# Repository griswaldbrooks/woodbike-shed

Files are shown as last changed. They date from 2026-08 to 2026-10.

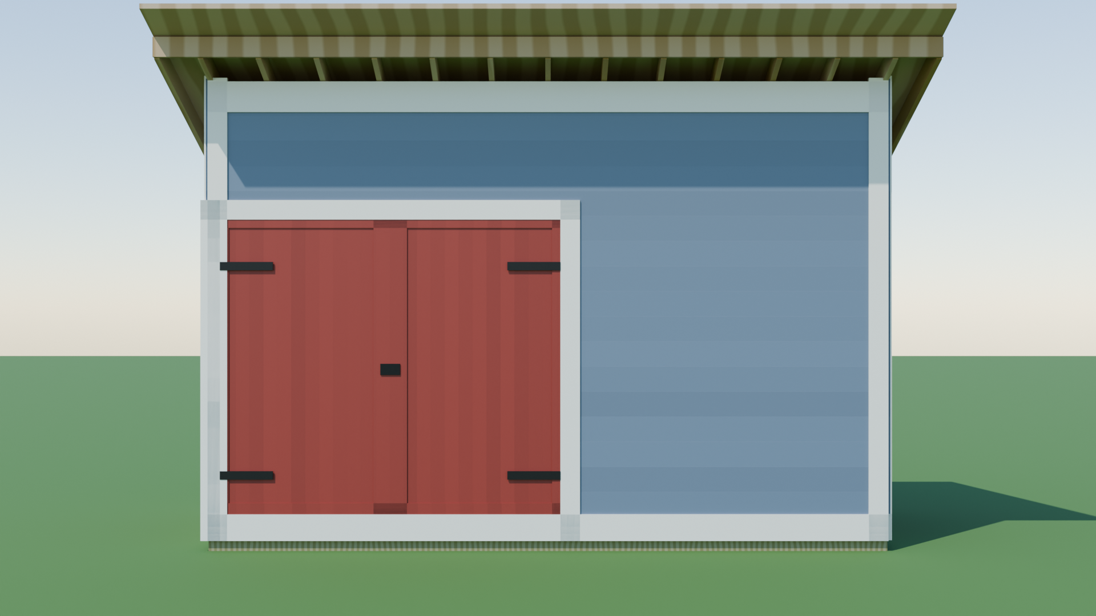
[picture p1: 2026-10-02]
blender/renders/skin/skin_front.png

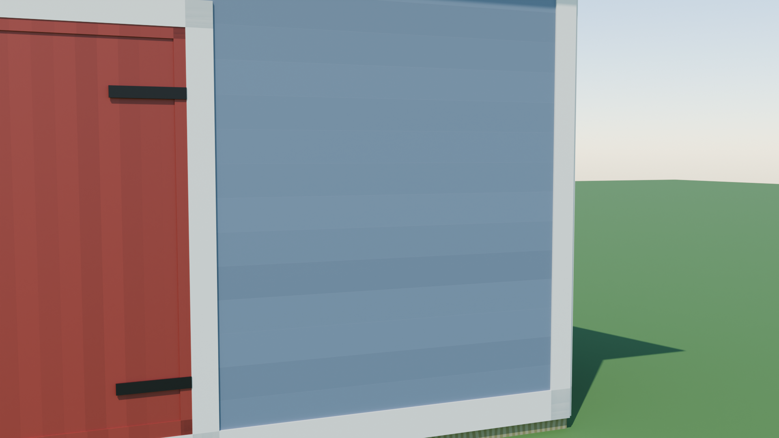
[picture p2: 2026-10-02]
blender/renders/skin/skin_door.png

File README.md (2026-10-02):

# woodbike-shed

Tooling to pull a BOM / cut list from the Onshape model of the bike shed and
prep lumber-yard RFQs.

## Build guide

The current build guide is the multi-page guide in
[`docs/guide/`](docs/guide/index.md) (PDF via `docs/guide/build-pdf.sh`).
[`docs/build-guide.html`](docs/build-guide.html) is the archived v1 single
page (6 ft shell, old door plan, old roof overhang) — kept as a record, not
build reading.

## Model as code

[`cad/`](cad/README.md) re-derives the whole shed model as build123d code
from this repo's audit data (no Onshape API calls) and exports per-part STEP
plus one named `blender/scene.glb` for renders. Build: `.venv/bin/python -m
cad.build` — verify (run after every change): `.venv/bin/python -m cad.verify`.

## Viewing (OCP CAD Viewer)

`view.py` sends the assembled model to the OCP CAD Viewer with a part tree
that mirrors `CUT_LIST.md` (one group per section, real cut-list labels):

    ~/.venvs/woodbike-shed/bin/python view.py   # from the repo root

Run it inside VS Code with the *OCP CAD Viewer* extension. `ocp_vscode` is a
viewer-side extra, deliberately not in `requirements.txt` — it lives in the
captain's `~/.venvs/woodbike-shed` venv (any venv with `ocp_vscode` works).

## Onshape document

- Name: *wood bike shed*
- URL: <https://cad.onshape.com/documents/24d3743de768051f7ae10bb3/w/4c0f1b0cf9df2e322f841b94/e/5730975eb353b57bac8d52c4>

## Credentials

API keys are stored in `~/.config/onshape/credentials` (mode `0600`, outside
this repo) as:

```
ONSHAPE_ACCESS_KEY=...
ONSHAPE_SECRET_KEY=...
```

Never commit these. The `.gitignore` blocks common credential filenames anyway.

## Key files

- [`CUT_LIST.md`](CUT_LIST.md) — full cut list grouped by section (skids,
  floor, walls, roof), with stock-length optimization.
- [`order_list.csv`](order_list.csv) — quote-ready CSV: lumber, treatment,
  stock length, qty.
- [`OUTSTANDING_ISSUES.md`](OUTSTANDING_ISSUES.md) — open items before
  sending quotes (stock availability, species, pre-cuts, waste factor, etc.).
- [`cad/`](cad/README.md) — model-as-code rebuild (build123d), per-part STEP
  exports in `step/`, Blender scene in `blender/scene.glb`.

## Scripts

- `scripts/onshape.py` — signed-request helper against `cad.onshape.com/api/v6`.
  Usage: `python3 scripts/onshape.py GET /api/v6/documents/{did}`.
- `scripts/fetch_bboxes.py` — pulls world-axis-aligned bounding boxes for every
  part in the Part Studio. Writes `scripts/bboxes.json`.
- `scripts/fetch_oriented_dims.py` — uses FeatureScript eval to get true
  oriented bounding boxes (correct for tilted parts like rafters). Writes
  `scripts/oriented_dims.json`.
- `scripts/build_cut_list.py` — builds `CUT_LIST.md` and `order_list.csv`
  from oriented dims. Classifies lumber, groups by section, assigns treatment
  (PT/KD), runs stock-length optimization with FFD bin packing.
- `scripts/verify_groups.py` — groups parts by name and flags any
  within-group dimension variance. Useful for sanity-checking the
  model after bulk-renaming.
- `scripts/fs_probe.py` — lightweight FeatureScript REPL for debugging.

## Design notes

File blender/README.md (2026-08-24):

# blender/ — headless render pipeline for the shed

`scene.glb` (273 named parts — 118 framing + 155 finish — from `cad/build.py`,
names = CUT_LIST.md labels with an `NNN ` instance prefix) +
`build_scene.py`, which turns it into a lit, materialled scene and renders
it. Nothing hand-placed: cameras, ground and sun derive from the imported
bounding box, so re-running survives model changes. `build_scene.py` drops
the `finish ` parts after import (both modes): the Blender scenes stay
framing-only presentations; the modeled finish lumber is viewed via
`view.py` (siding/trim/doors tints below).

## Regenerate (headless)

Blender is not part of the repo. Any Blender 4.x works; on this box it lives
in the task worktree scratch:

```
./.scratch/blender-4.5.12-linux-x64/blender --background --python blender/build_scene.py            # -> shed_scene.blend
./.scratch/blender-4.5.12-linux-x64/blender --background --python blender/build_scene.py -- --render  # + renders/ (Cycles 1920x1080)
./.scratch/blender-4.5.12-linux-x64/blender --background --python blender/build_scene.py -- --skin --render  # dressed variant -> shed_skin.blend + renders/skin/
```

`--render` renders all four saved cameras into `blender/renders/`.
GPU (OptiX/CUDA) is used when present, CPU otherwise.

## Skin mode (`--skin`) — render dressing, NOT modeled lumber

`--skin` layers a "finished shed" look over the framing for presentation
renders, matching the captain's reference photo: blue-gray horizontal lap
siding, white corner boards / door casings / frieze / skirt, barn-red plank
doors with black strap hinges and latches, and a natural-wood roof deck with
exposed rafter tails. Doors follow the model's actual framed openings (front
single + front double + right single), not the photo's door count.

Everything is procedural boxes/prisms aligned to wall planes and openings
read off the imported parts' world bboxes (`skin_layout()`), so like the
cameras it re-derives from `scene.glb`. `scene.glb` and the framing-only /
colorized modes are untouched; the framing model stays the source of truth.
Saves `shed_skin.blend` and renders four views (front-left 3/4 at the
reference angle, back-right, straight-on front, double-door close-up) into
`blender/renders/skin/`.

## Material-by-name-group

`group_for()` maps the cut-list label (after stripping the `NNN ` prefix) to
one material, checked in order: `sub floor osb` → deck; `skid` (incl. skid
sister); `joist` (rim/floor) → floor_frame; `rafter`; `fascia`;
`rake board` → rake; `plate`/`header` (incl. rake wall top plates) → plates;
anything else (studs, king/jack/cripple) → studs. Each group gets a distinct
wood-tinted hue (annotated-product-shot style, legend under Scene).

Each material is a Principled BSDF with a per-group base color/roughness, a
subtle Wave-texture grain in object space, and per-object brightness jitter
(Object Info → Random) so boards read individually. Tones are in the
`MATERIALS` dict at the top of `build_scene.py`.

## Scene

- Ground plane at the lowest board; Nishita sky (sun disc off) as ambient.
- One SUN lamp from front-left (~53° elevation); the sky's sun azimuth is
  matched to it.
- Cameras: `cam_front_left` / `cam_back_right` (3/4 product shots),
  `cam_interior` (axial view down the bay from the right-end door opening),
  `cam_elevation` (straight-on front, orthographic).
- Cycles 256 samples + denoise, AgX (medium-high contrast look).

### Group color legend

Approximate on-screen tints (base colors from `MATERIALS` in
`group_colors.py`, shared with `view.py` so the OCP CAD Viewer shows the
same hues; renders here are the ground truth):

| Group | Tint | Parts |
|---|---|---|
| skid | dark olive `#8E8B69` | skid (two continuous 16' 4x4) |
| floor_frame | dark amber `#A28159` | rim joist, floor joist |
| deck | golden `#CBBC81` | sub floor osb |
| studs | pale blond `#D4BCAD` | studs, king/jack/cripple studs |
| plates | honey orange `#CBA261` | plates, headers |
| rafter | cedar red `#C29079` | rafter |
| fascia | driftwood gray `#A2A4AA` | back/front fascia |
| rake | rosewood plum `#AA8195` | rake boards |
| siding | blue-gray `#6C7C90` | finish siding (view.py only) |
| trim | white `#E7E6E0` | finish corner/frieze/skirt/casings |
| doors | barn red `#906054` | finish door planks/rails |

## Known limits

- The Blender scenes render the framing only: `scene.glb` carries the modeled
  finish parts (siding/trim/doors, see `cad/README.md`) but `build_scene.py`
  drops them; `--skin` layers its own procedural dressing for the finished
  look. No roof sheathing beyond the OSB floor deck (matches CUT_LIST.md
  framing scope).

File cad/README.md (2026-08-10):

# cad/ — bike shed model-as-code

The Onshape model re-derived as code (build123d), per the scout report
`data/woodbike-shed-cadlib-scout/report.md`. Geometry flows one way out:
per-part STEP (exact record, occasional manual Onshape import) and one named
GLB for Blender renders. **No Onshape API calls anywhere in this package** —
the repo's audit files are the only model source.

## Stack (pinned in ../requirements.txt)

- Python 3.12, `build123d==0.11.1` (OCCT via cadquery-ocp-novtk 7.9.3), `trimesh`
- Setup: `uv venv --python 3.12 .venv && uv pip install -r requirements.txt`

## Commands (from repo root)

| Command | Effect |
|---|---|
| `.venv/bin/python -m cad.build` | Rebuild all parts, write `step/*.step` + `blender/scene.glb` |
| `.venv/bin/python -m cad.verify` | Assertion harness — **run after every change** |

## Sources of truth

- `scripts/oriented_dims.json` — part names (== CUT_LIST.md labels) + edge dims
- `scripts/bboxes.json` — world bounding boxes (placement)
- `CUT_LIST.md` / `OUTSTANDING_ISSUES.md` — cross-checks and open items
- Roof pitch is *derived from the plate solids* (`cad.common.roof_ref`:
  front double top plate bottom at the front wall inner face -> back double
  top plate top at the back wall inner face), sanity-checked against the
  documented 24.375/65 slope (~20.56°). The audit data reflects the
  2026-08-10 restud to 92-5/8" pre-cut studs (`scripts/restud_92_5_8.py` —
  full derivation record); the pre-restud slope was 24/65 (~20.26°, see
  MANUAL_COMPLETION.md). Wall-height edits propagate: seats, kicks, mitres
  and the pitch all re-derive from the plates.

## Layout

One module per shed section; `cad/common.py` loads the audit data and places
parts. Axis-aligned parts are AABB boxes (`place_box`); the roof/rake
members (rafters, rake boards, rake plates, rake studs) are exact YZ-profile
prisms (`prism_yz`, `roof_ref`) carrying the audited birdsmouth/seat/kick/
mitre/end cuts, anchored on their own world coordinates (never re-centered
on an AABB):

`skids.py` `floor.py` `walls_front.py` `walls_back.py` `walls_side.py`
`walls_rake.py` `roof.py` → orchestrated by `build.py`, checked by `verify.py`.

Finish lumber (captain 2026-08-10: modeled for real, SEPARATE order list) is
`siding.py` (1x8 lap courses, rabbet-nested, rake-cut tops), `trim.py`
(skirt/corners/frieze/casings), `doors.py` (board-and-batten leaves over the
framed openings) → `build.py build_finish()`, checked by the same
`verify.py` run (volumes, layer planes, envelope, zero interference against
the framing too). Their heights derive from `common.finish_layout` (audit
bboxes + roof_ref); only product dims are constants. Labels use a `finish `
prefix so `scripts/build_cut_list.section_for` files them under the Finish
sections and `scripts/build_finish_cut_list.py` orders them separately.

Naming scheme: every part's `.label` matches CUT_LIST.md exactly. STEP
filenames and glTF node names are `NNN <label>` (instance number prefix for
uniqueness — group names repeat, e.g. 14 × "back wall studs").

## build123d trap rules (learned empirically — do not break)

1. **Location tuple form only**: `Location((x,y,z), (rx,ry,rz))`.
   `Location(Pos(...), Rot(...))` constructs without error but **silently
   drops the rotation** — parts build in the wrong pose. All placement in
   `common.py` uses the tuple form; keep it that way.
2. **`export_step` takes ONE shape** — pass parts one at a time, never a
   list (`'list' object has no attribute 'wrapped'`). Also: build123d
   `Compound` drops child labels, so a single-file named STEP assembly is
   not available; per-part files are the workable path.
3. build123d `export_gltf` writes JSON glTF even for `.glb` unless
   `binary=True` — this repo exports meshes via trimesh instead (always
   binary GLB, names verified in Blender 4.5 LTS: one selectable object per
   part).
4. **build123d builds in mm**: `prism_yz` takes inch profiles and scales
   them at the boundary. Feeding raw inch points to `Polygon` builds a part
   25.4x too small without any error.

## Pending captain decisions (TODO seams, do not decide unilaterally)

(none open)

Resolved seams (kept for the record):
- **Doors/siding/trim** — implemented 2026-08-10 as real parts
  (`siding.py`/`trim.py`/`doors.py`) on a separate order list
  (`order_list_finish.csv`), per the captain's decision; hardware stays line
  items only.
- **Birdsmouth/trim cuts in code** — implemented 2026-08-10
  (`roof.py`/`walls_rake.py` prisms, `verify.py` seating gate). The old
  rectangular-stock approximation silently interpenetrated both double top
  plates by up to 1.5"; diagnosis record: firstmate report
  `woodbike-shed-birdsmouth-scout/report.md`.
- **Rake-plate end/nose cuts** — implemented with the plate prisms.
- **Skid composites** — superseded by the captain's 2026-08-10 skid
  redesign (two continuous 16' 4x4 lines; OUTSTANDING_ISSUES.md "Skid
  redesign").

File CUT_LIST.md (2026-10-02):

# Bike shed cut list

Source: Onshape "wood bike shed" Part Studio 1 audit data, as re-derived
locally 2026-08-10 for the 92-5/8" pre-cut stud decision
(scripts/restud_92_5_8.py) and the captain's skid redesign (two
continuous 16' 4x4 lines, sisters dropped), then 2026-08-23/24 for the
7 ft depth + adopted door plan (scripts/depth7ft_2door.py + scripts/
left_main_door.py: barn 8 ft front, LEFT rake-wall 64 in MAIN entry,
RIGHT rake-wall 64 in brewery; skids bear direct on the gravel pad).
The Onshape model still carries the pre-decision geometry. Actual dimensions.

- **Yard: Hingham Lumber** — KD framing species **SPF #2**; stocks 16' 2x4,
  16' 4x4 and true 20' 2x6. Quantities are EXACT (0% overage) per the
  captain — plan a follow-up run for shortages.
- **PT** = pressure-treated, ground-contact rated (skids + floor system)
- **KD** = kiln-dried dimensional lumber, framing grade, SPF #2
- Back/left/right wall studs: **88-1/8" pre-cut** studs (7 ft depth:
  plate tops 92-5/8" above the deck; roof re-derived about the
  unchanged front wall). Front wall studs stay 118-1/2" (tall wall).
- Saw kerf allowance: 1/8" per cut (used in stock-length optimization)

## Skids

| Qty | Lumber | Treatment | Length | Name |
|---:|:---|:---:|---:|:---|
| 2 | 4x4 | PT | 16′ 0″ (192″) | skid |

## Floor

| Qty | Lumber | Treatment | Length | Name |
|---:|:---|:---:|---:|:---|
| 2 | 2x6 | PT | 16′ 0″ (192″) | rim joist |
| 14 | 2x6 | PT | 6′ 9″ (81″) | floor joist |
| 4 | OSB 3/4" 4x8 (half sheets used) | — | 84″ × 48″ | sub floor osb |

## Back wall

| Qty | Lumber | Treatment | Length | Name |
|---:|:---|:---:|---:|:---|
| 1 | 2x4 | KD | 16′ 0″ (192″) | back wall bottom plate |
| 1 | 2x4 | KD | 16′ 0″ (192″) | back wall top plate |
| 1 | 2x4 | KD | 15′ 5″ (185″) | back wall double top plate short |
| 13 | 2x4 | KD | 7′ 4.125″ (88.125″) | back wall studs |

## Front wall

| Qty | Lumber | Treatment | Length | Name |
|---:|:---|:---:|---:|:---|
| 1 | 2x4 | KD | 16′ 0″ (192″) | front wall bottom plate |
| 1 | 2x4 | KD | 16′ 0″ (192″) | front wall double top plate |
| 1 | 2x4 | KD | 16′ 0″ (192″) | front wall top plate |
| 8 | 2x4 | KD | 9′ 10.5″ (118.5″) | front wall king studs |
| 3 | 2x4 | KD | 8′ 3″ (99″) | front wall headers |
| 2 | 2x4 | KD | 6′ 10.5″ (82.5″) | front wall jack studs |
| 5 | 2x4 | KD | 2′ 7″ (31″) | front wall cripple studs |

## Left wall

| Qty | Lumber | Treatment | Length | Name |
|---:|:---|:---:|---:|:---|
| 1 | 2x4 | KD | 7′ 8.625″ (92.625″) | left side wall studs |
| 1 | 2x4 | KD | 7′ 4.125″ (88.125″) | left side wall studs |
| 2 | 2x4 | KD | 6′ 10.5″ (82.5″) | left wall jack studs |
| 3 | 2x4 | KD | 5′ 7″ (67″) | left wall headers |
| 1 | 2x4 | KD | 5′ 4.728″ (64.728″) | left wall top plate |
| 1 | 2x4 | KD | 5′ 0.728″ (60.728″) | left wall double top plate |
| 1 | 2x4 | KD | 0′ 6.5″ (6.5″) | left wall bottom plate long |
| 1 | 2x4 | KD | 0′ 6.5″ (6.5″) | left wall bottom plate short |
| 3 | 2x4 | KD | 0′ 5.125″ (5.125″) | left wall cripple studs |
| 1 | 2x4 | KD | 0′ 3.5″ (3.5″) | left wall double top plate |

## Right wall

| Qty | Lumber | Treatment | Length | Name |
|---:|:---|:---:|---:|:---|
| 1 | 2x4 | KD | 7′ 8.625″ (92.625″) | right wall studs |
| 1 | 2x4 | KD | 7′ 4.125″ (88.125″) | right wall studs |
| 2 | 2x4 | KD | 6′ 10.5″ (82.5″) | right wall jack studs |
| 3 | 2x4 | KD | 5′ 7″ (67″) | right wall headers |
| 1 | 2x4 | KD | 5′ 4.728″ (64.728″) | right wall top plate |
| 1 | 2x4 | KD | 5′ 0.728″ (60.728″) | right wall double top plate |
| 1 | 2x4 | KD | 0′ 6.5″ (6.5″) | right wall bottom plate long |
| 1 | 2x4 | KD | 0′ 6.5″ (6.5″) | right wall bottom plate short |
| 3 | 2x4 | KD | 0′ 5.125″ (5.125″) | right wall cripple studs |
| 1 | 2x4 | KD | 0′ 3.5″ (3.5″) | right wall double top plate |

## Left rake wall

| Qty | Lumber | Treatment | Length | Name |
|---:|:---|:---:|---:|:---|
| 2 | 2x4 | KD | 7′ 7.125″ (91.125″) | left rake wall studs |
| 1 | 2x4 | KD | 6′ 10.236″ (82.236″) | left rake wall top plate |
| 1 | 2x4 | KD | 1′ 10.773″ (22.773″) | left rake wall studs |
| 1 | 2x4 | KD | 1′ 4.96″ (16.96″) | left rake wall studs |
| 1 | 2x4 | KD | 0′ 10.96″ (10.96″) | left rake wall studs |
| 1 | 2x4 | KD | 0′ 6.335″ (6.335″) | left rake wall studs |
| 1 | 2x4 | KD | 0′ 5.21″ (5.21″) | left rake wall studs |
| 1 | 2x4 | KD | 0′ 4.96″ (4.96″) | left rake wall studs |

## Right rake wall

| Qty | Lumber | Treatment | Length | Name |
|---:|:---|:---:|---:|:---|
| 2 | 2x4 | KD | 7′ 7.125″ (91.125″) | right rake wall studs |
| 1 | 2x4 | KD | 6′ 10.236″ (82.236″) | right rake wall top plate |
| 1 | 2x4 | KD | 1′ 10.773″ (22.773″) | right rake wall studs |
| 1 | 2x4 | KD | 1′ 4.96″ (16.96″) | right rake wall studs |
| 1 | 2x4 | KD | 0′ 10.96″ (10.96″) | right rake wall studs |
| 1 | 2x4 | KD | 0′ 6.335″ (6.335″) | right rake wall studs |
| 1 | 2x4 | KD | 0′ 5.21″ (5.21″) | right rake wall studs |
| 1 | 2x4 | KD | 0′ 4.96″ (4.96″) | right rake wall studs |

## Roof

| Qty | Lumber | Treatment | Length | Name |
|---:|:---|:---:|---:|:---|
| 1 | 2x6 | KD | 18′ 0″ (216″) | back fascia |
| 1 | 2x6 | KD | 18′ 0″ (216″) | front fascia |
| 1 | 2x6 | KD | 9′ 7.344″ (115.344″) | left rake board |
| 13 | 2x6 | KD | 9′ 7.344″ (115.344″) | rafter |
| 1 | 2x6 | KD | 9′ 7.344″ (115.344″) | right rake board |

## Stock-length order list

First-fit-decreasing bin packing, one pass per (lumber, treatment). For each group, the stock length shown minimizes total linear feet purchased. Kerf: 1/8" per cut.

### 2x4 KD — order **1 × 8′, 31 × 16′** (504.0 LF purchased, 493.9 LF cuts, 2.0% waste)

- Board 1 (16′): 192″ front wall top plate (Front wall)  — waste: 0.00″
- Board 2 (16′): 192″ front wall bottom plate (Front wall)  — waste: 0.00″
- Board 3 (16′): 192″ front wall double top plate (Front wall)  — waste: 0.00″
- Board 4 (16′): 192″ back wall bottom plate (Back wall)  — waste: 0.00″
- Board 5 (16′): 192″ back wall top plate (Back wall)  — waste: 0.00″
- Board 6 (16′): 185″ back wall double top plate short (Back wall); 6.5″ right wall bottom plate short (Right wall)  — waste: 0.38″
- Board 7 (16′): 118.5″ front wall king studs (Front wall); 67″ right wall headers (Right wall); 5.21″ right rake wall studs (Right rake wall)  — waste: 1.04″
- Board 8 (16′): 118.5″ front wall king studs (Front wall); 67″ right wall headers (Right wall); 5.21″ left rake wall studs (Left rake wall)  — waste: 1.04″
- Board 9 (16′): 118.5″ front wall king studs (Front wall); 67″ right wall headers (Right wall); 5.125″ right wall cripple studs (Right wall)  — waste: 1.12″
- Board 10 (16′): 118.5″ front wall king studs (Front wall); 67″ left wall headers (Left wall); 5.125″ right wall cripple studs (Right wall)  — waste: 1.12″
- Board 11 (16′): 118.5″ front wall king studs (Front wall); 67″ left wall headers (Left wall); 5.125″ right wall cripple studs (Right wall)  — waste: 1.12″
- Board 12 (16′): 118.5″ front wall king studs (Front wall); 67″ left wall headers (Left wall); 5.125″ left wall cripple studs (Left wall)  — waste: 1.12″
- Board 13 (16′): 118.5″ front wall king studs (Front wall); 64.728″ left wall top plate (Left wall); 6.5″ right wall bottom plate long (Right wall)  — waste: 2.02″
- Board 14 (16′): 118.5″ front wall king studs (Front wall); 64.728″ right wall top plate (Right wall); 6.5″ left wall bottom plate short (Left wall)  — waste: 2.02″
- Board 15 (16′): 99″ front wall headers (Front wall); 92.625″ right wall studs (Right wall)  — waste: 0.25″
- Board 16 (16′): 99″ front wall headers (Front wall); 92.625″ left side wall studs (Left wall)  — waste: 0.25″
- Board 17 (16′): 99″ front wall headers (Front wall); 91.125″ right rake wall studs (Right rake wall)  — waste: 1.75″
- Board 18 (16′): 91.125″ right rake wall studs (Right rake wall); 91.125″ left rake wall studs (Left rake wall); 6.5″ left wall bottom plate long (Left wall)  — waste: 3.00″
- Board 19 (16′): 91.125″ left rake wall studs (Left rake wall); 88.125″ back wall studs (Back wall); 10.96″ right rake wall studs (Right rake wall)  — waste: 1.54″
- Board 20 (16′): 88.125″ back wall studs (Back wall); 88.125″ back wall studs (Back wall); 10.96″ left rake wall studs (Left rake wall); 3.5″ left wall double top plate (Left wall)  — waste: 0.91″
- Board 21 (16′): 88.125″ back wall studs (Back wall); 88.125″ back wall studs (Back wall); 6.335″ right rake wall studs (Right rake wall); 6.335″ left rake wall studs (Left rake wall)  — waste: 2.70″
- Board 22 (16′): 88.125″ back wall studs (Back wall); 88.125″ back wall studs (Back wall); 5.125″ left wall cripple studs (Left wall); 5.125″ left wall cripple studs (Left wall); 4.96″ right rake wall studs (Right rake wall)  — waste: 0.04″
- Board 23 (16′): 88.125″ back wall studs (Back wall); 88.125″ back wall studs (Back wall); 4.96″ left rake wall studs (Left rake wall); 3.5″ right wall double top plate (Right wall)  — waste: 6.91″
- Board 24 (16′): 88.125″ back wall studs (Back wall); 88.125″ back wall studs (Back wall)  — waste: 15.62″
- Board 25 (16′): 88.125″ back wall studs (Back wall); 88.125″ back wall studs (Back wall)  — waste: 15.62″
- Board 26 (16′): 88.125″ right wall studs (Right wall); 88.125″ left side wall studs (Left wall)  — waste: 15.62″
- Board 27 (16′): 82.5″ front wall jack studs (Front wall); 82.5″ front wall jack studs (Front wall); 22.773″ right rake wall studs (Right rake wall)  — waste: 3.98″
- Board 28 (16′): 82.5″ right wall jack studs (Right wall); 82.5″ right wall jack studs (Right wall); 22.773″ left rake wall studs (Left rake wall)  — waste: 3.98″
- Board 29 (16′): 82.5″ left wall jack studs (Left wall); 82.5″ left wall jack studs (Left wall); 16.96″ right rake wall studs (Right rake wall)  — waste: 9.79″
- Board 30 (16′): 82.236″ left rake wall top plate (Left rake wall); 82.236″ right rake wall top plate (Right rake wall); 16.96″ left rake wall studs (Left rake wall)  — waste: 10.32″
- Board 31 (16′): 60.728″ left wall double top plate (Left wall); 60.728″ right wall double top plate (Right wall); 31″ front wall cripple studs (Front wall); 31″ front wall cripple studs (Front wall)  — waste: 8.17″
- Board 32 (8′): 31″ front wall cripple studs (Front wall); 31″ front wall cripple studs (Front wall); 31″ front wall cripple studs (Front wall)  — waste: 2.75″

### 2x6 KD — order **15 × 10′, 2 × 20′** (190.0 LF purchased, 180.2 LF cuts, 5.2% waste)

- Board 1 (20′): 216″ front fascia (Roof) — TOO LONG FOR 96"  — waste: 24.00″
- Board 2 (20′): 216″ back fascia (Roof) — TOO LONG FOR 96"  — waste: 24.00″
- Board 3 (10′): 115.344″ rafter (Roof) — TOO LONG FOR 96"  — waste: 4.66″
- Board 4 (10′): 115.344″ rafter (Roof) — TOO LONG FOR 96"  — waste: 4.66″
- Board 5 (10′): 115.344″ rafter (Roof) — TOO LONG FOR 96"  — waste: 4.66″
- Board 6 (10′): 115.344″ rafter (Roof) — TOO LONG FOR 96"  — waste: 4.66″
- Board 7 (10′): 115.344″ rafter (Roof) — TOO LONG FOR 96"  — waste: 4.66″
- Board 8 (10′): 115.344″ rafter (Roof) — TOO LONG FOR 96"  — waste: 4.66″
- Board 9 (10′): 115.344″ rafter (Roof) — TOO LONG FOR 96"  — waste: 4.66″
- Board 10 (10′): 115.344″ rafter (Roof) — TOO LONG FOR 96"  — waste: 4.66″
- Board 11 (10′): 115.344″ rafter (Roof) — TOO LONG FOR 96"  — waste: 4.66″
- Board 12 (10′): 115.344″ rafter (Roof) — TOO LONG FOR 96"  — waste: 4.66″
- Board 13 (10′): 115.344″ rafter (Roof) — TOO LONG FOR 96"  — waste: 4.66″
- Board 14 (10′): 115.344″ rafter (Roof) — TOO LONG FOR 96"  — waste: 4.66″
- Board 15 (10′): 115.344″ rafter (Roof) — TOO LONG FOR 96"  — waste: 4.66″
- Board 16 (10′): 115.344″ left rake board (Roof) — TOO LONG FOR 96"  — waste: 4.66″
- Board 17 (10′): 115.344″ right rake board (Roof) — TOO LONG FOR 96"  — waste: 4.66″

### 2x6 PT — order **7 × 14′, 2 × 16′** (130.0 LF purchased, 126.5 LF cuts, 2.7% waste)

- Board 1 (16′): 192″ rim joist (Floor) — TOO LONG FOR 168"  — waste: 0.00″
- Board 2 (16′): 192″ rim joist (Floor) — TOO LONG FOR 168"  — waste: 0.00″
- Board 3 (14′): 81″ floor joist (Floor); 81″ floor joist (Floor)  — waste: 5.88″
- Board 4 (14′): 81″ floor joist (Floor); 81″ floor joist (Floor)  — waste: 5.88″
- Board 5 (14′): 81″ floor joist (Floor); 81″ floor joist (Floor)  — waste: 5.88″
- Board 6 (14′): 81″ floor joist (Floor); 81″ floor joist (Floor)  — waste: 5.88″
- Board 7 (14′): 81″ floor joist (Floor); 81″ floor joist (Floor)  — waste: 5.88″
- Board 8 (14′): 81″ floor joist (Floor); 81″ floor joist (Floor)  — waste: 5.88″
- Board 9 (14′): 81″ floor joist (Floor); 81″ floor joist (Floor)  — waste: 5.88″

### 4x4 PT — order **2 × 16′** (32.0 LF purchased, 32.0 LF cuts, 0.0% waste)

- Board 1 (16′): 192″ skid (Skids) — TOO LONG FOR 96"  — waste: 0.00″
- Board 2 (16′): 192″ skid (Skids) — TOO LONG FOR 96"  — waste: 0.00″

### OSB 3/4" 4×8 sheets

4 panels (84"×48") needed → **order 4 full 4×8 sheets**, rip to 84"+12" offcut.

---

**Total dimensional lumber LF purchased: 856.0**
---

# FINISH — SEPARATE ORDER LIST (order_list_finish.csv)

Captain 2026-08-10: doors/siding/trim modeled for real in
`cad/siding.py`, `cad/trim.py`, `cad/doors.py` but ordered on a
completely separate list - never mixed with the framing lumber
above. Rows derive from the built finish parts. Hardware has no
geometry; line items only.

## Finish siding

| Qty | Lumber | Treatment | Length | Name |
|---:|:---|:---:|---:|:---|
| 13 | 1x8 | PRIMED | 16′ 0″ (192″) | finish siding back |
| 6 | 1x8 | PRIMED | 16′ 0″ (192″) | finish siding front |
| 12 | 1x8 | PRIMED | 7′ 8.5″ (92.5″) | finish siding front |
| 2 | 1x8 | PRIMED | 7′ 0″ (84″) | finish siding left |
| 2 | 1x8 | PRIMED | 7′ 0″ (84″) | finish siding right |
| 1 | 1x8 | PRIMED | 5′ 6.167″ (66.167″) | finish siding left |
| 1 | 1x8 | PRIMED | 5′ 6.167″ (66.167″) | finish siding right |
| 1 | 1x8 | PRIMED | 3′ 10.167″ (46.167″) | finish siding left |
| 1 | 1x8 | PRIMED | 3′ 10.167″ (46.167″) | finish siding right |
| 1 | 1x8 | PRIMED | 2′ 2.167″ (26.167″) | finish siding left |
| 1 | 1x8 | PRIMED | 2′ 2.167″ (26.167″) | finish siding right |
| 24 | 1x8 | PRIMED | 0′ 10″ (10″) | finish siding left |
| 24 | 1x8 | PRIMED | 0′ 10″ (10″) | finish siding right |
| 1 | 1x8 | PRIMED | 0′ 6.167″ (6.167″) | finish siding left |
| 1 | 1x8 | PRIMED | 0′ 6.167″ (6.167″) | finish siding right |
| 12 | 1x8 | PRIMED | 0′ 3.5″ (3.5″) | finish siding front |

## Finish trim

| Qty | Lumber | Treatment | Length | Name |
|---:|:---|:---:|---:|:---|
| 2 | 1x10 | PRIMED | 15′ 1″ (181″) | finish frieze |
| 2 | 1x10 | PRIMED | 6′ 1″ (73″) | finish frieze |
| 2 | 1x6 | PRIMED | 10′ 3.313″ (123.313″) | finish corner boards |
| 2 | 1x6 | PRIMED | 10′ 2.5″ (122.5″) | finish corner boards |
| 1 | 1x6 | PRIMED | 8′ 3.5″ (99.5″) | finish door casings |
| 2 | 1x6 | PRIMED | 7′ 7.813″ (91.813″) | finish corner boards |
| 2 | 1x6 | PRIMED | 7′ 6.25″ (90.25″) | finish corner boards |
| 5 | 1x6 | PRIMED | 6′ 11.5″ (83.5″) | finish door casings |
| 2 | 1x6 | PRIMED | 6′ 1″ (73″) | finish door casings |
| 2 | 1x8 | PRIMED | 16′ 0″ (192″) | finish skirt |
| 2 | 1x8 | PRIMED | 7′ 0″ (84″) | finish skirt |

## Finish doors

| Qty | Lumber | Treatment | Length | Name |
|---:|:---|:---:|---:|:---|
| 12 | 1x4 | KD | 6′ 10.75″ (82.75″) | finish door rails |
| 4 | 1x4 | KD | 3′ 6.375″ (42.375″) | finish door rails |
| 8 | 1x4 | KD | 2′ 2.375″ (26.375″) | finish door rails |
| 46 | 1x6 | KD | 6′ 10.75″ (82.75″) | finish door planks |

## Finish hardware (no geometry)

| Qty | Item | Note |
|---:|:---|:---|
| 12 | strap hinge 12" black | 2 per leaf, 6 leaves |
| 3 | gate latch + hasp black | 1 per opening (double: center latch) |

## Finish stock-length order list

Same first-fit-decreasing packing as the framing list (kerf 0.125"): 

### 1x10 PRIMED — order **1 × 14′, 2 × 16′** (46.0 LF purchased, 42.3 LF cuts, 8.0% waste)

- Board 1 (16′): 181″ finish frieze — TOO LONG FOR 168"  — waste: 11.00″
- Board 2 (16′): 181″ finish frieze — TOO LONG FOR 168"  — waste: 11.00″
- Board 3 (14′): 73″ finish frieze; 73″ finish frieze  — waste: 21.88″

### 1x4 KD — order **1 × 8′, 8 × 14′** (120.0 LF purchased, 114.5 LF cuts, 4.6% waste)

- Board 1 (14′): 82.75″ finish door rails; 82.75″ finish door rails  — waste: 2.38″
- Board 2 (14′): 82.75″ finish door rails; 82.75″ finish door rails  — waste: 2.38″
- Board 3 (14′): 82.75″ finish door rails; 82.75″ finish door rails  — waste: 2.38″
- Board 4 (14′): 82.75″ finish door rails; 82.75″ finish door rails  — waste: 2.38″
- Board 5 (14′): 82.75″ finish door rails; 82.75″ finish door rails  — waste: 2.38″
- Board 6 (14′): 82.75″ finish door rails; 82.75″ finish door rails  — waste: 2.38″
- Board 7 (14′): 42.375″ finish door rails; 42.375″ finish door rails; 42.375″ finish door rails; 26.375″ finish door rails  — waste: 14.12″
- Board 8 (14′): 42.375″ finish door rails; 26.375″ finish door rails; 26.375″ finish door rails; 26.375″ finish door rails; 26.375″ finish door rails  — waste: 19.62″
- Board 9 (8′): 26.375″ finish door rails; 26.375″ finish door rails; 26.375″ finish door rails  — waste: 16.62″

### 1x6 KD — order **23 × 14′** (322.0 LF purchased, 317.2 LF cuts, 1.5% waste)

- Board 1 (14′): 82.75″ finish door planks; 82.75″ finish door planks  — waste: 2.38″
- Board 2 (14′): 82.75″ finish door planks; 82.75″ finish door planks  — waste: 2.38″
- Board 3 (14′): 82.75″ finish door planks; 82.75″ finish door planks  — waste: 2.38″
- Board 4 (14′): 82.75″ finish door planks; 82.75″ finish door planks  — waste: 2.38″
- Board 5 (14′): 82.75″ finish door planks; 82.75″ finish door planks  — waste: 2.38″
- Board 6 (14′): 82.75″ finish door planks; 82.75″ finish door planks  — waste: 2.38″
- Board 7 (14′): 82.75″ finish door planks; 82.75″ finish door planks  — waste: 2.38″
- Board 8 (14′): 82.75″ finish door planks; 82.75″ finish door planks  — waste: 2.38″
- Board 9 (14′): 82.75″ finish door planks; 82.75″ finish door planks  — waste: 2.38″
- Board 10 (14′): 82.75″ finish door planks; 82.75″ finish door planks  — waste: 2.38″
- Board 11 (14′): 82.75″ finish door planks; 82.75″ finish door planks  — waste: 2.38″
- Board 12 (14′): 82.75″ finish door planks; 82.75″ finish door planks  — waste: 2.38″
- Board 13 (14′): 82.75″ finish door planks; 82.75″ finish door planks  — waste: 2.38″
- Board 14 (14′): 82.75″ finish door planks; 82.75″ finish door planks  — waste: 2.38″
- Board 15 (14′): 82.75″ finish door planks; 82.75″ finish door planks  — waste: 2.38″
- Board 16 (14′): 82.75″ finish door planks; 82.75″ finish door planks  — waste: 2.38″
- Board 17 (14′): 82.75″ finish door planks; 82.75″ finish door planks  — waste: 2.38″
- Board 18 (14′): 82.75″ finish door planks; 82.75″ finish door planks  — waste: 2.38″
- Board 19 (14′): 82.75″ finish door planks; 82.75″ finish door planks  — waste: 2.38″
- Board 20 (14′): 82.75″ finish door planks; 82.75″ finish door planks  — waste: 2.38″
- Board 21 (14′): 82.75″ finish door planks; 82.75″ finish door planks  — waste: 2.38″
- Board 22 (14′): 82.75″ finish door planks; 82.75″ finish door planks  — waste: 2.38″
- Board 23 (14′): 82.75″ finish door planks; 82.75″ finish door planks  — waste: 2.38″

### 1x6 PRIMED — order **3 × 8′, 1 × 10′, 4 × 12′, 4 × 14′** (138.0 LF purchased, 126.6 LF cuts, 8.3% waste)

- Board 1 (12′): 123.313″ finish corner boards  — waste: 20.69″
- Board 2 (12′): 123.313″ finish corner boards  — waste: 20.69″
- Board 3 (12′): 122.5″ finish corner boards  — waste: 21.50″
- Board 4 (12′): 122.5″ finish corner boards  — waste: 21.50″
- Board 5 (10′): 99.5″ finish door casings  — waste: 20.50″
- Board 6 (14′): 91.813″ finish corner boards; 73″ finish door casings  — waste: 3.06″
- Board 7 (14′): 91.813″ finish corner boards; 73″ finish door casings  — waste: 3.06″
- Board 8 (8′): 90.25″ finish corner boards  — waste: 5.75″
- Board 9 (8′): 90.25″ finish corner boards  — waste: 5.75″
- Board 10 (14′): 83.5″ finish door casings; 83.5″ finish door casings  — waste: 0.88″
- Board 11 (14′): 83.5″ finish door casings; 83.5″ finish door casings  — waste: 0.88″
- Board 12 (8′): 83.5″ finish door casings  — waste: 12.50″

### 1x8 PRIMED — order **1 × 14′, 33 × 16′** (542.0 LF purchased, 538.1 LF cuts, 0.7% waste)

- Board 1 (16′): 192″ finish siding front  — waste: 0.00″
- Board 2 (16′): 192″ finish siding front  — waste: 0.00″
- Board 3 (16′): 192″ finish siding front  — waste: 0.00″
- Board 4 (16′): 192″ finish siding front  — waste: 0.00″
- Board 5 (16′): 192″ finish siding front  — waste: 0.00″
- Board 6 (16′): 192″ finish siding front  — waste: 0.00″
- Board 7 (16′): 192″ finish siding back  — waste: 0.00″
- Board 8 (16′): 192″ finish siding back  — waste: 0.00″
- Board 9 (16′): 192″ finish siding back  — waste: 0.00″
- Board 10 (16′): 192″ finish siding back  — waste: 0.00″
- Board 11 (16′): 192″ finish siding back  — waste: 0.00″
- Board 12 (16′): 192″ finish siding back  — waste: 0.00″
- Board 13 (16′): 192″ finish siding back  — waste: 0.00″
- Board 14 (16′): 192″ finish siding back  — waste: 0.00″
- Board 15 (16′): 192″ finish siding back  — waste: 0.00″
- Board 16 (16′): 192″ finish siding back  — waste: 0.00″
- Board 17 (16′): 192″ finish siding back  — waste: 0.00″
- Board 18 (16′): 192″ finish siding back  — waste: 0.00″
- Board 19 (16′): 192″ finish siding back  — waste: 0.00″
- Board 20 (16′): 192″ finish skirt  — waste: 0.00″
- Board 21 (16′): 192″ finish skirt  — waste: 0.00″
- Board 22 (16′): 92.5″ finish siding front; 92.5″ finish siding front; 6.167″ finish siding left  — waste: 0.58″
- Board 23 (16′): 92.5″ finish siding front; 92.5″ finish siding front; 6.167″ finish siding right  — waste: 0.58″
- Board 24 (16′): 92.5″ finish siding front; 92.5″ finish siding front; 3.5″ finish siding front  — waste: 3.25″
- Board 25 (16′): 92.5″ finish siding front; 92.5″ finish siding front; 3.5″ finish siding front  — waste: 3.25″
- Board 26 (16′): 92.5″ finish siding front; 92.5″ finish siding front; 3.5″ finish siding front  — waste: 3.25″
- Board 27 (16′): 92.5″ finish siding front; 92.5″ finish siding front; 3.5″ finish siding front  — waste: 3.25″
- Board 28 (16′): 84″ finish siding left; 84″ finish siding left; 10″ finish siding left; 10″ finish siding left; 3.5″ finish siding front  — waste: 0.00″
- Board 29 (16′): 84″ finish siding right; 84″ finish siding right; 10″ finish siding left; 10″ finish siding left; 3.5″ finish siding front  — waste: 0.00″
- Board 30 (16′): 84″ finish skirt; 84″ finish skirt; 10″ finish siding left; 10″ finish siding left; 3.5″ finish siding front  — waste: 0.00″
- Board 31 (16′): 66.167″ finish siding left; 66.167″ finish siding right; 46.167″ finish siding left; 10″ finish siding left  — waste: 3.12″
- Board 32 (16′): 46.167″ finish siding right; 26.167″ finish siding left; 26.167″ finish siding right; 10″ finish siding left; 10″ finish siding left; 10″ finish siding left; 10″ finish siding left; 10″ finish siding left; 10″ finish siding left; 10″ finish siding left; 10″ finish siding left; 10″ finish siding left  — waste: 2.12″
- Board 33 (16′): 10″ finish siding left; 10″ finish siding left; 10″ finish siding left; 10″ finish siding left; 10″ finish siding left; 10″ finish siding left; 10″ finish siding left; 10″ finish siding left; 10″ finish siding right; 10″ finish siding right; 10″ finish siding right; 10″ finish siding right; 10″ finish siding right; 10″ finish siding right; 10″ finish siding right; 10″ finish siding right; 10″ finish siding right; 10″ finish siding right; 3.5″ finish siding front; 3.5″ finish siding front  — waste: 2.62″
- Board 34 (14′): 10″ finish siding right; 10″ finish siding right; 10″ finish siding right; 10″ finish siding right; 10″ finish siding right; 10″ finish siding right; 10″ finish siding right; 10″ finish siding right; 10″ finish siding right; 10″ finish siding right; 10″ finish siding right; 10″ finish siding right; 10″ finish siding right; 10″ finish siding right; 3.5″ finish siding front; 3.5″ finish siding front; 3.5″ finish siding front  — waste: 15.50″

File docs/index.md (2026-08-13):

---
layout: landing
title: Start here
---

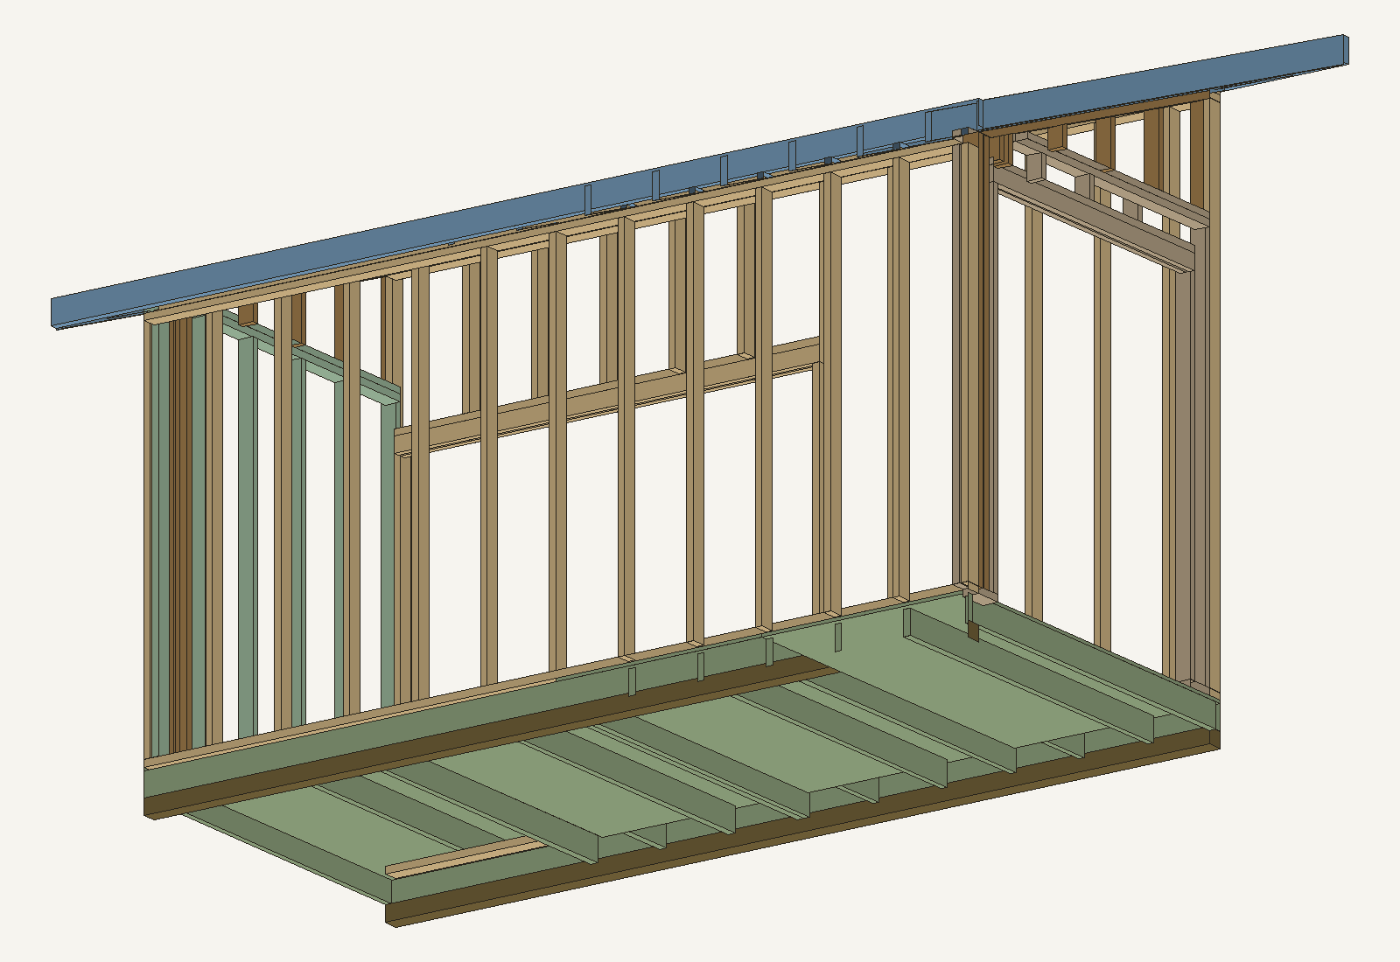
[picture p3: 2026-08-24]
renders/shed-iso-front.png

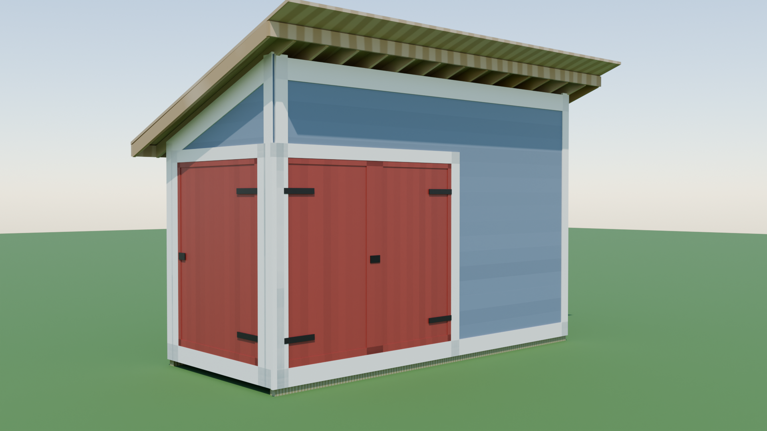
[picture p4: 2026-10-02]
blender/renders/skin/skin_front_left.png

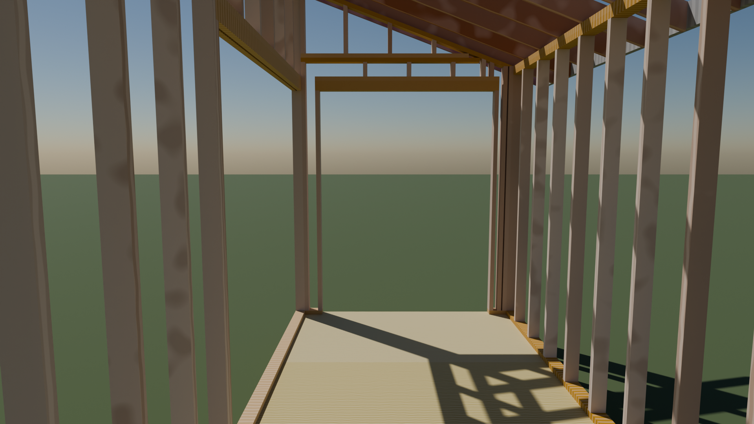
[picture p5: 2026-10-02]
blender/renders/cam_interior.png

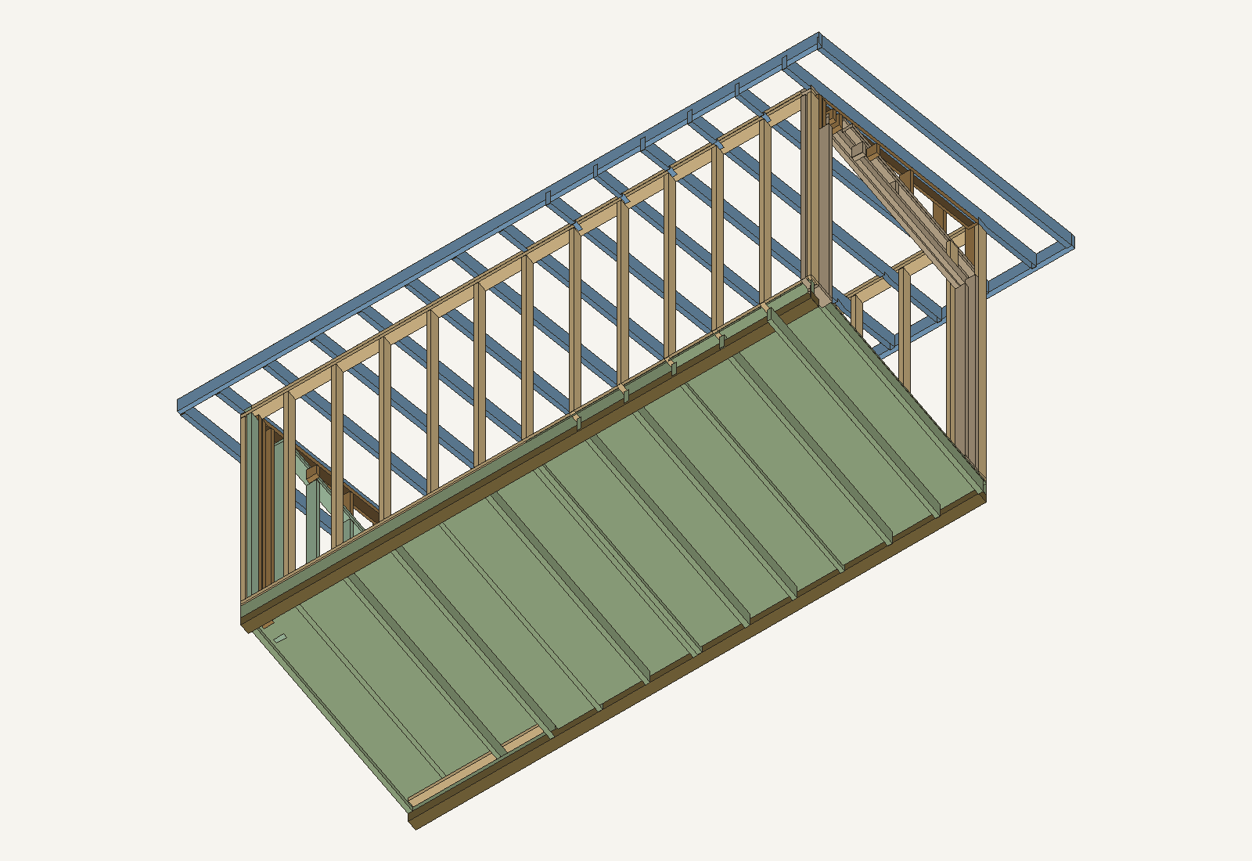
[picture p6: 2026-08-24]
renders/shed-roof-top.png

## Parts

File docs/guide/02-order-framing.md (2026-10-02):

---
page: P02
title: Order — framing lumber + foundation
prev: 01-what-youre-building.md
next: 03-order-finish.md
---

# Order — framing lumber + foundation

> **Goal:** one printed sheet that buys every framing and foundation item the shed needs, in one trip if your cuts go well.

This is the framing order. The finish lumber (siding, trim, doors, hardware) is a **different
order on a different page** — [03-order-finish.md](03-order-finish.md). Never merge the two.

**Yard: Hingham Lumber.** Kiln-dried framing species is SPF #2. The yard stocks 16 ft 2×4,
16 ft 4×4, and true 20 ft 2×6 — the order below assumes those stocks. Pressure-treated
ground-contact species is whatever the yard carries; that choice is not yours.

> ⚠️ **WARNING — exact quantities, zero overage** · a miscut is not covered by the order ·
> plan a follow-up run instead of padding the list. The stock packing below already includes
> a ⅛″ saw kerf per cut; it does not include mistakes.

## Framing lumber (the framing order)

| ☐ | Lumber | Treatment | Stock length | Qty | Notes |
|---|---|---|---|---|---|
| ☐ | 2×4 | KD (SPF #2) | 8′ | 1 | |
| ☐ | 2×4 | KD (SPF #2) | 16′ | 31 | five 16′-long plates force 16′ stock |
| ☐ | 2×6 | KD (SPF #2) | 10′ | 15 | one each for the 13 rafters + 2 rake boards (9′ 7⅜″ apiece) |
| ☐ | 2×6 | KD (SPF #2) | 20′ | 2 | true 20′ for the two 18′ fascia |
| ☐ | 2×6 | PT (ground contact) | 14′ | 7 | floor joists, two 6′ 9″ per board |
| ☐ | 2×6 | PT (ground contact) | 16′ | 2 | rim joists |
| ☐ | 4×4 | PT (ground contact) | 16′ | 2 | the two continuous skids |
| ☐ | OSB ¾″ | — | 4×8 sheet | 4 | subfloor; rip to 7′ + 1′ offcut, one panel per sheet |

What that buys, after packing (first-fit-decreasing, ⅛″ kerf):

| Group | Bought | Cut | Waste |
|---|---|---|---|
| 2×4 KD | 504 LF | 493.9 LF | 2.0% |
| 2×6 KD | 190 LF | 180.2 LF | 5.2% |
| 2×6 PT | 130 LF | 126.5 LF | 2.7% |
| 4×4 PT | 32 LF | 32 LF | 0% |

Total framing dimensional lumber: **856 LF**. The per-board cut assignments (which part comes
off which stick) live in `CUT_LIST.md` § "Stock-length order list" in the repo; the same
tables are summarized in [r01-cut-list.md](r01-cut-list.md).

## Foundation materials (not on either lumber order)

Per the captain's 2026-08-24 decision: the skids bear directly on one compacted gravel pad
across the whole 16′ × 7′ footprint — no pedestals, no paver pads, no fasteners.

| ☐ | Item | Qty | Notes |
|---|---|---|---|
| ☐ | ¾″ angular crushed stone | about 3–4 yd³ | the whole pad, 8–12″ deep as dug, placed in 3″ lifts and tamped |
| ☐ | landscape fabric | one pad's worth | lines the whole excavation, lapped up the sides |

The pad is screeded flat and level to string lines, and the skids bed directly on it — no
shims anywhere. Decision record and source: [r02-sources.md](r02-sources.md).

The foundation is the one part of this build that is drawn, not modeled — see
[r02-sources.md](r02-sources.md) for where the drawings came from.

## Before you move on

- [ ] Every box above is ticked against the loaded truck.
- [ ] The 16′ 2×4s and 4×4s and the true 20′ 2×6 were confirmed in stock before driving.
- [ ] You accept that a miscut means a second trip, not a spare on the pile.
- [ ] Next: the [finish order](03-order-finish.md) — a separate trip, a separate list.

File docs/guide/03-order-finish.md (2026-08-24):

---
page: P03
title: Order — finish lumber + hardware
prev: 02-order-framing.md
next: 04-blocks-and-skids.md
---

# Order — finish lumber + hardware

> **Goal:** one printed sheet that buys every siding, trim, door, and hardware item — without touching the framing order.

> **THIS IS A SEPARATE ORDER.** The finish lumber is modeled for real but ordered on a
> completely separate list from the framing lumber. Never merge the two orders, never buy
> finish stock "while you're there" on the framing run. Two lists, two trips, two invoices.

**Yard: Hingham Lumber.** Same yard as the framing order.

> ⚠️ **WARNING — exact quantities, zero overage** · a miscut is not covered by the order ·
> plan a follow-up run instead of padding the list, same as the framing order.

## Finish lumber and hardware (the finish order)

| ☐ | Lumber / item | Treatment | Stock length | Qty | Notes |
|---|---|---|---|---|---|
| ☐ | 1×10 | PRIMED | 14′ | 1 | frieze, the two 6′ 1″ side pieces |
| ☐ | 1×10 | PRIMED | 16′ | 2 | frieze, front + back, 15′ 1″ each |
| ☐ | 1×4 | KD | 8′ | 1 | door rails (the short 2′ 2⅜″ rails) |
| ☐ | 1×4 | KD | 14′ | 8 | door stiles (12 × 6′ 10¾″) + rails |
| ☐ | 1×6 | KD | 14′ | 23 | door planks (46 × 6′ 10¾″, two per board) |
| ☐ | 1×6 | PRIMED | 8′ | 3 | corner boards / casings |
| ☐ | 1×6 | PRIMED | 10′ | 1 | barn head casing |
| ☐ | 1×6 | PRIMED | 12′ | 4 | corner boards / casings |
| ☐ | 1×6 | PRIMED | 14′ | 4 | corner boards / casings |
| ☐ | 1×8 | PRIMED | 14′ | 1 | siding short courses |
| ☐ | 1×8 | PRIMED | 16′ | 33 | siding + skirt |
| ☐ | strap hinge 12″ black | — | ea | 12 | 2 per leaf, 6 leaves |
| ☐ | gate latch + hasp black | — | ea | 3 | 1 per opening; each double latches at center |

What that buys, after packing: 1×10 46 LF, 1×4 120 LF, 1×6 KD 322 LF, 1×6 PRIMED 138 LF,
1×8 542 LF — **1,168 LF** of finish lumber. Per-board cut assignments live in the FINISH
sections of `CUT_LIST.md` in the repo.

## Primed versus kiln-dried — read before substituting

- **PRIMED** rows (all siding, skirt, corner boards, frieze, door casings) arrive with a
  factory primer coat. They are the weather skin of the shed. They still need a finish coat
  of paint on site — paint and caulk are not on any order.
- **KD** rows (the 1×4 and 1×6 door stock) are bare kiln-dried boards for the
  board-and-batten leaves. They arrive unprimed: prime and paint them yourself before or
  after assembly.
- Do not swap one for the other at the yard. Primed stock is a different product line from
  framing-grade KD; and the door leaves are deliberately bare KD, not primed.

Hardware has no geometry in the model — hinges and latches exist only as the line items
above.

## Before you move on

- [ ] This list was placed as its own order, separate from [the framing order](02-order-framing.md).
- [ ] Primed rows and KD rows were checked as two groups at pickup.
- [ ] You have paint and caulk on your own third list — they are on neither order.
- [ ] Next: [Stage 1 — gravel pad and skids](04-blocks-and-skids.md).

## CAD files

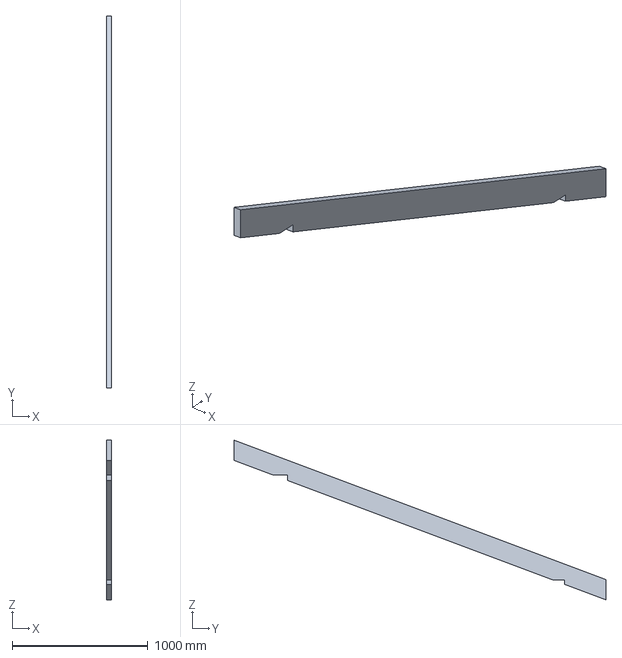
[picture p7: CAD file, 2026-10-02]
step/120 rafter.step
38.1 x 2743.2 x 1177.9 mm

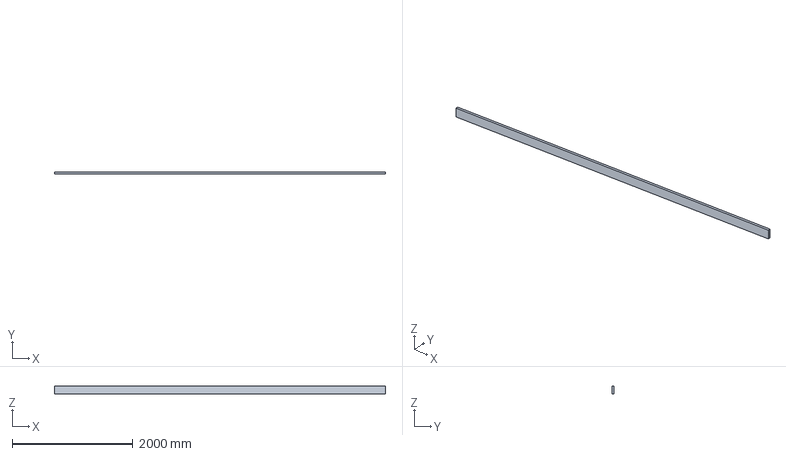
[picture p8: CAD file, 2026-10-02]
step/123 front fascia.step
5486.4 x 38.1 x 139.7 mm

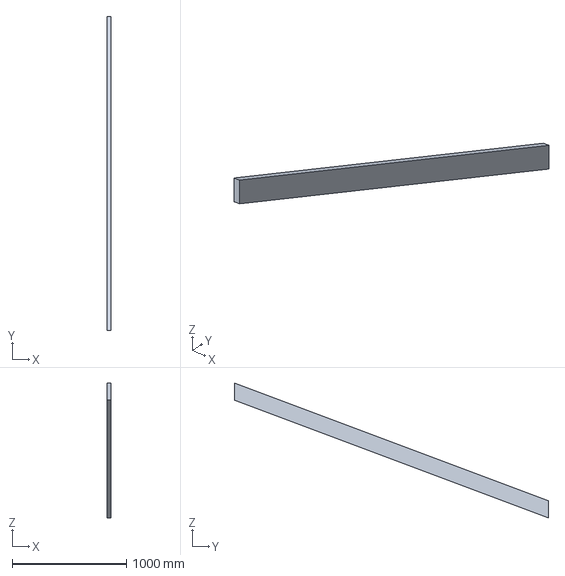
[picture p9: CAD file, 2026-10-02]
step/122 right rake board.step
38.1 x 2743.2 x 1177.9 mm

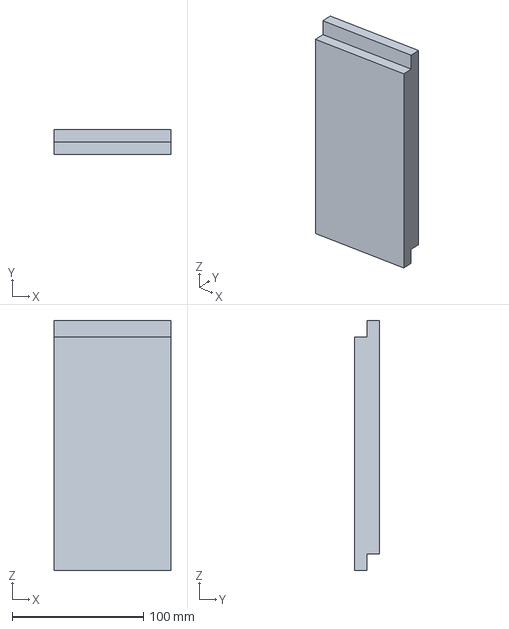
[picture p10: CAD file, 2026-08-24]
step/133 finish siding front.step
88.9 x 19.0 x 190.5 mm

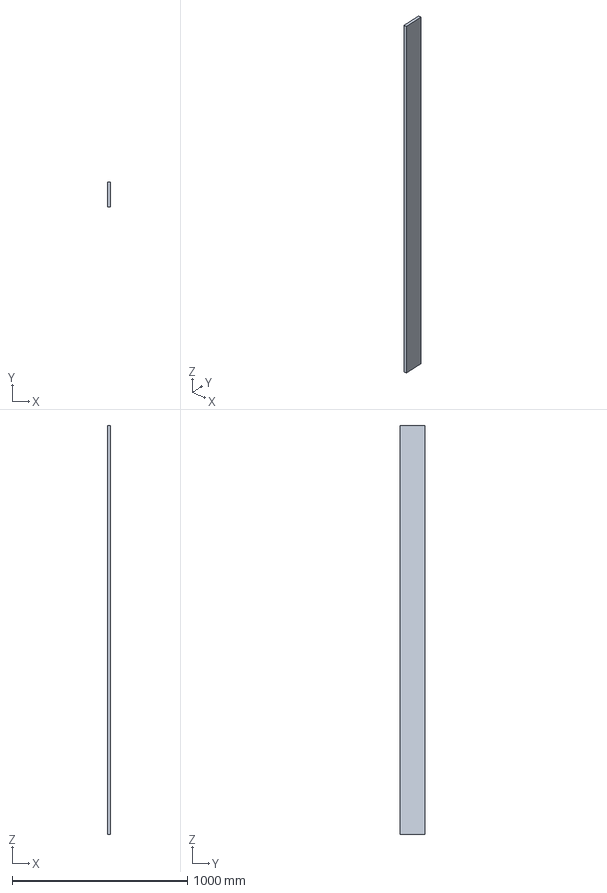
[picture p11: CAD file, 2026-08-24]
step/235 finish corner boards.step
19.1 x 139.7 x 2332.0 mm

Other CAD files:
step/114 rafter.step
step/112 rafter.step
step/117 rafter.step
step/118 rafter.step
step/116 rafter.step
step/113 rafter.step
step/110 rafter.step
step/119 rafter.step
step/108 rafter.step
step/115 rafter.step
step/109 rafter.step
step/121 left rake board.step
step/111 rafter.step
blender/shed_scene.blend
blender/shed_skin.blend
step/001 skid.step
step/002 skid.step
step/003 rim joist.step
step/004 rim joist.step
step/005 floor joist.step
step/006 floor joist.step
step/007 floor joist.step
step/008 floor joist.step
step/009 floor joist.step
step/010 floor joist.step
step/011 floor joist.step
step/012 floor joist.step
step/013 floor joist.step
step/014 floor joist.step
step/015 floor joist.step
step/016 floor joist.step
step/017 floor joist.step
step/018 floor joist.step
step/019 sub floor osb.step
step/020 sub floor osb.step
step/021 sub floor osb.step
step/022 sub floor osb.step
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

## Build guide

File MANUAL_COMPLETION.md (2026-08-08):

# Manual completion guide — the captain's broken tail features

Status as of 2026-08-08 (restore version `aa73830b88f34f965190a7c6`
"pre-fleet-completion 2026-08-05" taken before any change).

**Resolved 2026-08-08**: the captain approved deletion of his 20 broken
tail features (indices 100–119); they were deleted via the API and the tree
is now fully green (119 features, zero errors). Indices 98–99 (`right rake
wall` sketch + Frame 63) were kept — they are live and build the right rake
plate. Post-deletion re-pull verified: 120 parts, names intact, bboxes
identical, overlap audit unchanged. This document is kept as the diagnosis
record. Pre-deletion microversion: `75ed0337831d755732fa8042` (Onshape
retains full history; restore versions `aa73830b` and "V1 4/12/26" still
exist if the captain's original construction is ever wanted back).

The rake-wall and rafter geometry the mid-refactor was building **now exists
in the model**, rebuilt additively from current geometry (features added by
`scripts/build_members.py`, all named, all verified):

| New part group | Qty | Dims (oriented) |
|---|---:|---|
| right rake wall studs | 4 | 2x4, heights 22.40 / 16.68 / 10.77 / 4.86" |
| left rake wall studs | 4 | same heights (mirrored wall) |
| left rake wall top plate | 1 | 2x4 × 69.29", sloped 24/65, mirror of right |
| rafter | 13 | 2x6 × 115.13", 15.875" o.c., x = -2.75…187.75, birdsmouthed front (seat z=123) and back (seat z=97.5) |
| front / back fascia | 2 | 2x6 × 216" (12" past each side wall), tops flush with rafter tails |
| left / right rake board | 2 | 2x6 × 115.13", along the slope at the roof overhang edges (flush with the fascia ends), butting the fascia inner faces |

The captain's own tail features (indices 100–119) were deleted 2026-08-08
with his explicit go-ahead; indices 98–99 were kept (live, build the right
rake plate). The sections below explain why the deleted chains broke —
kept as the diagnosis record.

## Why the tail features fail

Decoded query analysis (`scripts/decode_queries.py`): the chains dangle on
entities that were **deleted in the May 13 rework** and have no equivalent
current entity recoverable via API:

- Deleted sketch/feature `FrZYFpgdFKjya90_36` (a fit-spline sketch, probably
  the pre-rework rafter/rake source sketch) is referenced by Frame 64,
  Split 3, the `Rafter Right` sketch plane, Frame 67, Delete face 1 and
  Linear pattern 12.
- The `left rake wall` sketch (FiKQ888uBey2hqI_78) plane references an
  imprint of the front-wall sketch (`6EjE1s8sV2Tc "bottom"`) through a
  derived-edge chain that died when the front wall was re-framed — the
  sketch cannot regenerate, so Frame 65/66 paths into it dangle.
- The `Rafter Right` sketch plane dangles the same way (back-wall imprint
  chain through Frame 11).
- Transform 5 and Frames 68/69 reference four **deleted mate connectors**
  (`FnIecGR1qx20dBs`, `FRVwmcycLIvehP7`, `FpFOhvn0h3OXIgO`,
  `FG26LejFgzsuatY`) — the fascia/rake-board alignment rig is unrecoverable.
- The right/left chains' Split/Delete features reference imprints on parts
  that were rebuilt with new ids; repointing ~45 compressed derived
  references blind was judged unsafe, so nothing was edited.

## What each broken chain was building (best reconstruction)

**Right rake wall** (sketch OK + Frame 63 OK → the existing 69.29" rake top
plate; Frame 64 + Linear pattern 10 (4 × 16") + Split 3 + Delete part 2 →
the rake studs): superseded by the new `right rake wall studs` (4 parts).

**Left rake wall** (sketch ERROR → whole chain dead): superseded by the new
`left rake wall top plate` + `left rake wall studs`.

**Rafter Right** (sketch plane ERROR → Frame 67 rafter + Linear pattern 12
(12 instances × 16") + Delete face 1 + Transform 5 + Frames 68–71 + Move
face 13): Frame 67 + pattern 12 → the rafters, superseded by the new 13
`rafter` parts. Frames 68–71 (four frames on mate-connector angle
references) + Transform 5 + the 12" Move face 13 were the **roof trim
package** — the April fascia/rake-board construction with the roof extended
12" past each side wall. That intent is now superseded by the new
`front/back fascia` (2x6 × 216" = 192" shed + 2 × 12") and
`left/right rake board` (2x6 × 118.32", running end-to-end flush with the
fascia outer faces) parts.

## Cleanup — done 2026-08-08

1. **Done**: the 20 tail features in ERROR (Frame 64 … Frame 71 and their
   sketches/patterns/splits/deletes/transforms — everything from the
   `right rake wall` sketch's Frame 64 onward, plus the `left rake wall`
   and `Rafter Right` sketches) were deleted via the API
   (`DELETE .../features/featureid/{fid}`, reverse tree order) with the
   captain's go-ahead. Verified after: 119 features all OK, 120 parts with
   names intact, bboxes/oriented dims unchanged, overlap audit unchanged.
2. If the captain's original construction is ever wanted instead of the
   rebuild: restore version `aa73830b88f34f965190a7c6`, then in the UI
   re-point
   - the `left rake wall` sketch plane onto the left wall plane (same plane
     as `left wall sketch`),
   - Frame 64's second selection and Split 3's targets onto current
     front-wall geometry,
   - the `Rafter Right` sketch plane onto a plane normal to X (e.g. the
     shed mid plane), and rebuild the four fascia mate connectors.
3. The fascia and rake boards are modeled now (see table above); nothing
   else is missing from the roof framing.

## Relationship-based rebuild (in progress, started 2026-08-08)

Captain's direction: members should be constraint-driven from existing
geometry (absolutes only at critical anchors) so design changes propagate,
not absolute-coordinate sketches. The API mechanism is proven (a sketch
line constrained COINCIDENT to a solid face solved to the face exactly;
control run confirmed), and the first member group is converted:

- **right rake wall studs** (sketch `FqDfLcBqgGzsYjO_103`, in-place
  update): 4 quads, 44 constraints — bottom edges coincident to the right
  wall double top plate top face, top edges driven 1.5" below the rake
  plate top face (its underside is unprobeable), sides vertical, widths
  1.5", stud 1 anchored to the y=0 plane, spacings 15.5/16/16 in (left
  edges 0/15.5/31.5/47.5 in — first stud hard in the front corner).
  Solved geometry matches the previous absolute build within 4µm
  (uniform +3.96µm: the studs now track the plate's real faces, not the
  build formula). Seeds were perturbed before solving, so the positions
  genuinely came from the constraints.

Still absolute (conversion pending, same recipe): left rake wall studs,
left rake wall top plate, rafters, fascia, rake boards. Recipe, harness
and rollback definition: `scripts/constraint_pilot/`. API mechanics:
AGENTS.md "Relationship (constraint) builds via API".

## Geometry reference used for the rebuild (all in inches, Z up)

- Roof slope: **24/65** (rise 24" over the 65" front-to-back wall bearing
  spacing; matches the right rake plate's top edge exactly).
- Right rake plate top edge: (y=65, z=97.5) → (y=0, z=121.5); underside
  line: z = 97.5 + (24/65)·(60.669 − y).
- Rake stud centers (both walls, on the wall's 16" grid): y = 0.75, 16.25,
  32.25, 48.25; each bears on the double top plate (z=97.5) and is mitered
  to the rake-plate underside.
- Rafter bottom edge (the captain's `Rafter Right` line, decoded): from
  (y=−27.5, z=131.654) to (y=80.5, z=91.777) = 24" front / 12" back overhang
  from the wall outer faces, bearing on the front plate at (y=0, z=121.5)
  and back plate at (y=65, z=97.5); 2x6 (5.5" depth ⊥ slope), plumb end
  cuts, length 115.13". Birdsmouths: front seat flat at z=123 (heel at
  y=−4.0625, plumb kick at the front wall inner face y=0); back seat flat
  at z=97.5 over y=65…68.5 with plumb kick at the back outer face.
- Rafter X positions: 13 uniformly spaced centers −2.75 … 187.75 (the live
  stud-grid endpoints), spacing 15.875".
- Fascia: 2x6, x = −15.5 … 200.5 (216", 12" past each side wall), front at
  y = −29 … −27.5 with top flush at the front rafter-tail top (z = 137.52),
  back at y = 80.5 … 82 flush at z = 97.64. Rake boards: full rafter
  profile (115.13"), 1.5" thick, flush with the fascia ends at the roof
  overhang edges (x = −15.5 … −14 and 199 … 200.5), butting the fascia
  inner faces (y = −27.5 … 80.5) so the fascia stays unbroken.
- Rake-plate noses (0.27" slivers that poked into the front wall plates):
  left plate trimmed in its sketch (front end now a vertical face at y=0);
  right (captain's) plate trimmed by the scoped REMOVE feature
  "right rake plate nose trim" (wedge under the plate-top line, boolean
  scope limited to the plate body).

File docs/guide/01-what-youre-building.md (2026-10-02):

---
page: P01
title: What you're building
prev: index.md
next: 02-order-framing.md
---

# What you're building

> **Goal:** know the shed's shape, its key numbers, and what this guide does and does not cover — before you order a single board.

One combined wood shed and bike shed: a 16 ft × 7 ft rectangular box with a single-slope
(shed) roof, the tall wall at the front (street/door) side, three exterior door openings,
1×8 lap siding, and board-and-batten doors. The whole shed rides on two continuous
pressure-treated 4×4 skids bearing directly on a levelled, compacted gravel pad — no
concrete, no pedestals.

Fig 1.1 — Cross-section through the whole shed, viewed from the right gable end. The tall front wall (plate top 10′ 3″ above the deck) falls at 4.5 : 12 to the back wall (plate top 7′ 8⅝″ above the deck); rafters birdsmouth onto both double top plates; the deck top is the height zero for the whole 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

<!-- model trace: section plane constant X at x 92.5 (through the doubled floor-joist pair);
front wall y -3.5...0, z 0...123; back wall y 77...80.5, z 0...92.625; rafter profile: heel
y -4 seat z 123, back seat z 92.625 y 77...80.5, tails y -15.5 / 92.5; fascia faces y -17 /
94; peak z 133.187; skids z -9.75...-6.25; foundation drawn schematic (not modeled) -->

## The shape in numbers

| What | Value |
|---|---|
| Framed footprint, wall outer faces | 16′ × 7′ |
| Roof plan, fascia face to fascia face | 18′ × 9′ 3″ |
| Roof overhangs | 12″ on all four sides — front, back and past each side wall |
| Wall height above the deck | front 10′ 3″; back and both sides 7′ 8⅝″ at the flat plate, then the gable follows the roof |
| Roof pitch | 4.5 : 12, high side at the front |
| Peak, front fascia top | 11′ 1-3/16″ above the deck |
| Door openings, rough framed | front wall: one 8′ × 7′ barn at the west corner; left wall: one 5′ 4″ × 7′ double (MAIN entry); right wall: one 5′ 4″ × 7′ brewery double |
| Deck height | deck top sits about 9¾″ above the skid bottoms |
| Modeled parts | 321: 124 framing in 40 cut-list groups, 197 finish |

Every height in this guide is measured up from the deck top — the deck is zero. Horizontal
positions are tape readings from a named edge or corner, never coordinates.

## Key design decisions, in plain language

- **Pre-cut studs.** The side walls use standard 92⅝″ pre-cut studs; the back wall's studs
  are cut 88⅛″ so its plates land 7′ 8⅝″ up, on the roof line the 10′ 3″ front wall sets.
  Where the roof drops below the side walls' plate stack, the gable follows it — mitered
  studs under the rake plate, no flat plate to the back corner.
- **Three doors, each earning its place.** An 8 ft barn door at the front wall's west corner
  straight-rolls both bikes and the blower, and carries slabs in on edge. The 5′ 4″ double on
  the LEFT wall is the MAIN entry — the everyday pedestrian door, closest to the
  garage/access. The twin 5′ 4″ double on the right wall is the brewery's service door,
  worked from outside. The barn header's west end bears on the built-up corner post, and each
  rake-wall double keeps 6½″ of end stud at both ends of its 7 ft wall (all flagged, not
  engineered).
- **Two continuous skids.** One full-length 16 ft PT 4×4 per skid line, under the front and
  back wall bearing lines. No splices, no sistering.
- **Birdmouthed rafters.** All 13 rafters carry a flat seat on the front double top plate
  and a second seat on the back double top plate, so each rafter bears flush on both plates
  instead of digging into them.
- **KD SPF #2 framing.** All wall and roof lumber is kiln-dried spruce-pine-fir #2. The
  pressure-treated lumber (ground-contact rated: skids plus the whole floor system) is
  whatever the yard stocks — the species is not yours to choose.
- **Board-and-batten doors.** Six leaves in three centre doubles (front barn, left MAIN,
  right brewery): vertical 1×6 planks with a 1×4 perimeter frame, hung on the casing face
  with 12″ strap hinges.
- **The siding is the wall surface.** 1×8 lap (drop) siding at 7″ exposure, rabbet-nested so
  the wall stays in one plane. No separate structural sheathing is modeled.
- **Two separate orders, exact quantities.** Framing lumber and finish lumber are ordered
  as completely separate orders, and neither carries any overage.

## What is NOT covered

These are not modeled and are on neither lumber order. If you want them, they are a third,
separate shopping list of your own:

- wall sheathing or weather-resistive barrier
- roof sheathing, underlayment, and roofing material
- fasteners (nails, screws, hinges are the only hardware on any list)
- paint and caulk for the primed finish stock
- door stops and weatherstrip

Do not invent quantities for these from this guide; the orders here contain exactly what
the model builds.

## Before you move on

- [ ] You can say the wall heights, the pitch, and the three door openings without looking.
- [ ] You know which items are NOT on either order (sheathing, roofing, fasteners, paint).
- [ ] You have read both order pages: [framing + foundation](02-order-framing.md) and [finish + hardware](03-order-finish.md).

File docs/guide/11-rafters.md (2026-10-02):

---
page: P11
title: Rafters
stage: Stage 8 of 12
prev: 10-rake-plates.md
next: 12-fascia-and-roof.md
---

# Stage 8 — Rafters

<!-- model trace: 13 rafters 2x6, lowX -3.5 .. 187 at 15.875 spacing (centers -2.75 .. 187.75);
     length 115.344; pitch 0.375 (4.5:12, 20.556 deg); front seat z 123 over y -4..0 (heel -4,
     kick 1.5 at front wall inner face y 0); back seat z 92.625 over y 77..80.5 (kick 1.3125 at
     back wall outer face y 80.5); tails y -15.5 / 92.5 (12"/12" past the wall faces); tail tops
     z 133.1865 / 92.6865. Pattern marks along the top edge, front end back: front seat/kick
     corner 16.554 (heel 12.282), back seat start +82.236, back tail +16.554 (sums 115.344). End
     rafters' back seats land on the side-wall DTP corner blocks (they run over the back wall
     to y 80.5). -->

> **Goal:** thirteen 2×6 rafters seated in their birdsmouths on both double top plates,
> defining the roof plane.
> **Crew:** 2 people for the raising (1 alone can cut) · **Time:** a full day ·
> **Weather:** dry and calm — the 9' 7⅜" boards catch the wind

This is the page where expensive stock gets ruined or saved. Every rafter is identical, so
you cut **one pattern rafter first, prove it fits both plates, and only then mark the other
twelve from it.** Nothing gets cut in anger until the pattern sits right.

The roof is a single slope — there is no ridge board. Every rafter runs downhill from the
front (high) wall to the back (low) wall, at **4½ in 12** (it falls 4½" per foot of run).

## Before you start

Parts for this page:

| Qty | Part | Lumber | Cut length |
|---|---|---|---|
| 13 | rafter | 2×6 KD | 9' 7⅜" |

Buy or cut your stock with a little to spare: fourteen blanks is not greed if the lumber
yard lets you pick through the pile. Choose the straightest board for the pattern.

Tools: tape, pencil, speed square, circular saw, handsaw, sawhorses, clamps, 4' level,
two ladders, a helper. Print the birdsmouth template (Fig 11.3 below) at full size before
you start cutting.

Already built: walls standing and braced; rake plates and stepped studs in
([Stage 7](10-rake-plates.md)).

## Steps

### 1. Mark the rafter layout on both double top plates

Thirteen rafters at **15⅞" on centre**. Hook your tape on the left end of the front double
top plate and mark the rafter centres: the first at **¾"**, then every 15⅞" — 16⅝", 32½",
48⅜", 64¼", 80⅛", 96", 111⅞", 127¾", 143⅝", 159½", 175⅜", out to **191¼"** at the right
end. The first rafter sits over the left rake wall, the last over the right.

Mark the same centres on the back double top plate. The back plate starts 3½" inboard of
the front plate's left end, so each tape reading drops by 3½" — and the first rafter's back
seat lands on the left side wall's double-top-plate corner block, which runs over the back
wall just to catch it. The right end works the same way.

Fig 11.1 — Rafter layout plan at wall-plate level, looking down, Stage 8. Thirteen rafter centres at 15⅞" on centre across both double top plates, first over the left rake wall, last over the right. Layout marks are made on the plates before any rafter is cut.

### 2. Cut the pattern rafter's ends and birdsmouths

Take the straightest 2×6 and mark its top edge — the edge that will face the sky. Crown the
board the same way as the wall studs if it has one. Cut one end square; that plumb end is
the **front tail**. Working along the top edge from that end, make three marks:

1. **16-9/16"** — the front wall's inner face: the inboard end of the front seat, where its
   plumb kick begins. The seat itself runs 4" back toward the board end from this mark — the
   heel, the seat's outboard end, lands at **12-5/16"**.
2. another **82¼"** (98-13/16" from the end) — the back wall's inner face, where the back
   birdsmouth's seat starts.
3. another **16-9/16"** — that is the back end. The three segments add up to exactly 9' 7⅜",
   so the last one should land on the board's end; if it does not, find the mistake before
   cutting anything.

At the front heel, use the template (Fig 11.3): its underside line rides the rafter's bottom
edge, heel to heel. Trace the **level seat, 4" long**, and the **plumb kick, 1½" deep**, at
the seat's inboard end. At the back seat start, trace the back birdsmouth the same way:
**level seat, 3½" long** (the full plate width), **plumb kick, 1-5/16" deep**, at the seat's
downhill end. Both notches read the same way on the board: seat level, kick plumb, kick to
the right of the seat.

> ⚠️ **WARNING** — Birdsmouth cuts are short crosscuts near your holding hand · blade
> contact and kickback · saw the seat cut first, then the kick cut, keep the kerf on the
> waste side of the line, and let the offcut fall free — never hold it underneath the blade.

Saw each seat cut level, then each kick cut plumb. Stop the seat cut exactly at the kick
line — if you overcut past the corner, the rafter rocks on its seat and that board becomes
a cripple for the shed wall, not a rafter. The finished notch is a clean two-sided corner;
check it against the template.

Fig 11.2 — Section through one birdsmouthed rafter, viewed from the left gable end, Stage 8. The level front seat lands on the front plate top and the level back seat on the back plate top; plumb kicks stand at the wall faces and plumb tails give the 12" front and 12" back overhangs.

### 3. Test the pattern on the wall — both plates

Carry the pattern rafter up and set it on the layout marks at the left end: seat in front,
seat in back. Check every one of these before cutting another board:

- Both seats bear flat, no rocking, no daylight under either seat.
- The front kick stands tight against the front wall's inner face; the heel stands ½" proud
  of the plate's outer face — that is as designed, do not trim it off.
- The back kick stands tight against the back wall's outer face, seat covering the full
  plate width.
- The top edge touches the rake plate's bearing line at the gable end.
- The plumb tails hang 12" past the front wall face and 12" past the back wall face.

Fig 11.3 — Birdsmouth template at full size, printed at 100%. The front notch (4" seat, 1½" kick) and the back notch (3½" seat, 1-5/16" kick), both at the roof pitch of 4½ in 12 — the same angle as the rake plate's top edge. Measure the 4" check line before trusting any mark it made.

> ⚠️ **WARNING** — A rafter seated on one plate only will tip under the first load ·
> collapsed rafter, bent stock, fall hazard · before letting go of any rafter, look at BOTH
> seats. If one seat is proud, the notch is wrong — recut from your spare, do not shim a
> structural bearing. See [troubleshooting](16-troubleshooting.md) if a seat gaps.

### 4. Cut the remaining twelve rafters from the pattern

Clamp the pattern to each new board, top edges together, and trace around the tails and both
notches. Cut to the lines, kerf on the waste side. As you go, stack the finished rafters and
sight down their top edges — a twisted blank shows up now, while it is still cheap.

Check each rafter's overall length against the pattern (9' 7⅜") and keep any board that
misses by more than an eighth for a different job.

### 5. Stand the rafters

Two people, one at each end. Stand the first rafter on its marks over the left rake wall
and the last one over the right rake wall, each seated in both birdsmouths, and toe-nail or
screw through each plate into the rafter. Sight along the top edges of those two — they
should read as one straight, even slope. Stand the remaining rafters on their marks in any
order, seating each one in both plates and fastening each one the same way.

> ⚠️ **WARNING** — Working from ladders with 9' 7″ boards overhead · falls and dropped
> lumber · keep both ladders solid and level, lift the boards up between two people, and
> never work a rafter into place while standing under it.

Until the fascia and roof bracing go on ([Stage 9](12-fascia-and-roof.md)), the rafters can
still tip sideways. Keep them plumb-faced; a brace board nailed diagonally across a few of
them holds the row in line.

## Before you move on

- [ ] Every rafter bears flat on **both** plates — no daylight at either seat, checked by
      sighting from each end.
- [ ] Spacing holds at 15⅞" on centre along both plates — checked with a tape.
- [ ] All thirteen top edges read as one plane — checked by sighting down them and with a
      straight board laid across.
- [ ] Front tails stand 12" past the front wall face, back tails 12" past the back wall
      face — checked with a tape.
- [ ] Rafter faces stand plumb — checked with a 4' level.

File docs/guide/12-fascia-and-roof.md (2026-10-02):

---
page: P12
title: Fascia, rake boards and the roofing note
stage: Stage 9 of 12
prev: 11-rafters.md
next: 13-skirt-and-siding.md
---

# Stage 9 — Fascia, rake boards and the roofing note

<!-- model trace: fascia 2x6 x 216 (x -15.5..200.5, 12" past each side wall); front fascia
     y -17..-15.5, z 127.6865..133.1865; back fascia y 92.5..94, z 87.1865..92.6865; tops
     flush with rafter tail tops (z 133.1865 / 92.6865). Rake boards x -15.5..-14 /
     199..200.5, y -15.5..92.5, same parallelogram as a rafter minus the seats, ends butt
     the fascia inner faces. Roofing/sheathing/fasteners: not modeled, on neither order. -->

> **Goal:** every rafter tail is capped: fascia across the front and back, rake boards down
> the two gable edges — and you know exactly what the roofing shopping list is.
> **Crew:** 2 people · **Time:** about half a day · **Weather:** dry and calm

## Before you start

Parts for this page:

| Qty | Part | Lumber | Cut length |
|---|---|---|---|
| 1 | front fascia | 2×6 KD | 18' 0" |
| 1 | back fascia | 2×6 KD | 18' 0" |
| 1 | left rake board | 2×6 KD | 9' 7⅜" |
| 1 | right rake board | 2×6 KD | 9' 7⅜" |

The fascia come off true 20' 2×6 stock — order true 20-footers and cut each to 18', not
two shorter boards scarfed together. The rake boards are the same parallelogram as a rafter
with **no birdsmouths**: if you cut one early and kept it as a spare, it already has the
right end angles.

Tools: tape, pencil, speed square, circular saw, sawhorses, two ladders, a helper, string
line.

Already built: all thirteen rafters seated, plumbed, and fastened ([Stage 8](11-rafters.md)).

## Steps

### 1. Nail up the front fascia

Two people, two ladders. Offer the 18' front fascia up against the front rafter tails,
tight to the plumb end cuts, its top edge flush with the rafter tail tops — 133-3/16"
above the deck. Centre it so it stands **12" past each side wall**, then fasten it to every
rafter tail.

> ⚠️ **WARNING** — An 18-foot board at ladder height, held overhead · drops, splits, and
> falls · lift it up between two people, rest it on the rafter tails before fastening, and
> never hold it clear of the tails with just your arms.

Fig 12.1 — Section through the front eave, viewed from the left gable end, Stage 9. The fascia stands tight against the plumb rafter tails with its top flush with the tail tops; the rafter's front birdsmouth sits on the front plate just inboard.

### 2. Nail up the back fascia

Same board, same rules, low side of the roof: tight against the back rafter tails, top
edges flush with the tail tops — 92-11/16" above the deck — and 12" past each side wall.

### 3. Fit the rake boards

Each rake board runs down a gable edge over the overhang, the same 4½-in-12 slope as the
rafters. Set the left rake board along the left roof edge with its ends butting the inner
faces of the front and back fascia, and fasten it at each end through the fascia. Fit the
right rake board the same way.

The rake boards span the overhang between the fascia with nothing under them in the model;
if a span feels springy, add your own brace blocks underneath — that is site judgement, not
modeled work.

Fig 12.2 — Roof plan, looking down, Stage 9. Front and back fascia cap every rafter tail, 12" past each side wall; the rake boards run down the gable edges between them. The rafters below are already built (grey); the fascia and rake boards are the new work (colour).

### 4. Write the roofing shopping list

> 🛒 **SHOPPING CALLOUT — roofing is on you.** The roof's working layers are **not modeled
> and are not on either lumber order** — deliberately. Nobody has picked your roofing, so
> nobody can pick its quantities. Source, to your own roofing spec:
>
> - roof sheathing (sheet goods) — the roof is one slope about 18' wide and
>   9' 7⅜" up the slope, at 4½ in 12 (the finished roof plan, fascia face to fascia face,
>   is 18' × 9' 3");
> - underlayment and its fasteners;
> - the roofing material itself and its fasteners;
> - drip edge for the eaves and rakes.
>
> Plan the sheet goods and drip edge around those slope dimensions, and add this to a
> separate shopping list before the framing weather-exposure window closes.

## Before you move on

- [ ] Fascia tops flush with the rafter tail tops along the whole run — checked by sighting
      down each fascia and running a hand along the top.
- [ ] Each fascia stands 12" past the side walls at both ends — checked with a tape.
- [ ] Both rake boards butt the fascia inner faces at both ends, on the roof's slope —
      checked by sighting along each gable edge.
- [ ] Roofing shopping list written: sheathing, underlayment, roofing, drip edge,
      fasteners — checked off this page's callout.

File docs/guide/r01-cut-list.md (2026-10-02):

---
page: R01
title: Reference — cut list
prev: 16-troubleshooting.md
next: r02-sources.md
---

# Reference — cut list

> **Goal:** look up any framing part's count, lumber, and cut length while you are at the saw.

Framing only. The finish cuts (siding, trim, doors) and the per-board stock packing that
turns these lengths into the order quantities live in `CUT_LIST.md` at the repo root —
its FINISH sections and its "Stock-length order list" are the authority, and this page
mirrors the framing tables for scanning. Actual dimensions, no kerf; the packing adds
⅛″ per cut.

Lengths below are rounded to the nearest ⅛″. Where a part is not an exact eighth
(the rake studs, rake plates, rafters), the exact value is in `CUT_LIST.md` — mark it
from the exact number, not this table.

## Skids

| Qty | Part | Lumber | Length |
|---:|---|---|---:|
| 2 | skid | 4×4 PT | 16′ |

## Floor

| Qty | Part | Lumber | Length |
|---:|---|---|---:|
| 2 | rim joist | 2×6 PT | 16′ |
| 14 | floor joist | 2×6 PT | 6′ 9″ |
| 4 | sub floor osb | OSB ¾″ panel | 7′ × 4′ |

## Back wall

| Qty | Part | Lumber | Length |
|---:|---|---|---:|
| 1 | back wall bottom plate | 2×4 KD | 16′ |
| 1 | back wall top plate | 2×4 KD | 16′ |
| 1 | back wall double top plate short | 2×4 KD | 15′ 5″ |
| 13 | back wall studs | 2×4 KD | 7′ 4⅛″ |

## Front wall

| Qty | Part | Lumber | Length |
|---:|---|---|---:|
| 1 | front wall bottom plate | 2×4 KD | 16′ |
| 1 | front wall top plate | 2×4 KD | 16′ |
| 1 | front wall double top plate | 2×4 KD | 16′ |
| 8 | front wall king studs | 2×4 KD | 9′ 10½″ |
| 2 | front wall jack studs | 2×4 KD | 6′ 10½″ |
| 3 | front wall headers | 2×4 KD | 8′ 3″ |
| 5 | front wall cripple studs | 2×4 KD | 2′ 7″ |

## Left wall

| Qty | Part | Lumber | Length |
|---:|---|---|---:|
| 1 | left side wall studs (front corner) | 2×4 KD | 7′ 8⅝″ |
| 1 | left side wall studs (corner post) | 2×4 KD | 7′ 4⅛″ |
| 2 | left wall jack studs | 2×4 KD | 6′ 10½″ |
| 3 | left wall headers | 2×4 KD | 5′ 7″ |
| 3 | left wall cripple studs | 2×4 KD | 5⅛″ |
| 1 | left wall top plate | 2×4 KD | 5′ 4¾″ |
| 1 | left wall double top plate | 2×4 KD | 5′ ¾″ |
| 1 | left wall double top plate (corner block) | 2×4 KD | 3½″ |
| 1 | left wall bottom plate short | 2×4 KD | 6½″ |
| 1 | left wall bottom plate long | 2×4 KD | 6½″ |

## Right wall

| Qty | Part | Lumber | Length |
|---:|---|---|---:|
| 1 | right wall studs (front corner) | 2×4 KD | 7′ 8⅝″ |
| 1 | right wall studs (corner post) | 2×4 KD | 7′ 4⅛″ |
| 2 | right wall jack studs | 2×4 KD | 6′ 10½″ |
| 3 | right wall headers | 2×4 KD | 5′ 7″ |
| 3 | right wall cripple studs | 2×4 KD | 5⅛″ |
| 1 | right wall top plate | 2×4 KD | 5′ 4¾″ |
| 1 | right wall double top plate | 2×4 KD | 5′ ¾″ |
| 1 | right wall double top plate (corner block) | 2×4 KD | 3½″ |
| 1 | right wall bottom plate short | 2×4 KD | 6½″ |
| 1 | right wall bottom plate long | 2×4 KD | 6½″ |

## Left rake wall

| Qty | Part | Lumber | Length |
|---:|---|---|---:|
| 1 | left rake wall top plate | 2×4 KD | 6′ 10¼″ |
| 2 | left rake wall studs (mitered, on sill) | 2×4 KD | 7′ 7⅛″ |
| 1 | left rake wall studs (mitered, on header) | 2×4 KD | 6⅜″ |
| 1 | left rake wall studs (mitered, on header) | 2×4 KD | 5¼″ |
| 1 | left rake wall studs | 2×4 KD | 1′ 10¾″ |
| 1 | left rake wall studs | 2×4 KD | 1′ 5″ |
| 1 | left rake wall studs | 2×4 KD | 11″ |
| 1 | left rake wall studs | 2×4 KD | 5″ |

## Right rake wall

| Qty | Part | Lumber | Length |
|---:|---|---|---:|
| 1 | right rake wall top plate | 2×4 KD | 6′ 10¼″ |
| 2 | right rake wall studs (mitered, on sill / header) | 2×4 KD | 7′ 7⅛″ |
| 1 | right rake wall studs (mitered, on header) | 2×4 KD | 6⅜″ |
| 1 | right rake wall studs (mitered, on header) | 2×4 KD | 5¼″ |
| 1 | right rake wall studs | 2×4 KD | 1′ 10¾″ |
| 1 | right rake wall studs | 2×4 KD | 1′ 5″ |
| 1 | right rake wall studs | 2×4 KD | 11″ |
| 1 | right rake wall studs | 2×4 KD | 5″ |

## Roof

| Qty | Part | Lumber | Length |
|---:|---|---|---:|
| 1 | back fascia | 2×6 KD | 18′ |
| 1 | front fascia | 2×6 KD | 18′ |
| 1 | left rake board | 2×6 KD | 9′ 7⅜″ |
| 13 | rafter | 2×6 KD | 9′ 7⅜″ |
| 1 | right rake board | 2×6 KD | 9′ 7⅜″ |

## Finish cuts and stock packing

Not repeated here. `CUT_LIST.md` at the repo root carries:

- the FINISH siding, trim, door, and hardware tables (the finish order),
- the framing and finish "Stock-length order list" — which part comes off which bought board, with waste per board,
- the order quantities these tables pack into ([P02](02-order-framing.md) and [P03](03-order-finish.md)).

## Before you move on

- [ ] Any length that is not an exact ⅛″ on this page was marked from `CUT_LIST.md`'s exact value, checked at the saw.
- [ ] The loaded lumber ticks off against `order_list.csv` (framing) — the sheet, not memory.

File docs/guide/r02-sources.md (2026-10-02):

---
page: R02
title: Reference — sources, verification, traceability
prev: r01-cut-list.md
---

# Reference — sources, verification, traceability

> **Goal:** where every number in this guide comes from, what the model's own checks report, and the figure-to-model-coordinate map the build pages deliberately leave out.

This page is traceability, not build reading. The visible pages speak in tape readings and
feet-inches-eighths; the model coordinates live here and in non-rendering source comments,
kept for `cad.verify` lineage.

## Model authority

- Geometry and quantities come from the repo `woodbike-shed`: `cad/*.py` (build123d model —
  framing, siding, trim, doors; shared layout math in `cad/common.py`) plus the generated
  `CUT_LIST.md`, `order_list.csv`, `order_list_finish.csv`.
- The model and lists were last changed at commit
  `c86e75d991126c33e2daa4d0589183db155378b2` ("Finish lumber as real parts: siding/trim/doors
  + separate order list", 2026-08-10). These pages were written 2026-08-13 from a worktree at
  `c961c86` and every overview/order number was re-checked against the model before writing.
- Verification run, 2026-08-23, after the 7 ft depth + 2-door plan rework
  (`~/.venvs/woodbike-shed/bin/python -m cad.verify`):
  `OK: 278 parts (118 framing, 160 finish), 36 framing cut-list names; dims/volumes/placements
  match audit data; seats/kicks/ends flush; finish layers seated; 0 unallowed interference
  (342 pairs swept).` The harness checks every part's dims, volume and placement against the
  audit data, gates the rafter birdsmouth seat/kick faces, the rake-stud mitres, tails flush
  with fascia, and the finish layer planes, and runs the full pairwise interference sweep.
- Viewing the model: `view.py` (OCP CAD Viewer, part tree mirrors the cut list);
  `blender/build_scene.py` renders the scene (`--skin` for the dressed variant).

## Deliberate divergence from the Onshape model

The Onshape document is a retired record copy. It still carries the pre-decision geometry —
93″ studs, sistered skids, no birdsmouths, no finish — and must not be synced from. Since
2026-08-10 the local audit JSON and `cad/` run ahead of it: the 92-5/8″ pre-cut restud and
the two continuous 16′ 4×4 skids were applied locally only, and the roof was re-derived
about the unchanged front wall (pitch 24/65 → 24.375/65). Every number in this guide follows
the local model, not Onshape.

## Foundation — the pier-less gravel pad (captain's decision, 2026-08-24)

The foundation is drawn, not modeled. On 2026-08-24 the captain dropped the piers and
pedestals entirely, superseding the StrataRise adjustable-pedestal design (which itself
superseded the eight-Tuff-Block design retired 2026-08-14): the two continuous 16′ PT 4×4
skids now bear DIRECTLY on a compacted gravel pad — no concrete, no pedestals, no paver
pads, no fasteners. The building above holds the skids; there is no hardware in this
foundation, and no shims — the screeded gravel is the shim.

Pad spec, as built into [P04](04-blocks-and-skids.md): excavate the full 16′ × 7′ footprint
to firm subsoil (probe first; depth varies, typically 8–12″ — dig to firm soil, never a
fixed depth), line with landscape fabric lapped up the sides, fill with ¾″ angular crushed
stone in 3″ tamped lifts (about 3–4 yd³), screed the top flat and level at or slightly
above finished grade, and crown the surrounding grade away from the shed. The practice
derives from the captain's original gravel-pocket drawings (read-only), applied to the
whole footprint instead of eight pockets. Deck top lands 9¾″ above the pad top (skid 3½″ +
2×6 joist 5½″ + ¾″ OSB). Durable decision copy:
`/media/griswald/wd-black-2tb/personal/firstmate/data/shed-guide-depth-pass/captain-decision-2026-08-24.md`.

## Known intentional quirks

- The two 84″ opening-A jack studs and the one 120″ front king stud run from the deck
  through the front bottom plate — a documented modeling quirk, exempt from the
  interference sweep. P01 carries the field handling.
- The inner volume reference envelope pre-dates the roof and is excluded from all lists.
- Not modeled (builder scope): wall sheathing/WRB, roof sheathing/underlayment/roofing,
  fasteners, paint/caulk for the primed finish stock, door stops/weatherstrip.

## Coordinate traceability table

Figure-to-model-coordinate map. The guide's datum: deck top = z 0; front (street) wall at
low Y; X along the 16′ length; Z up. Each figure page also carries its trace as a
non-rendering HTML comment; stage pages owned by other workers carry their own.

| Figure | View | Model anchors |
|---|---|---|
| fig-01-cross-section | SECTION, constant X at 92.5 (through doubled joist pair), viewed from +X | front wall y −3.5…0, z 0…123; back wall y 77…80.5, z 0…92.625; rafter heel y −4 seat z 123, back seat z 92.625 at y 77…80.5, tails y −15.5 / 92.5; fascia faces y −17 / 94; peak z 133.187; skids z −9.75…−6.25; gravel pad schematic (pier-less) |
| fig-16-rafter-seat-gap | SECTION at the back wall seat, viewed from +X | back DTP top z 92.625 at y 77…80.5; plumb kick at y 80.5 to z 91.3125; rafter bottom slope 0.375; error gap 1″ drawn, exaggerated |
| fig-16-floor-diagonals | PLAN, horizontal cut at skid top, looking down | skid lines y −3.5…0 and y 77…80.5, x −3.5…188.5; error: front skid shifted +4″ in X, exaggerated |
| fig-16-rake-courses | ELEVATION, left wall face x −3.5, viewed from −X | siding 7″ exposure from skirt top z 0.5; rake cut line = rafter bottom + 1″ (z 96.8 back → 123.8 front); skirt z −6.75…0.5; error: top course 2″ past rake, exaggerated |

Whole-shed anchors used across pages: footprint x −3.5…188.5 × y −3.5…80.5; front DTP top
z 123; back DTP top z 92.625 (side walls' flat DTP tops z 97.125 run until the roof drops
below them, then the gable follows the roof); roof slope 24.375 rise over 65 run (4.5:12);
rafter layout 15⅞″ o.c. at x −2.75…187.75.

## Before you move on

- [ ] `~/.venvs/woodbike-shed/bin/python -m cad.verify` runs green at the commit this page names, if you are checking numbers against the model.
- [ ] A figure's source comment (`model trace`) agrees with its row in the table above, checked with a grep of the page source.

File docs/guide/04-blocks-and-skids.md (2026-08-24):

---
page: P04
title: Gravel pad and skids
stage: Stage 1 of 12
prev: 03-order-finish.md
next: 05-floor.md
---

# Stage 1 — Gravel pad and skids

> **Goal:** one level, compacted gravel pad across the whole footprint, with both continuous 16-foot skids bearing directly on it — square, aligned, and on one plane.
> **Crew:** 2 people · **Time:** about a day · **Weather:** dry ground

<!-- model trace: footprint x -3.5..188.5 (192"), y -3.5..80.5 (84"); front = street side = low y;
     skids x -3.5..188.5, front skid y -3.5..0, back skid y 77..80.5, z -9.75..-6.25;
     skid centerlines y -1.75 and 78.75 (80.5" = 6' 8½" c/c); skid-rectangle diagonals
     sqrt(192² + 84²) = 209.6" = 17' 5⅝". The foundation stack below the skids (landscape
     fabric + compacted ¾" gravel pad) is drawn, not modeled. Piers/pedestals DROPPED
     2026-08-24 by captain decision — skids bear direct on the screeded gravel pad; durable
     decision copy: firstmate data/shed-guide-depth-pass/captain-decision-2026-08-24.md -->

Left and right in this guide are as you stand in the street facing the shed. FRONT is the street
side — the tall wall with the doors. Your tape zero for this whole stage is the **left-end corner**
of the footprint.

**The foundation is a gravel pad — read this first.** No piers, no pedestals, no concrete, no
hardware: the two skids bear directly on a compacted gravel pad, and the building above holds
them down. The pad IS the foundation, and it is all of the 16 ft × 7 ft footprint:

> **Pad spec** — excavate the full 16′ × 7′ rectangle down to firm subsoil (probe first;
> depth varies, typically 8–12″ — dig to firm soil, never to a fixed depth). Line it with
> landscape fabric lapped up the sides. Fill with ¾″ **angular** crushed stone in 3″ lifts,
> tamping each lift. Screed the top FLAT AND LEVEL. Pad top at or slightly above finished
> grade, surrounding ground crowned so water falls away. About 3–4 yd³ of stone.

## Before you start

Parts tick-off (from the framing order, [P02](02-order-framing.md)):

| Qty | Part (cut-list name) | Lumber | Cut length |
|---|---|---|---|
| 2 | skid | 4×4 PT, ground contact | 16' 0" |

Foundation materials — **not on either lumber order** (see [P02](02-order-framing.md)):

- about 3–4 yd³ of ¾" **angular** crushed stone (112 ft² of footprint, 8–12" deep)
- landscape fabric for the whole pad, lapped up the sides

**No shims anywhere on this foundation — the gravel is the shim.** Wood shims rot in the
ground, and a screeded pad needs none.

Tools: shovel, probing rod (rebar or similar), tape, two string lines + line level (or a
transit), hand tamper, screed rails — straight boards longer than 7 ft (an 8 ft 2×6 works),
a 2' level, marking paint or stakes.

The two skids are single 16-foot 4×4s — no splices, no sistered joints. If your yard delivered
shorter stock, stop and sort the order before digging anything.

**How high the deck will sit.** The deck top lands 9¾" above the skid bottoms (skid 3½" +
2×6 floor joist 5½" + ¾" OSB — the Stage 2 floor stack). With the skids direct on the gravel,
the deck top finishes **9¾" above the pad top** — a little under 10 inches above grade. Plan
steps and door approach for a low deck.

## Steps

### 1. Get buried utilities marked

> ⚠️ **WARNING** — buried utilities · a shovel through a line can electrocute, explode, or cut service · call your utility locator before any digging (in the US: call 811, free), and wait for the marks.

### 2. Mark the footprint and the two skid lines

Mark a 16' × 7' rectangle on the ground with the front edge facing the street, and square the
corners (3‑4‑5 method, then check that both diagonals are equal — about 17' 5⅝"). Inside it,
mark the two skid lines: one under the front wall, one under the back wall. Each skid's
centerline runs 1¾" in from its shed edge, so the skid's outside face lands flush with the
footprint edge. The two centerlines are 6' 8½" apart, measured across the shed.

Fig 4.1 — Foundation layout, plan view looking straight down, FRONT (street side) at top. The whole 16 ft × 7 ft footprint is the gravel pad (hatched), the dashed rectangle is the future wall footprint on top of it, and the two skid lines are dashed where the skids will land. Every position is a ta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

### 3. Excavate the whole pad down to firm soil

Dig out the full 16' × 7' rectangle. Probe first to find how deep firm soil is — depth varies
across the footprint, typically 8–12". Dig to firm soil, not to a fixed depth. Keep the pad
top at or slightly above finished grade, and crown the surrounding grade so water falls away
from the shed.

> ⚠️ **WARNING** — an open excavation · the pad is shallow, but trips and falls are real with string, stakes, and spoil around · keep the spoil pile and walkways clear of the rectangle, and mark the corners where mowing and foot traffic cross.

![Fig 4.2 — The gravel pad in section, cut across the front skid (line B–B in Fig 4.1, viewed toward the right end). Bottom to top: firm soil, landscape fabric, tamped ¾-inch gravel, skid bearing directly on the stone — and above, dashed, the floor framing that lands on it later. Dig to firm soil, never to a fixed depth; the screeded gravel does the leveling — no shims. Depths drawn true, with no vertical exaggeration.](figures/fig-04-b.svg)

### 4. Line the pad with fabric

Line the whole excavation with landscape fabric, lapped up the sides — it stops the stone
migrating into the soil below.

### 5. Fill with stone in tamped lifts

Fill with ¾" angular crushed stone in 3" lifts, tamping each lift before adding the next.
Leave the last lift a little proud — the screed strikes it off at the strings.

### 6. Set the strings and screed the pad level

Run two string lines along the skid rows and level them to each other, so the strings define
one common plane across the whole pad. Strike the gravel off with screed rails riding the
strings (or on screed boards set to them), and check the screeded top with a straightedge and
the 2' level. Flat and level now is flat and level under the skids.

### 7. Set the skids on the screeded pad

Lay the front skid on the front skid line, under the front-wall bearing line, and the back
skid on the back line. Ends flush with the left and right ends of the footprint — the rim
joists will land flush on those same ends next stage. Align each skid's outside face with the
footprint edge. The skids simply bed on the screeded stone; they are not fastened to anything
— the building above holds them.

### 8. Bring both skids to ONE plane

Sight each skid top to its string, and lay a straightedge across from skid to skid. Where a
spot runs low or high, lift the skid, add or remove gravel beneath it, re-tamp, and re-set.
**No shims anywhere — the gravel is the shim.**

### 9. Check the rectangle

Measure diagonally across the four outside corners of the two skids, corner to opposite
corner. The two diagonals must be equal — each runs about 17' 5⅝". If they differ, shift the
skids on the gravel until they match. Nothing downstream can be squared if this rectangle is
not.

## Before you move on

- [ ] Pad top screeded flat and level, at or slightly above grade — checked with the strings, a straightedge, and the 2' level
- [ ] Both skid tops on the one string-line plane, no rocking skid — checked by sighting each string and rocking each skid end by hand; fix by lifting the skid and re-working the gravel
- [ ] Skid centerlines 6' 8½" apart, measured across the shed — checked with a tape
- [ ] Each skid's outside face flush with the footprint edge, ends flush left and right — checked with a tape
- [ ] Diagonals across the skid corners equal within ½", each about 17' 5⅝" — checked with a tape
- [ ] No shims anywhere under the skids — checked by eye
- [ ] Surrounding ground crowned away from the pad — checked by eye after wetting the ground

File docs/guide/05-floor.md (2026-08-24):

---
page: P05
title: Floor framing and deck
stage: Stage 2 of 12
prev: 04-blocks-and-skids.md
next: 06-front-wall.md
---

# Stage 2 — Floor framing and deck

> **Goal:** a stiff, square platform — two rims, 14 joists, and four deck sheets — whose top surface is the height zero for every stage that follows.
> **Crew:** 1 person, 2 helpful for the 16-foot rims · **Time:** about half a day · **Weather:** dry — keep the OSB dry

<!-- model trace: rims x -3.5..188.5, front rim y -3.5..-2, back rim y 79..80.5, z -6.25..-0.75;
     14 floor joists y -2..79 (81"), x edges -3.5, 11, 27, 43, 59, 75, 91, 92.5, 108.5, 124.5, 140.5, 156.5, 172.5, 187;
     doubled pair x 91..94; OSB z -0.75..0, y -3.5..80.5 (84" sheets), sheets x -3.5..44.5 / ..92.5 / ..140.5 / ..188.5
     (seams at 48/96/144" tape); skids y -3.5..0 and 77..80.5; deck top = z 0, 9.75" above the gravel pad top -->

Left and right are as you stand in the street facing the shed; FRONT is the street side. Tape
readings on this page are from the **left-end mark** — the left end of the skids and rims you set
in Stage 1. Fasteners are not modeled and are not on either lumber order: nail sizes and counts
are your call as the builder (typical floor framing practice applies).

## Before you start

Parts tick-off (from the framing order, [P02](02-order-framing.md)):

| Qty | Part (cut-list name) | Lumber | Cut length |
|---|---|---|---|
| 2 | rim joist | 2×6 PT, ground contact | 16' 0" |
| 14 | floor joist | 2×6 PT, ground contact | 6' 9" |
| 4 | sub floor osb | ¾" OSB 4×8 sheet | 84" × 48" |

The four deck sheets come from ripping four full 4×8 sheets to 84" + 12" — the 12" offcuts are
spare. Everything on this page is pressure-treated ground-contact stock; wall and roof lumber
comes later and stays dry.

Tools: tape, speed square, chalk line, circular saw (for the OSB rip), drill/driver or hammer,
a straight 2×4 or level long enough to span several joists.

## Steps

### 1. Nail the two rim joists along the skid outsides

Set each 16' 2×6 rim flat-side out along the outside face of its skid — the front rim along the
front (street) skid, the back rim along the back skid — with the rim's bottom bearing on the skid
top and its ends flush with the skid ends. Nail the rims to the skids. The rims' outside faces
define the front and back edges of the deck.

### 2. Mark the joist layout on both rims

Hook your tape on the left-end mark and mark the **left edge of every joist** on the inside face
of both rims — front and back get identical marks:

| Joist | Tape reading | Note |
|---|---|---|
| 1 | 0" | flush with the left end |
| 2 | 14½" | |
| 3 | 30½" | |
| 4 | 46½" | |
| 5 | 62½" | |
| 6 | 78½" | |
| 7 | 94½" | doubled pair — first |
| 8 | 96" | doubled pair — second |
| 9 | 112" | |
| 10 | 128" | |
| 11 | 144" | |
| 12 | 160" | |
| 13 | 176" | |
| 14 | 190½" | flush with the right end |

The field spacing is 16" on centre, run in from each end; the doubled pair at 94½"/96" closes the
middle.

Fig 5.1 — Floor framing in plan view, looking straight down from above the deck, FRONT (street side) at top. Stage 2: the two rims and 14 joists in full colour, the Stage 1 skids grey beneath them, and the four deck sheets dashed with their seams at 48", 96", and 144" from the left end. The tape re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

### 3. Set the 14 joists between the rims

Stand each 6' 9" joist on its mark between the rims and nail through each rim into the joist
ends. Check the doubled pair: joists 7 and 8 stand side by side at 94½" and 96". That doubled pair
exists for the deck: the middle sheet seam lands on it, so both sheet edges get full bearing, and
it stiffens the floor at mid-span.

### 4. Rip the deck sheets

Rip each of the four full 4×8 sheets to 84" + 12", giving four deck sheets of 84" × 48".

> ⚠️ **WARNING** — circular saw kickback · a sheet that sags into the cut can pinch the blade and kick it back · support both halves of the sheet full-length on sacrificial 2×4s so the cut stays open, and keep the offcut side free to fall.

### 5. Deck the floor

Lay the four sheets across the full 7' depth, end to end from the left end. The three seams
between sheets land at **48", 96", and 144"** from the left-end mark. The middle seam splits over
the doubled pair — one sheet edge bears on each joist of the pair. At the two outer seams one
sheet edge bears on the joist and the meeting sheet edge lands flush with that joist's edge; if
your OSB wants edge support there (blocking or edge clips), add it — that support is not modeled
and not on the order. Nail the sheets off as you go.

### 6. Make the deck top your zero

Stand back: the surface you are standing on is the height datum for the entire rest of this guide.
**Deck top = zero.** Every height on every page that follows is measured up from this surface —
the front wall rises 123" above it, the back and side walls 92⅝". Before the walls go up, pencil
"DECK = 0" on the inside of the front rim, and start your tape on the deck whenever a page gives
you a height.

Fig 5.2 — Section through the finished floor at 128¾" from the left end (line C–C in Fig 5.1, viewed toward the left end, FRONT at left). Stage 2 complete: the screeded gravel pad and the skids carry the rims, the joists, and the deck; the dashed plate shows where the front wall lands next. The dec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

## Before you move on

- [ ] Rim bottoms bearing hard on the skid tops, no gaps — checked by sighting along each rim
- [ ] Field joists at 16" on centre, doubled pair at 94½"/96" — checked with a tape
- [ ] All three deck seams landing on joists, the middle one split over the doubled pair — checked by eye and tap
- [ ] Deck flat across its width — checked with a straightedge or level over several joists
- [ ] Deck top 9¾" above the skid bottoms — checked with a tape at the skid ends
- [ ] "DECK = 0" penciled on the front rim — checked by eye

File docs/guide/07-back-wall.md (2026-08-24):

---
page: P07
title: Back wall
stage: Stage 4 of 12
prev: 06-front-wall.md
next: 08-side-walls.md
---

# Stage 4 — Back wall

> **Goal:** the back wall — 92⅝" from deck to plate top, no openings — lies assembled flat on
> the deck: plates, thirteen identical studs, and the short double top plate that leaves the two
> back corners open for the side walls to lap.
> **Crew:** 1 person · **Time:** about two hours · **Weather:** dry deck

<!-- model trace: back wall runs along x −3.5..188.5 at y 77..80.5; bottom plate z 0..1.5;
top plate z 89.625..91.125; double top plate short x 0..185 z 91.125..92.625 (stops 3.5" short
of each wall end); studs z 1.5..89.625 (88.125 pre-cut) at x −3.5, 11, 27, 43, 59, 75, 91, 107,
123, 139, 155, 171, 187 (16" o.c. centres) -->

## Before you start

**Parts** (framing order, cut-list names):

| Qty | Part | Size | Cut length |
|---:|:---|:---|---:|
| 1 | back wall bottom plate | 2×4 | 16' 0" |
| 1 | back wall top plate | 2×4 | 16' 0" |
| 1 | back wall double top plate short | 2×4 | 15' 5" |
| 13 | back wall studs | 2×4 | 7' 4⅛" (88⅛" pre-cut) |

- Same stock as the front wall: 2×4 KD SPF #2, fasteners your own (not on either order), no
  sheathing.
- This wall is framed flat along the deck's **back edge**, outer face flush with the deck edge;
  it goes up in Stage 6.
- The thirteen studs are all the same 88⅛" (7' 4⅛") pre-cut length — no measuring, one saw
  setting.

## Steps

### 1. Mark both plates

Lay the bottom plate and top plate together on the deck, ends square. Hook the tape on the
**left end — the same end that is at your left facing the shed from the street** (on this wall
you are working from behind the shed, so that end is at your right as you look at the wall).
Mark the left edge of every stud on both plates:

| Tape reading from the left end | Stud |
|---:|:---|
| 0" | left-corner stud, flush with the plate end |
| 14½" | stud |
| 30½" | stud |
| 46½" | stud |
| 62½" | stud |
| 78½" | stud |
| 94½" | stud |
| 110½" | stud |
| 126½" | stud |
| 142½" | stud |
| 158½" | stud |
| 174½" | stud |
| 190½" | right-corner stud, flush with the plate end |

After the first two, the studs land 16" on centre.

### 2. Set the thirteen studs

Set an 88⅛" pre-cut stud on every mark between the two plates, each one on the same face line,
and fasten both ends.

Fig 7.1 — Back wall framing, elevation viewed from behind the shed, assembled flat (Stage 4). Thirteen identical studs; the double top plate stops 3½" short of each end, leaving the corners for the side walls' plates.

### 3. Nail on the gang-marked top plate

Lay the top plate you marked in step 1 on the stud ends, each mark aligned with its stud, and
fasten it through into every stud.

### 4. Add the short double top plate

Lay the 15' 5" double top plate on top, centred so it stops **3½" short of each end** of the
wall. Those 3½" corner blocks are deliberate: the two side walls' double top plates will lap
over this wall's corners and nail the back corners together, so the laps alternate around the
box — the front wall's full-width double plate ties the front corners, the side walls' plates
tie the back ones. If this plate ran the full 16' 0", the laps would stack on top of it instead
of interlocking.

## Before you move on

- [ ] Diagonals of the flat wall equal within ½" — checked with the tape.
- [ ] Thirteen studs, each 88⅛" — checked once with the tape; they are identical pre-cuts.
- [ ] Double top plate is 15' 5" and ends 3½" short of each wall end — checked with the tape.
- [ ] Every stud and both plates fastened; wall flat and square on the deck, ready for Stage 6.

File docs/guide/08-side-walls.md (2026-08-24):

---
page: P08
title: Side (rake) walls
stage: Stage 5 of 12
prev: 07-back-wall.md
next: 09-raise-and-brace.md
---

# Stage 5 — Side (rake) walls

> **Goal:** both side walls — the shed's rake walls, 97⅛" from deck to plate top at their
> front end — lie assembled flat on the deck. Each carries a 5' 4" double: the LEFT one is
> the MAIN entry (closest to the garage/access), the RIGHT one serves the brewery. The two
> openings are framed identically. Above the plate tops the gable follows the roof — that
> sloped build arrives with the rake plates in Stage 7.
> **Crew:** 1 person · **Time:** about half a day for both walls · **Weather:** dry deck

<!-- model trace: side walls run along y 0..77 between front and back walls; left wall x −3.5..0,
right wall x 185..188.5. Bottom plates z 0..1.5: two 6.5" segments per wall (y 0..6.5 and
70.5..77); end/corner stud z 1.5..94.125 at y 0..1.5; jacks z 1.5..84 at y 5..6.5 and 70.5..72;
headers z 84..89 spanning y 5..72 (two plies + flat cap); cripples z 89..94.125 at y
22.5/38.5/54.5; top plate z 94.125..95.625 spans y 0..64.728; double top plate z 95.625..97.125
spans y 0..60.728 plus a 3.5" corner block y 77..80.5 at z 91.125..92.625; corner post
z 1.5..89.625 at the back end -->

## Before you start

**Parts shared by both walls** (framing order, cut-list names):

| Qty | Part | Size | Cut length |
|---:|:---|:---|---:|
| 1 | wall top plate | 2×4 | 5' 4¾" |
| 1 | wall double top plate | 2×4 | 5' ¾" |
| 1 | wall double top plate (corner block) | 2×4 | 3½" |
| 1 | corner post | 2×4 | 7' 4⅛" |

**Each wall also takes** — the two walls are identical, each with its 5' 4" door opening
(counts below are per wall; double them for the pair):

| Qty | Part | Size | Cut length |
|---:|:---|:---|---:|
| 1 | wall bottom plate short | 2×4 | 6½" |
| 1 | wall bottom plate long | 2×4 | 6½" |
| 1 | wall stud (front corner) | 2×4 | 7' 8⅝" (92⅝" pre-cut) |
| 2 | wall jack studs | 2×4 | 6' 10½" |
| 3 | wall headers | 2×4 | 5' 7" |
| 3 | wall cripple studs | 2×4 | 5⅛" |

- Each wall is framed flat along its own deck edge — left wall on the left edge, right wall on
  the right edge, outer face flush with the edge. Both go up in Stage 6. The **front end** of
  each side wall is the street end.
- The double top plate no longer runs to the back corner: the roof drops below the plate stack
  before the back wall, so the flat plate ends mid-wall and the gable (Stage 7) carries on.
  The 3½" **corner block** at the back end of the double-top-plate line and the **corner post**
  under it carry the corner rafter's back seat — frame them as drawn.
- Same rules as before: 2×4 KD SPF #2, fasteners your own, no sheathing.

## Steps — frame both walls, one after the other

The two walls are identical: frame the left (MAIN entry) first on the left deck edge, then
the right (brewery) the same way on the right edge.

### 1. Split the bottom plate

Instead of one long plate, use the two 6½" segments: one at the **front end**, one at the
**back end**. The 5' 4" gap between them is the door opening — no sill; the threshold is open
down to the deck.

### 2. Set the corner stud and the jacks

From the front end: the 92⅝" corner stud at 0", flush with the plate end; jack left edges at
**5"** and **70½"** — both 6' 10½" jacks bear on their plate segment and carry the head. That
leaves a **6½" end stud** between the opening and each corner — the flagged minimum of the
door plan; keep it.

### 3. Set the header and the cripples

Build the header exactly like the front-wall headers — three 5' 7" boards, two on edge at the
faces plus one flat cap — and seat it on the two jacks, bottom edge **84" up from the wall's
bottom edge (a 7' 0" head)**. Mark the three cripples on the top plate at 22½", 38½" and 54½"
from the front end and set the three 5⅛" cripples between the header top and the top plate.
The two mitered studs that close the gap between the header's back end and the gable arrive
with the rake plate in Stage 7.

### 4. Add the top plate, double top plate, and the back corner block

Align the 5' 4¾" top plate with the studs — it runs straight over the opening — and fasten it.
Lay the 5' ¾" double top plate flush with the **front end**; it stops where the roof drops
past it. Nail the 3½" corner block in the double-top-plate line at the **back end**, flush
with the back end of the bottom plate, and set the 7' 4⅛" corner post under it on the bottom
plate. The block and post carry the corner rafter later.

Fig 8.1 — Left side wall framing (the MAIN entry), elevation viewed from inside the shed, assembled flat (Stage 5). The 5' 4" opening framed between the jacks with 6½" end studs, split bottom plate, and the plates ending where the roof drops past them; dashed, the sloped rake plate and mitered stud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

Fig 8.2 — Right side wall framing (the brewery door), elevation viewed from inside the shed (front end at the right), assembled flat (Stage 5). Identical framing to Fig 8.1 — same opening, same jacks, same 6½" end studs, split bottom plate.

## Before you move on

- [ ] Diagonals of each flat wall equal within ½" — checked with the tape.
- [ ] Each wall: opening is 5' 4" wide between jack faces, 6½" of end stud at each end, and
      the header underside is 84" up from the wall's bottom edge — checked with the tape.
- [ ] Each double top plate is flush with the front end and stops short of the back end; the
      3½" corner block sits in its line at the back over the corner post — checked with the tape.
- [ ] All four walls now lie flat on the deck, complete. Next page raises them.

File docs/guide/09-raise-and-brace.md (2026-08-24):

---
page: P09
title: Raise, tie, brace
stage: Stage 6 of 12
prev: 08-side-walls.md
next: 10-rake-plates.md
---

# Stage 6 — Raise, tie, brace

> **Goal:** all four walls stand plumb on the deck edges, lapped together at the double top
> plates, held by diagonal bracing that stays on until the siding goes on.
> **Crew:** 2 people minimum — a third helps on the front wall · **Time:** about half a day ·
> **Weather:** calm and dry. Do not raise walls in wind.

<!-- model trace: wall outer faces at x −3.5 (left), x 188.5 (right), y −3.5 (front/street),
y 80.5 (back). Front double top plate z 121.5..123 runs the full 192"; back double top plate
short x 0..185 z 91.125..92.625; side double top plates: flat part y 0..60.73 z 95.625..97.125
+ corner block y 77..80.5 z 91.125..92.625 lapping over the back-wall corners (between them the
rake plate carries the wall top down, Stage 7); side walls occupy the 77" gap y 0..77 between
front and back walls -->

This is the heaviest and most dangerous part of the build. A raised front wall is 10' 3" tall and
16' 0" long; once it is off the deck it wants to fall, and it falls fast. Read the whole page
before you lift anything. The warnings sit on the steps that carry the hazard.

## Before you start

- All four walls framed flat, checks passed (Stages 3–5).
- Bracing stock: straight 2×4 offcuts long enough to run diagonally from near the top plate down
  to the deck — at least one per wall, two for the front. Braces are temporary and are **not on
  the lumber order**; cut them from scrap.
- Fasteners are your own, as before (not on either order).
- Tools: 4' level, tape, hammer or driver, stepladder, saw for the braces.
- Pick your helpers and agree on commands before lifting — "lift", "walk", "hold", "down".

## Steps

### 1. Plan the sequence

The walls go up in order: **1 front, 2 back, 3 left, 4 right**. The front wall goes first: it is
the tallest and heaviest, and its full-width double top plate sets the street-side face the side
walls butt into. The back wall goes second; each side wall then rises between the two and ties a
front-to-back pair together. Clear the deck of offcuts, stage the braces where each wall will
stand, and put your crew at the ends of the wall being raised.

Fig 9.1 — Raising sequence, whole shed in isometric view from above the street-front corner (Stage 6). Walls rise front, back, left, right; the two-person symbol marks the minimum crew at each wall.

> ⚠️ **WARNING** — The front wall is 10' 3" tall, 16' 0" long, and awkward once it leaves the
> deck. If it comes down it crushes hands and feet and smashes the framing. Two people minimum,
> one at each end; a third in the middle makes the front wall much safer. Do not raise walls in
> more than a light breeze.

### 2. Raise the front wall

One lifter at each end. Crouch, take the top edge, and lift with your legs. As the wall rotates
up, walk toward it hand over hand along the studs, keeping the bottom plate pivoting on the
deck's front edge. Past halfway, keep pushing it up to vertical — **do not let go** — and set it
down with the bottom plate's outer face flush with the deck edge and the wall ends flush with the
deck's side corners.

Fig 9.2 — Raising the front wall, end elevation viewed from the wall's left end (Stage 6). The top edge lifts while the bottom plate pivots on the deck edge; two lifters walk it up hand over hand, and the dashed outline shows where it lands.

> ⚠️ **WARNING** — Never stand under a rising wall, and never hold it overhead with locked arms.
> Keep your back straight and lift with your legs. If the wall starts to go, lower it under
> control — do not fight a falling wall.

### 3. Brace the front wall before anyone lets go

While one person holds the wall plumb — level held on an end stud — the other nails a diagonal
brace on the inside: from a stud near the top plate down to the deck, at about 45°. Nail a second
brace before the helpers step away. A standing wall is not stable until it is braced.

Fig 9.3 — Bracing a raised wall, elevation of the front wall viewed from inside the shed (Stage 6). A scrap 2×4 runs diagonally from a stud near the top plate down to the deck, nailed at both ends, and stays until the siding goes on.

### 4. Raise and brace the back wall

Same lift at the back edge: bottom plate outer face flush with the deck's back edge, ends flush
with the deck's side corners. Its 15' 5" double top plate already lies between the two corner
zones — leave it there; the side walls' plates will lap over the corners. Brace it the same way
before letting go.

### 5. Raise and brace the side walls — left, then right

One wrinkle: with the front and back walls standing, the gap between them is 6' 5", and a side
wall measures 6' 8½" across its back-corner lap — it cannot lie flat end-to-end between two
standing walls. Lay the side wall diagonally across the open deck with its front end at its
corner, raise it to vertical in the open with your helper, then walk it over and set its bottom
plate on the deck's side edge. The 3½" double-plate overhang at the back end lands above the back
wall's corner. Nail the side wall's front-end studs into the front wall's corner framing, plumb
it, and brace it. Repeat for the right wall.

### 6. Tie the corners at the double top plates

This is what turns four walls into one box. At each back corner the side wall's double plate
overlaps the back wall, and the back wall's short double plate butts against it from between; at
each front corner the side wall's double plate end butts into the front wall's corner framing,
under the front wall's full-width double plate. Nail through every lap and every butt.

Fig 9.4 — Corner laps, plan cut at double-top-plate level, looking down (Stage 6). Side-wall corner blocks lap over both back corners; the back wall's short plate fits between them; the front wall's plate runs the full 16' 0".

### 7. Plumb everything and leave the braces

Re-check every wall for plumb and nudge it by shifting the foot of its brace. Check the box at
plate level: 16' 0" long, 7' 0" deep, diagonals equal within ½". The bracing stays on until the
siding goes on in Stage 10 — do not remove it for the roof work.

## Before you move on

- [ ] All four walls plumb — checked with the level on an end stud of each wall.
- [ ] Every wall holds at least one diagonal brace, nailed at top and bottom; the front wall
      holds two.
- [ ] Corner laps nailed: both back corners (side plate over back wall) and both front corners
      (side plate end into the front wall's corner).
- [ ] Box measures 16' 0" × 7' 0" at the plate line with diagonals equal within ½" — checked
      with the tape.
- [ ] Bottom plates flush with the deck edges all the way around — checked by eye and tape.

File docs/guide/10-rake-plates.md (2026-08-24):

---
page: P10
title: Rake plates and stepped studs
stage: Stage 7 of 12
prev: 09-raise-and-brace.md
next: 11-rafters.md
---

# Stage 7 — Rake plates and stepped studs

<!-- model trace: rake plate top edge = bearing line z 121.5 (y 0) .. 92.625 (y 77); plate
     length 82.236 (77 x sec), underside zu = zbot - 1.5*sec, plate bottom = max(zu, 92.625):
     a flat seat over the back bearing from y 72.73; nose plumb at the front wall inner face.
     Flat side DTP top 97.125 runs y 0..60.73; flat top plate top 95.625 runs y 0..64.73.
     Stepped studs y 0/15.5/31.5/47.5, z 97.125 .. zu; exact lengths 22.773 / 16.960 / 10.960 /
     4.960. Mitred studs: y 65.5/68.5 on the 89" header cap (6.335 / 5.21) and y 73.5/75.5 on the
     bottom plate z 1.5..92.625 (91.125). Side DTP corner block y 77..80.5 top 92.625. -->

> **Goal:** each side wall carries a sloped rake plate whose top edge is the roof's bearing
> line, propped on four short stepped studs at the front and on mitred studs behind them, all
> the way to the back corner.
> **Crew:** 1 person · **Time:** about half a day · **Weather:** dry

The roof slopes from the front (high) to the back (low) at **4½ in 12** — it falls 4½" for
every 12" (one foot) of horizontal run. The rake plate's top edge follows that slope: it is
the line the rafters will bear against at the gable ends. Get this line right and the roof
frames itself; get it wrong and every rafter shows it.

Because the roof drops below the side walls' flat plate stack before the back wall, the rake
plate keeps going after the flat plates stop: mitred studs carry it down to the back corner,
where it seats flat on the side wall's double-top-plate corner block.

## Before you start

Parts for this page (cut-list names; exact lengths on the [cut list](r01-cut-list.md)):

| Qty | Part | Lumber | Cut length |
|---|---|---|---|
| 1 | left rake wall top plate | 2×4 KD | 6' 10¼" |
| 1 | right rake wall top plate | 2×4 KD | 6' 10¼" |
| 4 | left rake wall studs — stepped | 2×4 KD | 22¾″ · 16 31/32″ · 10 31/32″ · 4 31/32″ |
| 4 | right rake wall studs — stepped | 2×4 KD | 22¾″ · 16 31/32″ · 10 31/32″ · 4 31/32″ |
| 2 | left rake wall studs — back corner | 2×4 KD | 7' 7⅛" each |
| 2 | right rake wall studs — back corner | 2×4 KD | 7' 7⅛" each |
| 2 | left rake wall studs — header-cap mitres | 2×4 KD | 6⅜″ and 5¼″ |
| 2 | right rake wall studs — header-cap mitres | 2×4 KD | 6⅜″ and 5¼″ |

The stepped studs are short enough that most come out of the offcut pile from wall framing
(see the board packing on the [cut list](r01-cut-list.md)).

Tools: tape, pencil, speed square (or framing square), circular saw and handsaw, 4' level,
ladder or step, string line or straight board long enough to span the wall.

Already built: all four walls standing, plumb, braced, and tied at the plate line
([Stage 6](09-raise-and-brace.md)). On each side wall the flat double top plate (top 97⅛"
above the deck) runs only the front **60¾"** of the wall, and the flat top plate beneath it
runs to **64¾"** — both measured from the front corner. Behind those marks the wall top
follows the roof, and both walls carry their door framing below (left is the MAIN entry,
right the brewery service; the header caps top out 89" above the deck).

## Steps

### 1. Snap the bearing line on each side wall

On the left wall, measure up from the deck at the front end and mark **121½"** on the inside
face of the wall, right where the front wall meets it. At the back corner the line lands
**92⅝"** above the deck, on the side wall's double-top-plate corner block. Snap or
straight-edge a line between the two marks. Mark the right wall the same way.

Check the middle: 32½" in from the front end, the line should sit **109-5/16"** above the
deck. If it does, the slope is right.

Fig 10.1 — Left rake wall, elevation viewed from inside the shed, at the start of Stage 7. The finished wall — door framing included — is grey; the new rake plate, the four stepped studs, and the mitred studs are in colour. The plate's top edge is the bearing line: 121½" above the deck at the front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

### 2. Cut the rake plates

Take one 6' 10¼" rake plate and offer it up on the wall: nose at the front wall's inner face,
back end reaching the back corner. Trim the front nose with a plumb (vertical) cut so the
nose lands flush with the front wall's inner face. Cut the second plate the same way — the
two walls mirror each other.

> ⚠️ **WARNING** — Circular saw cuts at chest height when the plate is held on the wall ·
> kickback and blade contact · support the plate on sawhorses or the deck, never in the air,
> and keep the cut line clear of your free hand.

The plate lies so its wide face follows the roof slope — its top long edge is the roof's edge
line, and the studs will meet its underside. In the front 60¾" it bears on the flat double
top plate; behind that, on the mitred studs you fit below.

### 3. Stand the front stud and set the plate

Stand the longest stepped stud — the 22¾" one — plumb at the front end of the wall, bottom on
the double top plate, against the front wall. Its top lands just under the bearing line. Rest
the rake plate on it: nose at the front wall's inner face, bedded flat on the double top
plate and the top plate beneath it as far as they run. Brace the plate or have it held, then
fasten the plate down through the flat plates and into the stud top.

### 4. Cut the remaining studs

Cut the three shorter stepped studs per side — **16 31/32", 10 31/32", and 4 31/32"** — with
their tops sloped to match the rake plate's underside. That slope is the roof pitch:
**4½ in 12**, the same 20.6° angle you will use for the rafter birdsmouths
([Stage 8](11-rafters.md)) — set your bevel or speed square once and use it for every mitre
on this page.

Then cut the mitred studs that carry the plate behind the flat plate stack:

- two **6⅜"** and two **5¼"** cripples per side — their bottoms stand on the door header's
  cap, 89" above the deck, in the back bay of the opening;
- two **7' 7⅛"** studs per side for the back-corner zone — bottoms on the bottom plate,
  tops square-cut, carrying the plate's flat seat over the back bearing.

Every mitred top meets the plate underside at the roof pitch; only the bottoms differ. The cut-list
lengths are exact for the modeled positions; cuts land within an eighth, so cut each a hair
long and sneak up on the fit.

### 5. Fit the studs under the plate

Working front to back, stand each stud plumb at its tape reading from the front corner,
toe-fasten it at the bottom, and bring its mitred top tight against the plate underside with
no daylight:

| Stud | Tape reading | Bottom bears on |
|:---|:---|:---|
| stepped — 16 31/32″ | 15½″ | double top plate top (97⅛″) |
| stepped — 10 31/32″ | 31½″ | double top plate top (97⅛″) |
| stepped — 4 31/32″ | 47½″ | double top plate top (97⅛″) |
| header-cap mitre — 6⅜″ | 65½″ | header cap (89″) |
| header-cap mitre — 5¼″ | 68½″ | header cap (89″) |
| back-corner mitre — 7' 7⅛″ | 73½″ | bottom plate |
| back-corner mitre — 7' 7⅛″ | 75½″ | bottom plate |

(The first, 22¾" stepped stud already sits tight against the front wall at tape 0.) Fasten
the plate to each stud top as you go. At the back corner the plate's flat seat bears on the
side wall's double-top-plate corner block — nail through it there too.

Repeat steps 1–5 on the right wall. It is identical: same door framing below, same rake zone
above.

## Before you move on

- [ ] Bearing line check: 121½" above the deck at the front end, 92⅝" at the back corner,
      109-5/16" at 32½" in — checked with a tape.
- [ ] Each rake plate nose is plumb and flush with the front wall's inner face — checked with
      a speed square.
- [ ] Each plate's back end seats flat on the corner block with no rock — checked by sighting
      and feel.
- [ ] All eight studs per side stand plumb, tops tight to the plate underside with no
      daylight — checked with a 4' level and by sighting along the underside.

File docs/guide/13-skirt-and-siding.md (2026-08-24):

---
page: P13
title: Skirt and lap siding
stage: Stage 10 of 12
prev: 12-fascia-and-roof.md
next: 14-trim.md
---

# Stage 10 — Skirt and lap siding

> **Goal:** every wall is skirted at the deck and skinned with lap siding, from the skirt up to the rake line.
> **Crew:** 1 person · **Time:** about two days · **Weather:** dry — primed boards and fresh cut ends don't like rain

## Before you start

Framing, rake plates, rafters, fascia and rake boards are all up (Stages 1–9). Everything on this
page comes from the **separate finish order** — 1×8 PRIMED. Wall sheathing, roofing, fasteners and
paint are not modeled and are on neither lumber order: supply your own siding nails and plan the
paint separately.

Tick off the parts before you start (cut-list names, see [R01 cut list](r01-cut-list.md)):

| Qty | Part · stock | Cut length |
|---:|:---|:---|
| 2 | finish skirt · 1×8 PRIMED | 16′ (front and back) |
| 2 | finish skirt · 1×8 PRIMED | 7′ (side walls) |
| 13 | finish siding back · 1×8 PRIMED | 16′ |
| 6 | finish siding front · 1×8 PRIMED | 16′ |
| 12 | finish siding front · 1×8 PRIMED | 7′ 8½″ (solid wall east of the barn door) |
| 12 | finish siding front · 1×8 PRIMED | 3½″ (corner strip west of the barn door) |
| 2 | finish siding left · 1×8 PRIMED | 7′ (full courses above the door head) |
| 24 | finish siding left · 1×8 PRIMED | 10″ (piers around the door) |
| 1 each | finish siding left · 1×8 PRIMED | 5′ 6⅙″, 3′ 10⅙″, 2′ 2⅙″, 6⅙″ (rake boards) |
| 2 | finish siding right · 1×8 PRIMED | 7′ (full courses above the door head) |
| 24 | finish siding right · 1×8 PRIMED | 10″ (piers around the door) |
| 1 each | finish siding right · 1×8 PRIMED | 5′ 6⅙″, 3′ 10⅙″, 2′ 2⅙″, 6⅙″ (rake boards) |

Tools: tape, 4′ level, chalk line, a story pole (a straight 1×2 offcut marked with the course
lines), circular saw or mitre saw, a table saw or ripping guide for the rake cuts and the ripped
top courses, ladder.

## Steps

### 1. Hang the front and back skirt boards

The skirt is the datum for everything you nail after it: all trim starts from its top. Set each
16′ skirt on the rim joist band so its **top edge sits ½″ above the deck top** — that puts its
bottom edge ½″ below the rim joist's own bottom. The skirt sits one layer proud of the wall face:
its face lands where the trim above will land, and the siding comes up behind it. Nail it to the
rim joist band.

<!-- model trace: skirt z -6.75..0.5; rim joist z -6.25..-0.75, face flush with wall face;
skirt layer = trim layer, back on the siding outer face; deck top is the guide's zero -->

Fig 13.1 — Skirt board at the wall base, section through the front wall viewed from the left gable end. Stage 10, first member down. The skirt top, ½″ above the deck, is the line every later board measures from.

### 2. Hang the side skirt boards

Set the two 7′ skirts the same way, one on each end wall, same height as the front and back
skirts: top edge ½″ above the deck, square-cut ends at the corners. Check each against the deck
line with the tape before you nail.

### 3. Mark the course lines on every wall

The siding runs at a **7″ exposure**. From the deck top, mark a line every 7″ up each wall — or
mark a story pole once and carry it wall to wall. These lines are the bottom edge of each course.
The first line lands on the deck itself.

### 4. Start the first course behind the skirt

Set the first course with its bottom edge on the deck top, level, full length of its wall. Its
bottom ½″ tucks in behind the skirt. Nail it into the studs.

<!-- model trace: first course z 0..7.5, siding layer; skirt covers z -6.75..0.5 in the trim
layer outboard of it; exposure 7", board width 7-1/2", courses nest via a 1/2" x 3/8" rabbet/tongue -->

The boards are 1×8 drop siding: ¾″ thick, 7½″ wide. Each course has a tongue along its top edge;
the next course's bottom rabbet drops over it, so the courses nest and the wall stays in one
plane — no bevel drift as you climb.

Fig 13.2 — Two nested siding courses, section on the wall face viewed from the left gable end. Stage 10, course-on-course. The tongue of the lower course fills the rabbet of the one above; bottom edges land 7″ apart.

### 5. Skin the back wall

Run full 16′ courses up the back wall — 13 courses. No openings: every course is one board. The
rafter tails overhang this wall, so the top course is ripped down to tuck under them: its top
edge lands 90¾″ above the deck, behind where the back frieze will sit. Keep each course's bottom
edge on its 7″ line and nail into the studs.

### 6. Skin the front wall

The front wall has one opening: the 8 ft barn door at the west corner — the wheeled roll-out
for the bikes, snow blower and slabs — headed 84″ above the deck; east of it the wall is solid.

Below the head line, 12 courses break into two piers each: the 3½″ corner strip west of the
barn door, and the solid wall east of it — a 7′ 8½″ board per course. Above the head line,
6 full 16′ courses run wall to wall. The last of those is ripped so its top edge lands on the
plate top, 10′ 3″ above the deck, behind where the front frieze will sit.

> ⚠️ **WARNING** — ladder work · the top courses on the 10′ 3″ front wall put you at height ·
> ladder on firm ground, never reach sideways past the rails

### 7. Skin the side walls up to the rake

Both side walls are sided the same way, because both carry the same door: a 64″ double, headed
84″ above the deck, clear from 6½″ to 70½″ measured back from the front corner. The left one is
the MAIN entry; the right one serves the brewery.

Every course below the head breaks into two piers — a 10″ piece in front of the door and a 10″
piece behind it, 12 courses of them (24 pieces per wall). Above the head, one full 7′ course
runs wall to wall, and the course above that meets the rake line at the back end — it runs the
full 7′ but its top back corner is clipped down to the rake.

Stop where the courses start meeting the rake line; the next step finishes the top.

### 8. Fit the rake boards on both side walls

Above the last full course, each side wall takes four rake-cut boards. Their top edges are ripped
at the roof pitch — the same angle as the rake boards from Stage 7, about 20½° off square — and
each one butts the tongue top of the course below. Set your bevel from a rake board, not from a
number, and rip each top edge to the line.

Each rake board comes out 20″ shorter than the one below it, measured along the bottom edge —
that falls out of the roof pitch (28⅞″ of rise over a 77″ run, the same 4½ in 12) and the 7½″
board width. Cut them to these bottom-edge lengths, longest to shortest, starting from the
bottom of the rake run:

| Wall | Bottom-edge length |
|:---|:---|
| left and right | 5′ 6⅙″ |
| left and right | 3′ 10⅙″ |
| left and right | 2′ 2⅙″ |
| left and right | 6⅙″ |

(⅙″ is not on your tape — cut these a hair long and sneak the rake angle; the frieze covers the
top joints.)

<!-- model trace: rake courses z bottoms 99, 106.5, 114, 121.5 (the clipped full course below
them runs z 91.5..99); top of the stack 123.813 at the front end; side-top line = rafter
bottom edge + 1" tuck; lengths are longest (bottom) edges, each 20" shorter than the one below
(77/28.875 x 7.5) -->

> ⚠️ **WARNING** — ripping angled boards · the sloped top cut is a rip, not a crosscut · keep the
> fence on the straight bottom edge, use a push stick, and never freehand the workpiece past the blade

Fig 13.3 — Left wall from outside, elevation. Stage 10, top of the wall. Courses 1–12 split into 10″ piers around the door opening; courses 13–14 run full width, then four rake-cut boards step up the roof line, each 20″ shorter than the one below.

## Before you move on

- [ ] Skirt top is ½″ above the deck all the way around — checked with tape and level
- [ ] First course level with its bottom edge on the deck top — 4′ level
- [ ] Every course bottom lands on its 7″ line — tape against the story pole
- [ ] The top courses on front and back sit tight against their tuck lines, behind the future frieze — sighted from the ground
- [ ] Rake boards tight to the rake line, top edges parallel to it — tape and bevel gauge
- [ ] Every course fastened into the studs along its length — walk each wall and look for misses
- [ ] No splits at the pier ends and rake tips — look, then fix now while the boards are few

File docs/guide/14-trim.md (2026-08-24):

---
page: P14
title: Trim
stage: Stage 11 of 12
prev: 13-skirt-and-siding.md
next: 15-doors.md
---

# Stage 11 — Trim

> **Goal:** every corner, eave line and door opening is trimmed — all siding edges covered and each opening framed for its door.
> **Crew:** 1 person · **Time:** about one day · **Weather:** dry

## Before you start

The skirt and all siding are on (Stage 10). Trim is the next layer out: **all trim backs onto the
siding face** — one proud layer, backs touching, never sinking into the siding plane. Work in one
order: **corner boards → frieze → casings**. Everything here is 1×6 or 1×10 PRIMED from the
separate finish order; fasteners are not on either lumber order, so supply your own nails.

Tick off the parts (cut-list names, see [R01 cut list](r01-cut-list.md)):

| Qty | Part · stock | Cut length | Where |
|---:|:---|:---|:---|
| 2 | finish corner boards · 1×6 PRIMED | 10′ 3 5⁄16″ | front corners, boards on the side faces |
| 2 | finish corner boards · 1×6 PRIMED | 10′ 2½″ | front corners, boards on the front face |
| 2 | finish corner boards · 1×6 PRIMED | 7′ 7 13⁄16″ | back corners, boards on the side faces |
| 2 | finish corner boards · 1×6 PRIMED | 7′ 6¼″ | back corners, boards on the back face |
| 2 | finish frieze · 1×10 PRIMED | 15′ 1″ | front and back eave bands |
| 2 | finish frieze · 1×10 PRIMED | 6′ 1″ | side eave bands, raked |
| 5 | finish door casings · 1×6 PRIMED | 6′ 11½″ | jamb casings — barn east jamb + both jambs of each 64″ side door (the barn's west jamb is the corner board) |
| 1 | finish door casings · 1×6 PRIMED | 8′ 3½″ | head casing over the 96″ barn opening |
| 2 | finish door casings · 1×6 PRIMED | 6′ 1″ | head casings over the two 64″ side doors, each scribed to the rake at its back end |

Tools: tape, 4′ level, mitre saw, ladder, nails.

## Steps

### 1. Hang the corner boards

Two boards per corner — one lying flat on each wall face — with their bottom edges on the skirt
top (½″ above the deck). Each board backs on the siding face of its own wall; together they close
the corner. Nail through into the corner framing.

The pairs are not the same length, because the front wall is tall and the back wall is short:

- **Front corners:** the board on the front face runs to the plate top — 10′ 3″ above the deck.
  The board on the side face runs to the rake line — a 5⁄16″ longer cut, 10′ 3 5⁄16″.
- **Back corners:** the board on the back face runs to the back tuck line under the rafter
  tails — 7′ 6¼″. The board on the side face runs to the rake line — 7′ 7 13⁄16″.

<!-- model trace: corner boards z 0.5 (skirt top) to 123.0 / 123.8125 (front pair), 90.75 /
92.3125 (back pair: back-face board to the back tuck line, side-face board to the rake line);
side frieze runs between the corner boards, raked, 73 long; trim layer = siding outer face +
0.75..1.5 outboard -->

Fig 14.1 — Corner layering, horizontal section at mid-wall height looking down from above. Stage 11, first trim down. One corner board lies flat on each wall face, each one proud layer out from the siding it backs on.

### 2. Hang the front and back frieze

The frieze is the 1×10 band under the eaves, between the corner boards, and it covers the top
edges of the siding. Set the front frieze with its **top edge flush with the plate top** — 10′ 3″
above the deck — and nail it through the siding into the wall framing. Set the back frieze with
its top edge at the back tuck line, 90¾″ above the deck, tucked under the rafter tails.

Both bands are 15′ 1″ long, cut to land exactly between the corner boards.

> ⚠️ **WARNING** — ladder work · the frieze sits about 10 feet up on the front wall · ladder on
> firm ground, move it along rather than reaching

Fig 14.2 — Front wall from the street, elevation. Stage 11, trim order. Corner boards first, frieze second, casings third — each piece one proud layer out from the siding.

### 3. Hang the side frieze

The two side bands are 6′ 1″ long and **raked**: their top edges follow the roof line between the
corner boards. Set each one with its top edge on the rake line (the underside of the rake boards
from Stage 7 is your guide), then nail. Check the rake by eye from a distance before you commit —
a crooked frieze reads crooked from everywhere.

### 4. Hang the jamb casings

Five jamb casings, all cut at 6′ 11½″. Set each one on the skirt top (½″ above the deck) with
its **inner edge exactly on the clear opening edge**, and run it up to the head line, 84″ above
the deck. Plumb it, then nail through the siding into the jack and king studs behind.

The openings are the 96″ barn door at the front wall's west corner (wheeled roll-out) and the
two identical 64″ doubles on the side walls — the MAIN entry on the left, the brewery service
door on the right. Each side door takes two jamb casings. The barn door takes one: it has no
west jamb casing — the corner board is its west casing, and the west leaf laps onto it. After
this step each opening still measures its clear width — the casings frame the opening, they
don't narrow it.

### 5. Hang the head casings

The head casings span over the tops of the jamb casings, seat on them, and cover the siding edge
at the heads. Cut: 8′ 3½″ over the barn opening, 6′ 1″ over each side-door opening. Set each
one level, its bottom edge on the 84″ head line, ends overhanging the jamb casings by the casing
width each side. On both side walls the rake frieze drops below that top line at the back end —
scribe each casing's top edge to the frieze bottom there. The barn head casing butts the corner
board at its west end. Nail.

## Before you move on

- [ ] Corner boards plumb, bottom edges tight on the skirt top — 4′ level and tape
- [ ] Front frieze top edge flush with the plate top; back frieze tight under the rafter tails — sighted along the wall
- [ ] Side frieze top edges straight on the rake line — sighted from a distance
- [ ] Jamb casings plumb, inner edges exactly on the clear opening edges — 4′ level
- [ ] Each opening still measures its clear width: 96″ at the barn, 64″ at both side doors — tape
- [ ] Head casings level and seated tight on the jamb casings — level, then look for daylight
- [ ] All trim backs on the siding face — no trim sunk into the siding plane, no proud gaps — sight across each face

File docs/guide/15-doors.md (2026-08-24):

---
page: P15
title: Doors
stage: Stage 12 of 12
prev: 14-trim.md
next: 16-troubleshooting.md
---

# Stage 12 — Doors

> **Goal:** six board-and-batten leaves built and hung as three centre doubles — the 8 ft barn
> door on the front wall (wheeled roll-out), the 5' 4" MAIN entry double on the left wall, and
> the 5' 4" brewery double on the right wall — closing up the shed.
> **Crew:** 1 person, 2 for hanging · **Time:** about one day · **Weather:** dry

## Before you start

The trim is on and every opening is cased (Stage 11). The doors are the last layer of the
finish: each leaf hangs **on the casing face**, one layer proud of the trim, and its own frame
rides one layer proud again. Door stock is KD 1×6 and 1×4 from the separate finish order;
hinges and latches are line items on the same order — fasteners for everything else are not
modeled and not on either order.

Six leaves over three openings, all centre doubles: the barn pair on the front wall's 96"
opening, and two identical 64" rake-wall pairs — the **left wall pair is the MAIN entry**
(closest to the garage/access), the **right wall pair serves the brewery**. The two rake-wall
doors are exact twins: same 64" span, same head, same leaves, hung the same way. At the barn
door's west jamb there is no casing — the corner board is the casing, and the west leaf laps
onto it.

Tick off the parts (cut-list names, see [R01 cut list](r01-cut-list.md)):

| Qty | Part · stock | Cut length | Use |
|---:|:---|:---|:---|
| 46 | finish door planks · 1×6 KD | 6′ 10¾″ | vertical planks, ripped per leaf below |
| 12 | finish door rails · 1×4 KD | 6′ 10¾″ | the two full-height outside stiles per leaf — the cut list files stiles and rails under the one name |
| 4 | finish door rails · 1×4 KD | 3′ 6⅜″ | top and bottom rails, each barn leaf |
| 8 | finish door rails · 1×4 KD | 2′ 2⅜″ | top and bottom rails, each rake-wall leaf |
| 12 | strap hinge 12″ black | hardware | 2 per leaf |
| 3 | gate latch + hasp black | hardware | 1 per opening, at the centre meeting stiles |

Tools: tape, square, circular saw or mitre saw, table saw or ripping guide for the plank rips,
drill/driver, level, props or a helper.

## Steps

### 1. Rip the planks

Each leaf's planks are ripped from the 1×6s so they fill the leaf width exactly, edge to edge:

- **Barn leaves (2):** 9 planks each, ripped equal — about 5½" apiece — so the nine together
  make the 49⅜" leaf width.
- **Rake-wall leaves (4 — two for the left MAIN door, two for the right brewery door):**
  7 planks each, ripped equal — about 4¾" apiece — so the seven together make the 33⅜" leaf
  width. All four are identical.

All planks stay 6′ 10¾″ long. Keep the ripped edges straight; they are the face of the door.

### 2. Build a barn leaf

Stand the nine planks edge to edge, 49⅜" across — that is the 48" half-opening plus the 1½"
the leaf will lap onto the jamb casing (the corner board at the west jamb). Build the 1×4
perimeter frame on the **outer face** of the planks: the two 6′ 10¾" stiles full height at the
edges, the two 3′ 6⅜" rails across the top and bottom between them. Screw the frame to the
planks. The leaf is 82¾" tall. Build the second barn leaf the same way.

<!-- model trace: barn leaf 49.375 x 82.75, planks layer + frame layer outboard; leaf bottom 1"
above deck top, top 1/4" below the 84" heads; 9 planks x ~5.486 -->

Fig 15.1 — One leaf of a centre double hung on its opening, elevation viewed from outside the shed. Stage 12, first door. Nine planks with the 1×4 frame on the outer face, hinges on the rails into the casing, lapping each jamb casing 1½″.

### 3. Build the four rake-wall leaves

Build all four 64"-door leaves the same way — two for the left MAIN door and two for the
right brewery door; they are identical and interchangeable. Each leaf 33⅜" wide with 7 planks,
the two 2′ 2⅜" rails top and bottom, stiles full height on the outer face.

### 4. Hang the barn pair

Set each leaf on its half of the opening with its **bottom edge 1" above the deck** and its top
edge ¼" below the 84" head line, lapping 1½" onto the jamb casing (the west leaf laps the
corner board). Leave the ¼" meeting gap at the centre. Mark the hinge positions on the casing
at the top and bottom rail heights, then fix the two 12" strap hinges per leaf: strap along the
leaf's rail, hinge end screwed to the casing face. The leaf swings on the casing — that is by
design, and it is why the casing is solid 1×6 over the studs.

> ⚠️ **WARNING** — pinch and drop hazard · a leaf is awkward one-handed · support it on a prop or
> to a helper while you fix the hinges, and keep fingers out of the hinge-side gap as it swings

### 5. Hang the two rake-wall pairs

Hang the left MAIN pair and the right brewery pair the same way, one leaf per side of each
64" opening, hinged to the outer jamb casings. Leave the ¼" meeting gap at the centre and
check both bottoms sit 1" above the deck. Fit a latch at the centre meeting stile of each.
The two openings are twins, so what you learned hanging the first pair carries straight over
to the second.

### 6. Read the jamb build-up

Before you call the doors done, look at what a closed leaf stacks onto — this is the build-up
the whole finish was working toward, and the check for every layer you hung. At any door jamb
the finish steps outward in **four ¾" layers**:

1. **1×8 lap siding** on the wall face,
2. **1×6 jamb casing** on the siding face,
3. **door planks** on the casing face,
4. the **1×4 leaf frame** outboard.

That is **3" proud of the wall face** in total. The siding and the casing both stop dead at the
clear opening edge; the closed leaf laps onto each jamb casing by 1½". At the barn door's west
jamb the corner board stands in for the casing — same layer, same lap.

<!-- model trace: jamb layers outboard of the wall face: siding 0..0.75, casing 0.75..1.5,
planks 1.5..2.25, frame 2.25..3.0; casings z 0.5..84; leaf z 1..83.75; skirt band below,
z -6.75..0.5; cut height of the section, 40" above deck top, chosen clear of all of those -->

Fig 15.2 marks the frame: an elevation of the barn door zone with the cut line. Fig 15.3 is
the section that cut produces — the four layers, named, against the studs and the opening
behind them.

Fig 15.2 — Barn door zone of the front wall, elevation viewed from the street. Stage 12, doors hung. Cut line A–A marks the horizontal section shown in Fig 15.3, 40" above the deck.

Fig 15.3 — Section A–A, horizontal cut 40" above the deck, looking down from above. Stage 12, the jamb build-up. Four ¾" layers step out from the wall face to 3" proud; siding and casing stop at the clear opening and the closed leaf laps each casing 1½″.

Fit the latches on the three meeting stiles, then walk every leaf: it should swing freely, land
on its 1½" laps, and latch without lifting.

## Before you move on

- [ ] Every leaf's bottom edge 1" above the deck, top edge ¼" below the head — tape
- [ ] Every leaf laps its jamb casings 1½" on both sides (west barn leaf laps the corner
      board) — tape
- [ ] Each double meets with a ¼" centre gap — tape
- [ ] All hinges fixed at rail heights, straps on the leaf, screws in the casing face — look and try the swing
- [ ] Each opening's jamb reads four ¾" layers out to 3" proud — sighted across the jamb against Fig 15.3
- [ ] Every door swings freely and latches without lifting — by hand

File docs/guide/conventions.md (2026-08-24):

---
page: conventions
title: How this guide is drawn and written
prev: index.md
---

# How this guide is drawn and written

This page is the guide's own account of its rules — what a reader can rely on, and what a
maintainer must keep true when the guide changes. The pages are Markdown files in this
folder, one per page, with figures as SVG files beside them in `figures/`.

## Numbers

- Lengths are written **feet-inches-eighths**: 9' 7⅜", never a long decimal of inches.
- Heights are written **measured up from the deck top**, the guide's zero: "40 inches above
  the deck".
- Horizontal positions are written as **tape readings from a named physical mark**:
  "16 inches on centre, measured from the left end mark".
- Parts are written as **cut-list name, nominal size, cut length**: "rafter · 2×6 · 9' 7⅜\"".

Why no coordinates, ever: this guide is read outdoors with a tape in hand, and the building
has no axis system on it. Model coordinates are traceability between the guide and the model
code, not instruction. They live in non-rendering source comments in the page files (and in
the sources appendix), and never in text, captions, or figures. If you edit a page, keep it
that way.

## Figures

Every figure is a hand-drawn SVG in `figures/`, named `fig-<page number>-<slug>.svg`, and
follows these rules:

- **View badge, top-left, always.** Three facts: the view type word (ELEVATION, PLAN,
  SECTION, ISO); which way you look, in building terms ("viewed from the street"); and a
  frame anchor — a gravity arrow on elevations and sections, the cut height on plans and
  sections, an axis corner on ISO views. The symbol key on the start page shows the badge
  with its three fields labelled.
- **The drawing declares its own frame.** A reader must be able to tell which way a figure
  faces from the drawing alone, before reading a word of caption. Elevations and sections
  carry a ground or deck line and a gravity arrow; plans and sections carry hatched cut
  material and a labelled cut line whose source view is shown in a neighbour figure. A strip
  stack with no frame cues is the one unforgivable figure: an earlier version of this guide
  drew the door-jamb finish layers as bare parallel strips, and every reader's eye read them
  as vertical boards on an elevation, because nothing in the drawing said "you are looking
  down". The fix is structural — hatching, cut line, locator — not a louder caption.
- **Fixed cameras.** Whole-shed ISO views use one oblique camera: the front elevation drawn
  true, depth receding up and to the right at half scale, verticals vertical, viewed from the
  street with the right corner toward you (the finished-shed figure on the start page is the
  reference). One fixed elevation per wall, one fixed section plane per detail. If a view
  must change, the figure says so in words.
- **No part is drawn alone.** Every new member appears with at least two neighbours and one
  datum edge, coloured by state: new work full colour, already-built work grey outline,
  future work dashed.
- **Every new member gets an arrow to its seat**, and the attachment-mode symbol at the
  joint — nail pattern, screw, hinge, or seat cut. This building's parts fasten in different
  ways; "it's obvious where it goes" is not true here.
- **One figure, one message.** A zoom that carries the message is the figure; the wide view
  becomes a small locator.
- **Labels are leader lines** carrying the part name, nominal size and cut length.
- **Captions** carry: number, what the figure shows, view type, where in the build, and one
  takeaway sentence.
- **Site legibility.** Text in figures is at least 3 mm cap height at A4 print size, cut
  edges at least 0.5 mm line weight, high contrast for sunlight.

The **symbol key** (`figures/fig-00-symbol-key.svg`, shown on the start page) is the only
place symbols are defined. Use those marks; if a figure genuinely needs one the key lacks,
that is a note for the maintainers, not a quietly invented glyph.

## Pages

Each page is one Markdown file starting with front matter — `page`, `title`, `stage`
("Stage N of 12" on the twelve build stages only), and `prev` / `next` filenames following
the canonical reading order (start page → what you're building → the two order pages →
Stages 1–12 → troubleshooting → the two references). The `prev`/`next` links are written even
for pages that do not exist yet in your copy; they resolve once everything is together.

Body rules: one action per numbered step (a step containing "and then" is two steps); one
figure per step where a figure is warranted; safety messages at the exact step that carries
the hazard, in the warning format from the symbol key; and every page ends with a "Before you
move on" checklist whose checks name the tool that verifies them.

Tone: plain, direct, second person. "Set the skids", not "the skids should be set".

## The PDF for the job site

`build-pdf.sh` in this folder assembles the pages in canonical reading order into one PDF.
Prerequisite: **python3 with the standard library, and WeasyPrint** (the `weasyprint`
command, or importable by python3) — both already on this machine; nothing else is installed
by the script. Run it from anywhere:

    docs/guide/build-pdf.sh                 # writes docs/guide/build-guide.pdf
    docs/guide/build-pdf.sh out.pdf         # or a path of your choice
    PAPER=letter docs/guide/build-pdf.sh    # A4 is the default

Pages that do not exist yet are skipped with a warning instead of failing, so the PDF always
reflects what is written so far. On paper each page starts on a new sheet, figures never
split across a break, and text prints dark on white while the figure colour states keep
their colour (they carry meaning).

## What this guide does not cover

Wall sheathing, roofing, fasteners and paint are not modeled and are on neither lumber order.
The guide says so at the steps where it matters, and never invents quantities for them.

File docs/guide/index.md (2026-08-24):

---
page: P00
title: Start here
next: 01-what-youre-building.md
---

# Start here

This guide builds one shed: a 16 ft × 7 ft wood box with a single-slope roof, the tall
wall at the front, three door openings, lap siding, and board-and-batten doors. It rides
on two 16 ft skids bearing directly on a levelled, compacted gravel pad — no concrete, no
pedestals.
Twelve stages take you from bare ground
to hung doors. One page per stage, in build order. Read this page once, then work the
pages in order.

![Fig 0.1 — The finished wood bike shed. ISO view from the street, right corner toward you: 16 ft × 7 ft, single-slope roof falling to the back, an 8 ft barn door at the front wall's west corner and a 5' 4" brewery double on the right wall; the left wall (hidden here) carries the matching 5' 4" MAIN-entry double. This is what exists when Stage 12 is done — every page in this guide builds toward this one picture.](figures/fig-00-finished-shed.svg)

## The datum — read this before any page

- **The deck top is zero.** Every height in this guide is measured up from the top of the
  OSB deck, and says so ("40 inches above the deck").
- **The front is the street side and is the high side.** The roof falls from the front to
  the back. "Left" and "right" are as you stand in the street facing the doors.
- **Horizontal positions are tape readings from a named mark** — "16 inches on centre,
  measured from the left end mark" — never coordinates.
- Parts are named as on the order lists: cut-list name, nominal size, cut length
  ("rafter · 2×6 · 9' 7⅜\"").

## Before the stages

1. [What you're building](01-what-youre-building.md) — the shape, the sizes, the design decisions.
2. [Order: framing lumber and foundation](02-order-framing.md) — the framing shopping sheet.
3. [Order: finish lumber and hardware](03-order-finish.md) — a separate order; do not merge the two.

## The build, stage by stage

- [Stage 1 — Gravel pad and skids](04-blocks-and-skids.md): a levelled, compacted gravel pad across the footprint, with both skids bedded directly on it, square.
- [Stage 2 — Floor](05-floor.md): rims, joists, deck; the deck top becomes your datum.
- [Stage 3 — Front wall](06-front-wall.md): the tall wall with the barn door opening, framed flat on the deck.
- [Stage 4 — Back wall](07-back-wall.md): framed flat along the back edge, corners left open for the side-wall laps.
- [Stage 5 — Side walls](08-side-walls.md): the two rake walls, framed flat, each carrying its 5' 4" double — MAIN entry left, brewery right; all four walls now lie complete on the deck.
- [Stage 6 — Raise and brace](09-raise-and-brace.md): all four walls plumb, corners tied, braced.
- [Stage 7 — Rake plates](10-rake-plates.md): the sloped plates and stepped studs carry the roof line.
- [Stage 8 — Rafters](11-rafters.md): thirteen birdmouthed rafters seated on both plates.
- [Stage 9 — Fascia and roof edge](12-fascia-and-roof.md): fascia and rake boards; roofing is your own call.
- [Stage 10 — Skirt and siding](13-skirt-and-siding.md): the skirt sets the finish datum; siding goes on.
- [Stage 11 — Trim](14-trim.md): corners, frieze, casings, in that order.
- [Stage 12 — Doors](15-doors.md): six board-and-batten leaves in three doubles, hung on strap hinges.

## When it doesn't fit, and reference

- [If it doesn't fit — troubleshooting](16-troubleshooting.md)
- [Reference: cut list and stock packing](r01-cut-list.md)
- [Appendix: sources, verification, quirks](r02-sources.md)
- [How this guide is drawn and written](conventions.md) — for readers and maintainers.

## Safety, in four groups

The detailed warnings are printed at the exact step that carries the hazard — these four
groups are the shape of it.

- **Lifting.** The front wall stands 10 ft 3 in tall: two people minimum, every time.
  The 16 ft skids and 18 ft fascia are long and floppy; carry with help and keep fingers
  clear of bearing points.
- **Height.** Stages 7–9 put you ten feet and more above the deck. Firm ladder footing,
  three points of contact, and don't work alone overhead.
- **Cutting.** Birdsmouths, rake cuts and ripped courses mean long saw time. Eye protection
  always; clamp the work; know where the blade exits.
- **Ground work.** Digging and tamping the gravel pad is gloves-and-eye-protection work;
  crush the stone in lifts, and keep the pad edges from crumbling under your feet.

## Tools

One list for the whole build; each stage page repeats what it needs so you don't carry this
page up a ladder.

- Tape measure (25 ft) and a pencil
- Speed square and a 4 ft level
- String line — the screeded gravel pad, set to two string lines, brings both skids to one common plane, not levelled one by one
- Circular saw; a sharp handsaw or jigsaw for notches
- Drill/driver and a hammer
- Shovel and a hand tamper for the gravel pad
- Shims ½" and under
- Sawhorses and clamps for wall assembly
- A ladder that reaches past the front plate top

## How to read the figures

Every figure carries a **view badge** in its top-left corner with three facts: the view type
(ELEVATION, PLAN, SECTION or ISO), which way you are looking in building terms ("viewed from
the street"), and a frame anchor — a gravity arrow on elevations and sections, the cut height
on plans and sections, an axis corner on ISO views. Trust the badge before you trust your
first guess; the drawing is drawn to declare its own frame.

Members are drawn in three states: **new work in full colour, already-built work as a grey
outline, future work dashed.** No part is ever drawn alone — every new member appears with
neighbours and a datum edge, and an **arrow to its seat** with a symbol saying how it fastens
(nails, screw, hinge, seat cut). A **red crossed frame** shows a mistake to avoid; a **warning
triangle** marks a safety message.

Fig 0.2 — The symbol key. Reference chart, not a view of the building: the view badge, the three colour states, the attachment arrow, the attachment-mode symbols, the prohibition frame and the warning triangle. Learn these six marks once; every figure in the guide uses only these.

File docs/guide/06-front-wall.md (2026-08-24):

---
page: P06
title: Front wall (tall, barn opening)
stage: Stage 3 of 12
prev: 05-floor.md
next: 07-back-wall.md
---

# Stage 3 — Front wall (tall, barn opening)

> **Goal:** the tall front wall — 10' 3" from deck to plate top — lies assembled flat on the
> deck, with the one 8 ft barn opening framed: plates, kings, jacks, header and cripples all
> nailed off; east of the opening the wall is solid.
> **Crew:** 1 person (2 makes layout easier) · **Time:** about half a day · **Weather:** dry deck

<!-- model trace: front wall runs along x −3.5..188.5 at the street edge, wall depth y −3.5..0;
bottom plate z 0..1.5; top plate z 120..121.5; double top plate z 121.5..123;
barn opening clear x 0..96 (8', centre double door), head 84; header x −1.5..97.5,
underside z 84, top z 89, west end borne on the corner post; cripples z 89..120;
east of x 96 solid wall, kings at 16" oc -->

## Before you start

**Parts** (framing order, cut-list names):

| Qty | Part | Size | Cut length |
|---:|:---|:---|---:|
| 1 | front wall bottom plate | 2×4 | 16' 0" |
| 1 | front wall top plate | 2×4 | 16' 0" |
| 1 | front wall double top plate | 2×4 | 16' 0" |
| 8 | front wall king studs | 2×4 | 9' 10½" |
| 2 | front wall jack studs | 2×4 | 6' 10½" |
| 3 | front wall headers | 2×4 | 8' 3" |
| 5 | front wall cripple studs | 2×4 | 2' 7" |

- Deck is done (Stage 2). This wall is framed flat along the deck's **front edge — the street
  side** — bottom plate outer face flush with the deck edge. It goes up in Stage 6.
- All wall lumber is 2×4 KD SPF #2.
- The barn door's west jamb is the **corner**: the header's west end bears on the built-up
  corner post (corner king + corner jack), not on a jack-and-king pair like the east jamb.
  That is the flagged corner-bearing header of the door plan — frame it as drawn.
- **Fasteners are not modeled and not on either lumber order** — supply your own framing
  fasteners. No wall sheathing either: the lap siding (Stage 10) is the wall surface, applied
  straight over this framing.
- Tools: tape, pencil, speed square, saw, hammer or driver.

## Steps

### 1. Mark the bottom plate

Lay the 16' 0" bottom plate flat on the deck, square with the deck's front edge, outer face flush
with the edge. Hook your tape on the **left end — the end at your left as you face the shed from
the street** — and mark every position in the table. Each mark is the **left edge** of that
member; the member is 1½" wide, running to the right of its mark.

| Tape reading from the left end | Member |
|---:|:---|
| 0" | left-corner king stud — sits on the plate |
| 2" | corner jack stud — the corner post's front-face ply, sits on the plate |
| 99½" | barn opening jack stud — sits on the plate |
| 101" | king stud |
| 117" | king stud |
| 133" | king stud |
| 149" | king stud |
| 165" | king stud |
| 181" | king stud |
| 190½" | right-corner king stud — sits on the plate |

<!-- model trace: tape reading = model x + 3.5 -->

### 2. Set the jacks and kings

Set the studs on their marks, all on the same face line of the plate:

- The two 6' 10½" jacks (2" and 99½") on top of the plate, bottoms at the plate.
- The eight 9' 10½" kings on top of the plate — including both corner studs, flush with the
  plate ends.

Fasten each stud to the plate. The corner king and the corner jack together are the built-up
corner post the header's west end bears on.

### 3. Build the header on its bearings

The header is **three 2×4s cut to the same length**: two standing on edge, one flush with each
wall face, with the third lying flat across the top of both, capping them. Assembled, the header
is 5" tall and the full 3½" wall depth. Build it from the three 8' 3" pieces. Set it spanning the
opening on the corner post at the west and the east jack, bottom edge **84" up from the wall's
bottom edge — a 7' 0" head over the deck** — flush with the wall faces, and fasten it to the
jack and to the corner post.

Fig 6.1 — Front wall framing, elevation viewed from the street, assembled flat (Stage 3). The stud map: one 8' 0" barn opening at the west corner, header borne on the corner post, solid wall at 16" on centre east of it, heads 7' 0" above the deck.

Fig 6.2 — Header make-up, one door jamb in elevation from the street (Stage 3). Two 2×4s on edge at the faces plus one flat cap: three boards make the 5" header that seats on the jacks at the 7' 0" head line.

### 4. Add the cripples over the header

Mark the cripple left edges on the **top plate**, same tape readings from the left end: 18",
34", 50", 66" and 82". Set the five 2' 7" cripples between the header top and the top-plate
marks, and fasten both ends.

### 5. Nail on the top plate, then the double top plate

Lay the top plate over the stud ends, aligned with the bottom plate, and fasten it through into
every stud. Then lay the double top plate on top of it, full width, ends flush. The wall will be
10' 3" tall once it goes up. **Do not raise it yet** — all four walls are raised together, in
order, in Stage 6.

## Before you move on

- [ ] Diagonals of the flat wall equal within ½" — checked with the tape.
- [ ] The opening is 8' 0" wide between the corner post's inside face and the east jack face —
      checked with the tape.
- [ ] The header underside sits 84" up from the wall's bottom edge — checked with the tape.
- [ ] Every stud, jack, cripple and the header is fastened; the wall lies flat and square on
      the deck, ready to be raised in Stage 6.

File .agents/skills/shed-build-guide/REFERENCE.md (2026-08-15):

# Shed build guide — full reference

Companion to `SKILL.md`. The guide's own reader-facing statement of the same
rules is `docs/guide/conventions.md`; when the two ever diverge, that page is
what the reader sees, so reconcile it in the same change.

## 1. Figure specification

Figures are hand-authored SVG in `docs/guide/figures/`, named
`fig-<page number>-<slug>.svg`, referenced from their page as
`![Fig 4.1 — caption text](figures/fig-04-a.svg)`. They must stay legible at
phone size and printed on paper.

**P1 — View badge (mandatory, top-left of every figure).** Three fields: the
view type word (ELEVATION / PLAN / SECTION / ISO); the viewing direction in
building terms ("viewed from the street"); and the frame anchor — a gravity
arrow for elevations and sections ("DOWN"), the cut height for plans and
sections ("horizontal cut 40\" above deck"), an axis corner for ISO views.
The badge replaces the reader's assumption with a fact before the first
fixation lands on geometry.

**P2 — Anti-ambiguity rule.** The frame must be decidable from the drawing
alone, without the caption. Test: if the drawing still looks plausible after
swapping vertical with depth, it fails. Every elevation/section needs a
ground-or-deck line plus a gravity arrow; every plan or section needs hatched
cut material and a labelled cut line whose source view is shown in a
neighbouring figure. No naked strip stacks. See §2 for the failure this rule
exists because of, and §6 for the worked fix.

**P3 — Fixed camera.** One default oblique ISO for whole-shed figures (front
elevation drawn true, depth receding up and to the right at half scale,
verticals vertical, viewed from the street with the right corner toward you —
the finished-shed figure on the start page is the reference); one fixed
elevation per wall; one fixed section plane per detail. If a view must change,
say so in words on the figure ("now viewed from the left gable end"), with a
transition locator.

**P4 — Context rule.** No part is ever drawn alone. Every figure of a new
member shows at least two neighbours and one datum edge (deck edge, wall face,
plate top). Colour convention: **new work = full colour, already-built = grey
outline, future work = dashed.** Prior context stays visible; the attachment
point is never occluded.

**P5 — Attachment arrows.** Every new member gets an arrow to its seat or
attachment point, plus the attachment-mode symbol from the start page's symbol
key (nail pattern, screw, hinge, seat cut). A shed's parts fasten in different
ways, so "it's obvious where it goes" is not true here; structural diagrams
alone are invalid for this build.

**P6 — One figure, one message.** A zoom inset counts as a second figure: if
the inset carries the message, promote it to the figure and make the wide
view a small locator. No legend + plan + inset + notes stacks.

**P7 — Labels.** Leader lines carrying cut-list name + nominal size + cut
length (`rafter · 2×6 · 9' 7⅜"`). Never coordinates; the full number-writing
rules are in §4 below.

**P8 — Caption contract.** Number + what it shows + view type + where in the
build + one takeaway sentence. No coordinates in captions.

**P9 — Symbol key, defined once.** `figures/fig-00-symbol-key.svg` (shown on
the start page) is the only place symbols are defined: highlight colours,
grey/dashed states, arrows, the red circle+bar prohibition style for
error-state frames, the warning triangle. Use those marks; if a figure
genuinely needs one the key lacks, that is a note for the maintainers, not a
quietly invented glyph. No invented symbols where ISO 7010 ones exist.

**P10 — Full-size templates.** 1:1 printable profiles where a bevel or seat is
hard to measure: the birdsmouth, rake-plate seat angle, casing mitres. In the
PDF each prints 1:1 on its own zero-margin named page (the `figure.truesize`
mechanism in `assets/guide.css`); keep any new full-size template on that
mechanism.

**P11 — Site legibility.** Figure text at least 3 mm cap height at A4 print
size (4 mm for phone-at-arm's-length); cut edges at least 0.5 mm line weight;
high contrast for sunlight.

**P12 — Redundancy for critical messages.** Anything safety-critical appears
in at least two channels: symbol + text, figure + embedded warning.

**P13 — Error-state frames.** Crossed-out frames in the prohibition style at
the failure points this build actually has: pedestal not under the skid
bearing point, jack stud on the wrong side of the plate, rafter seated on one
plate only, siding course started without the skirt.

## 2. The failure that motivated the spec

An earlier revision of the single-page guide (the lineage now kept read-only
at `docs/build-guide.html`) drew the door-jamb finish layers as one wide wall
band plus four parallel strips stacked outward, each a tall rectangle, under a
title that called it a section. Its projection mapped model depth onto the
horizontal axis and height onto the vertical — but nothing in the drawing said
so: no gravity or ground cue, no cut indicator, no locator, no viewing
direction. The word "section" appeared only in the title; the caption led with
layer names and model coordinates.

The composition is frame-ambiguous by construction: a wall band plus parallel
strips looks identical as an elevation (strips = vertical boards across the
wall), a section (strips = layers through the wall) or a plan (the same strips
from above). The reader's canonical default — boards standing vertical — wins,
exactly as reported from the job site: the frame error was invisible until the
text was found and read.

A later redraw moved in the right direction — the title said "plan view",
OUTSIDE/INSIDE arrows and an inset with legend appeared — but still failed:
the frame declaration lived in small text the reader had to hunt for; the
caption and note lines still rendered model coordinates; one figure carried
plan + inset + legend + notes, four messages at once; and the plan strip still
read as an elevation at first glance because nothing in the drawing plane
itself said "you are looking down" — no cut line, no hatching, no locator.

The lesson, encoded in P1/P2/P6: caption-only framing cannot fix a
frame-ambiguous drawing, because readers glance at figures while holding the
work, not paragraphs. The correction must be drawn — hatching, cut line,
locator, gravity arrow — and it must precede reading.

## 3. Page format

Each page is one Markdown file in `docs/guide/`, starting with exactly this
front matter shape, then the body:

```markdown
---
page: P04
title: Pedestals and skids
stage: Stage 1 of 12
prev: 03-order-finish.md
next: 05-floor.md
---

# Stage 1 — Pedestals and skids

> **Goal:** what exists when this page is done, in one sentence.
> **Crew:** 1 person · **Time:** about half a day · **Weather:** dry ground

## Before you start

... parts tick-off table, tools, safety for THIS page ...

## Steps

### 1. <One action, imperative>

...text... plus its figure

## Before you move on

- [ ] check with the tool that verifies it
```

Body rules:

- **One action per numbered step.** If a step contains "and then", split it.
- **One figure per step** where a figure is warranted.
- Safety messages go at the **exact step** that carries the hazard, not
  collected at the top. Format:
  `> ⚠️ **WARNING** — <hazard> · <consequence> · <how to avoid>`.
- Every page ends with a "Before you move on" checklist of verifiable
  completion checks, each naming the tool that checks it ("diagonals equal
  within ½\", checked with a tape").
- `stage:` runs "Stage N of 12" across the twelve build-stage pages only; the
  other pages omit the field.
- `prev:`/`next:` follow the canonical order below and are written even when
  the neighbouring page does not exist yet in the working copy.

Canonical reading order (use these exact filenames):

| Order | File | Page |
|---|---|---|
| 1 | `index.md` | Start here |
| 2 | `01-what-youre-building.md` | What you're building |
| 3 | `02-order-framing.md` | Order: framing + foundation |
| 4 | `03-order-finish.md` | Order: finish + hardware |
| 5 | `04-blocks-and-skids.md` | Stage 1 |
| 6 | `05-floor.md` | Stage 2 |
| 7 | `06-front-wall.md` | Stage 3 |
| 8 | `07-back-wall.md` | Stage 4 |
| 9 | `08-side-walls.md` | Stage 5 |
| 10 | `09-raise-and-brace.md` | Stage 6 |
| 11 | `10-rake-plates.md` | Stage 7 |
| 12 | `11-rafters.md` | Stage 8 |
| 13 | `12-fascia-and-roof.md` | Stage 9 |
| 14 | `13-skirt-and-siding.md` | Stage 10 |
| 15 | `14-trim.md` | Stage 11 |
| 16 | `15-doors.md` | Stage 12 |
| 17 | `16-troubleshooting.md` | If it doesn't fit |
| 18 | `r01-cut-list.md` | Reference: cut list |
| 19 | `r02-sources.md` | Reference: sources |

Adding a build stage means a new numbered page in this chain with updated
`prev`/`next` on its neighbours, figures prefixed with the page number, and
the stage count reviewed. Walls are framed flat on the deck (Stages 3–5) and
raised in Stage 6 — keep that sequencing straight in any summary text.

**Tone:** plain, direct, second person. "Set the pedestals", not "the
pedestals should be set". Short sentences. No coordinate-speak, no CAD vocabulary, no
marketing. The reader is competent with tools but has not built this shed
before.

## 4. Numbers — full rules

- **NEVER render model coordinates in visible text or captions.** No
  `z = -6.75"`, no `(y -3.5...-4.25)`, no `x 15.5...51.5`, no bare decimals
  like `22.773"`.
- Traceability goes in a **non-rendering HTML comment** in the Markdown
  source: `<!-- model trace: siding y -3.5...-4.25; casing -4.25...-5.0 -->`,
  and in the sources appendix page.
- Lengths render as **feet-inches-eighths**: `9' 7⅜"`, not `115.344"`.
- Heights render as **measured up from the deck top**, the guide's zero:
  "40 inches above the deck", never "z 40".
- Horizontal positions render as **tape readings from a named physical mark**:
  "16 inches on centre, measured from the left end mark".
- Parts are named **cut-list name + nominal size + cut length**:
  `rafter · 2×6 · 9' 7⅜"`.

Why, in one line: the reader builds with a tape, and the building has no axis
system on it; split-attention research says the number belongs on the part,
where a coordinate would be noise.

## 5. Sourced principles behind the rules

The method is distilled from instruction-design standards and research; each
rule above traces back to this material. Verification levels from the
original research: FULL = source read in full, SNIPPET = excerpt only.

### 5.1 The governing standard — IEC/IEEE 82079-1:2019

"Preparation of information for use (instructions for use) of products"
explicitly covers products "ranging from a tin of paint to … buildings", so a
shed is squarely in scope ([ISO catalog 71620](https://www.iso.org/standard/71620.html)).
Clauses the guide leans on (clause content via free previews and
committee-adjacent secondary sources; the body text is paywalled):

- **5.3** seven information-quality principles: completeness, minimalism,
  correctness, conciseness, consistency, comprehensibility, accessibility.
- **7.12** instructions for assembly of self-assembly products.
- **8.3.3** leading criteria — tasks ordered "by the order in which tasks are
  performed" (the page chain follows build order); **8.3.4** step-by-step
  structure = preliminary information → instructional steps → completion
  information (the page template's three blocks).
- **9.10** legibility incl. minimum font sizes; **9.11.4** illustration with
  captions (the caption contract).
- The 2012 predecessor gives two rules quoted by number: **6.1.6** "one
  sentence, one command" and **6.3.4** "one illustration, one item of
  information" (one action per step; P6).

Adjacent standards: **ISO 20607:2019** (machinery handbooks; the 4-part
warning formula signal word + hazard + consequence + avoidance — the guide's
warning format); **ANSI Z535.6** (safety messages placed at the exact step);
**ISO 3864 + ISO 7010** (safety colours and signs; red circle+bar =
prohibition, the grammar of the error-state frames); **ISO/IEC Guide 37**
(never rely on one medium for a crucial safety message — P12). A Part 2
dedicated to self-assembly is in development (BSI project 9025-12059); its
scope statement is the closest official definition of this guide's reader: "a
non-skilled target audience assembling a product without help from a trainer
or supervisor".

### 5.2 IKEA — borrow the visual grammar, keep the text

IKEA's instruction designers ("communicators") work to "clarity and
continuity" and **test-assemble the product themselves first** to catch
mistakes that only bite many steps later
([Fast Company](https://www.fastcompany.com/3052604/how-ikea-designs-its-infamous-instruction-manuals), FULL).
Documented conventions: wordless steps with **text reserved for safety**
(verified on a real manual — the only extractable text is a tip-over WARNING);
fixed single viewpoint "mimicking that of the customer"; one action per step;
**crossed-out error frames** ([Frixione & Lombardi](https://link.springer.com/article/10.1007/s13164-014-0216-1));
finished-product "promise" page first (the start page's finished-shed figure).

IKEA's own preconditions for going wordless: fewer than ~100 parts, exactly
one correct assembly path, purely sequential steps. **This shed violates all
three** (293 modeled parts, weather/site judgement, tolerances) — hence text
stays, for safety and one-time operations.

### 5.3 LEGO — delta highlighting, fixed camera, symbols

From LEGO's own history and convention documentation: the **fixed viewpoint**
predates digital tools (step photos shot "exactly on the same spot as the
previous one"); **delta highlighting** — new parts in full colour, prior build
muted (P4); **step-inventory callouts**; an **official symbol set** (P9);
**1:1 templates** for length-ambiguous parts (the precedent for P10); and
error-tolerant step ordering — where error is possible, limit its consequences
to non-critical/aesthetic ([LEGO history](https://www.lego.com/en-us/history/articles/d-lego-building-instructions-through-time),
[BrickNerd](https://bricknerd.com/home/how-lego-instructions-have-changed-over-time-a-forest-of-discovery-10-17-22),
[BricksFanz](https://bricksfanz.com/a-guide-to-lego-instructions-symbols/),
[Brickset](https://brickset.com/article/110723/the-simplification-of-the-lego-building-experience-what-s-up-with-that), all FULL).

### 5.4 Comprehension research — the strongest sources

Two Stanford papers on flat-pack furniture assembly with adults, the closest
published analog to this shed:

- **Agrawala et al., "Designing effective step-by-step assembly instructions",
  ACM TOG (SIGGRAPH)** ([PDF](https://graphics.stanford.edu/papers/assembly_instructions/assembly.pdf), FULL):
  step-by-step beats single all-operations diagrams; one significant part (+
  its fasteners) per diagram; **visibility is "perhaps the strongest design
  principle"** — new part visible, prior context visible, future parts not
  occluded; density balance; reorient only at stable, physically realizable
  poses (build flat, then stand up — the walls workflow).
- **Heiser et al., AVI** ([PDF](https://graphics.stanford.edu/papers/assembly_instructions_study/assemblyuserstudy_hires.pdf), FULL):
  seven validated principles — one diagram per major step; explicit
  numbering/order; parts added in each step visible; **attachment mode
  visible**; action diagrams over structural diagrams; consistent arrow
  semiotics; **avoid changing viewpoints**. Instructions built on these cut
  assembly time ~35% and errors ~50% (n=30). Users **never read text
  explanations while holding the product** — words must be glance-able.
  Crucial caveat: LEGO-style structural diagrams suffice only *because every
  LEGO part attaches the same way*; a shed has nails, screws, hinges,
  birdsmouth seats, mitres — hence P5. In the same study the single
  exploded-view condition failed: participants couldn't see where parts
  connected.

Orientation and projection misreading (the P1/P2 evidence base): **Shepard &
Metzler** — mental-rotation cost scales with angle, so viewpoint changes are
real cognitive work; **Palmer, Rosch & Chase** and **Blanz, Tarr & Bülthoff**
— readers carry canonical preferred views (oblique-from-above beats pure
top/side/front); **Van Den Einde et al., ASEE** ([abstract](https://peer.asee.org/41636))
— novice orthographic-projection errors cluster in top views, alignment and
orientation. Design for the lower half of the spatial-ability distribution: in
the Heiser study, diagrams by low-spatial-ability authors produced 86%
ordering errors vs 12% for high. **Gap, stated plainly:** no published
experiment directly tests "reader treats a plan view as an elevation" — the
§2 mechanism is inferred from this body of work.

Figure–text coupling: **Mayer & Moreno** split-attention effect (the number
belongs on the part); **Moreno & Mayer** contiguity; **Paivio** dual coding;
**Levie & Lentz** — representational illustrations facilitate learning,
decorative ones do not.

One-off builds: **Menn et al., SEFI** ([PDF](https://www.sefi.be/wp-content/uploads/2017/09/54394-JP.-MENN.pdf), FULL)
adapts kit-style instructions to one-of-a-kind production and adds what kits
never need — escalation/troubleshooting pages, per-step tool/time/headcount,
checkpoints, tick-off checklists (the troubleshooting page and page furniture
come from here). **Söderberg et al., Chalmers** ([full text](https://publications.lib.chalmers.se/records/fulltext/202981/local_202981.pdf)):
with the original instructions, 67% of builds missed a part and 49% misplaced
a subassembly; many assemblers **stopped reading and used only the final
finished-product picture**. The IKEA effect (Norton et al.) supplies the
stakes: the emotional payoff requires successful completion — an unrecoverable
instruction error destroys it.

### 5.5 What does NOT transfer from mass-kit design

| Kit convention | Why it exists there | Verdict for this one-off shed |
|---|---|---|
| Fully wordless steps | One booklet, 25+ languages, translation cost | **No** — one reader, one language; text is free and needed for safety |
| Identical part-count callouts ("x2") | Factory-counted identical bags | **Partial** — callouts from the cut list, paired with a cut/spare note for wood waste |
| 1:1 scale of factory hardware | Identical stamped fittings | **Partial** — no hardware to match, but 1:1 *profiles* of birdsmouths/angles transfer (P10) |
| Pre-drilled hole patterns | CNC consistency | **No** — layout is dimensioned from named datums instead |
| No troubleshooting pages | The kit is deterministic | **Inverted** — the shed NEEDS escalation pages (warped stock, out-of-square box) |
| Bag-break pacing | Physical bags | **As analog** — end each page at a structurally stable, weather-safe stopping point |
| Illustration templates reused across products | Thousands of identical products | **No** — one shed; but reuse within the guide (four walls share a layout pattern) |

## 6. Worked example: the door-jamb finish build-up

Content (facts from the model): at a 36" door jamb the finish steps outward in
four ¾" layers — 1×8 lap siding on the wall face → 1×6 jamb casing on the
siding face → door planks on the casing face → 1×4 leaf frame outboard; 3"
proud of the wall face in total. Siding and casing stop at the clear opening;
the leaf laps each jamb casing 1½". Presented per spec, this becomes **two
coupled figures**, not one packed figure.

### Fig. A — elevation locator (declares the frame the section will be cut from)

```
 [ELEVATION · front wall door zone · viewed from the street · DOWN ↓]

   plate top ─────────────────────────────────────────────
                  │ siding │             │casing│
   frieze ════════╪════════╪═════════════╪══════╪═════════
                  │        ┌─ head casing ─┐     │
                  │        │ ┌───────────┐ │     │
                  │        │ │ door leaf │ │     │ ← leaf laps
                  │        │ │ (closed)  │ │     │   casing 1½"
                  │        │ └───────────┘ │     │
   ═══════════════╪═════CUT═══A════════A═══╪═════╪═════  40" above deck
   deck ──────────┴────────────────────────┴─────┘
   ▼ DOWN (gravity)          deck = height datum for the whole guide

   Cut line A–A is horizontal. Fig. B shows this cut, LOOKING DOWN.
```

Why this figure exists: it makes the section's frame self-evident before the
reader ever sees it (P2); it shows the layers in situ with neighbours (P4);
the deck line + gravity arrow make the vertical frame undeniably vertical.

### Fig. B — section A–A (the four ¾" steps, frame declared twice)

```
 [SECTION A–A · horizontal cut 40" above deck · looking DOWN from above]

                      OUTSIDE (yard)
   ┌─────────────────────────────────────────────────────┐
   │▓▓▓ 1×4 leaf frame · ¾" (outermost of the 4 layers)  │
   ├────────────────────────────────────┬────────────────┤
   │▓▓▓ door planks · ¾"                │ stile (edge    │
   ├──────────────────────┬─────────────┤ of the leaf)   │
   │▓▓▓ 1×6 jamb casing·¾"│             │                │
   ├──────────────┬───────┤    CLEAR    │                │
   │▓▓ 1×8 lap    │ 2×4   │    OPENING  │                │
   │   siding · ¾"│ wall  │     36"     │                │
   │              │framing│             │                │
   └──────────────┴───────┴─────────────┴────────────────┘
                      INSIDE (shed)

   ▓ = material cut by the A–A plane (section hatching)
   jack + king studs sit in the wall behind the casing — grey
   "already built" context, not part of this figure's message

   wall face ◄─ +¾" siding ◄─ +¾" casing ◄─ +¾" planks ◄─ +¾" frame
   ⇒ 3" proud of the wall face · siding & casing stop at the clear
     opening · the closed leaf laps each casing 1½"
```

Production notes: cut material hatched per section grammar (hatching is itself
an anti-ambiguity device — elevations don't hatch); leader-line labels with
cut-list names (P7); running dimension chain at the bottom; grey = already-built
framing (P4). Where four thin bands must be shown at page scale, draw them
exaggerated with a stated scale note — as the whole figure, not an inset
within a plan (P6). The model trace goes in a non-rendering comment, e.g.
`<!-- model trace: siding y -3.5...-4.25; casing -4.25...-5.0; planks -5.0...-5.75;
frame -5.75...-6.5; cut at 40" above deck -->`.

Why this beats the failed figure: (1) the frame is declared by the drawing
itself — locator cut line + hatching + "looking DOWN" badge + deck/gravity
anchor — so the default-to-vertical error is corrected before any text is read;
(2) coordinates stay traceable in source comments, invisible in rendering;
(3) two figures, one message each; (4) the neighbour context (jack/king studs,
opening, leaf) is present, so the layers read relative to the building rather
than as abstract blocks; (5) the takeaway dimension (3" proud) is a drawn
chain, not prose.

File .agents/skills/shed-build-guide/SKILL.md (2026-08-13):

---
name: shed-build-guide
description: Authoring method for the woodbike-shed build guide — page format, number-writing rules, figure conventions, and the checks every change must pass. Use when writing or editing a page of the shed build guide, drawing or revising a figure for it, adding a build stage, or reviewing guide changes.
---

# Shed build guide — authoring method

The guide lives in `docs/guide/`: one Markdown file per page, SVG figures in
`docs/guide/figures/`, assembled into a job-site PDF by `docs/guide/build-pdf.sh`.
Its reader-facing statement of the rules is `docs/guide/conventions.md`; this
skill is the maintainer's copy of the method, and `REFERENCE.md` beside this
file carries the full figure specification, the page template, the sourced
principles behind each rule, and the door-jamb worked example. Read it before
any non-trivial change.

The reader builds outdoors, tape in hand, possibly from a paper printout.
Everything below serves that reader.

## Sources of truth

Guide numbers come from the model, never invented: `cad/*.py` + `cad/verify.py`,
`CUT_LIST.md`, `order_list.csv`, `order_list_finish.csv`. If a page disagrees
with the model, fix the page. Wall sheathing, roofing, fasteners and paint are
NOT modeled and are on neither lumber order — say so where it matters and never
invent quantities for them.

## Workflow

1. Read `docs/guide/conventions.md`, the page or figure you are changing, and
   its neighbours — the prev/next chain must stay intact.
2. Take every number from the sources of truth above.
3. Write to the page template in `REFERENCE.md`, or draw to the figure spec
   there, applying the two rules below as you go.
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

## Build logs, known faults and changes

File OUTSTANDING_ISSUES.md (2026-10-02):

# Outstanding issues

Open items for the bike shed BOM / cut list before submitting quotes.
Regenerated 2026-08-07 against the completed model (120 parts; rake walls,
rafters and roof trim finished, all parts named). 2026-08-10: captain's
ordering decisions applied locally (this branch); the Onshape model still
carries the pre-decision geometry (zero API calls).

## Front roof overhang 24" -> 12" — APPLIED (2026-10-02), one open question

Captain 2026-10-02: shorten the roof's leading edge rather than move the
building — 12" overhang on all four sides — so the roof edge clears the
town's 10 ft distance from the house (firstmate
`data/shed-site-plan-7ft/report.md`, option C: position A failed by 7-1/2"
at the fascia face with the 24" tail; the 12" tail passes by about 4-1/2",
before drip edge). Applied locally by `scripts/front_overhang_12.py` (its
docstring is the derivation record): front rafter tail y -27.5 -> -15.5,
rafters and rake boards 128.16" -> 115.344" (9' 7-3/8"; 10 ft stock now,
was 12 ft, 4-5/8" of trim allowance per board), front fascia top / peak
137.687 -> 133.187 (11' 1-3/16" above the deck), roof plan 18' x 9' 3".
Walls, pitch, seats, back and side overhangs unchanged.

- **OPEN — weather cover over the front barn door.** The front eave is now
  12" out and about 4 ft above the 84" door head, so it no longer shelters
  the 8 ft outswing barn leaves or their head casing from wind-driven rain
  (24" barely did). No head flashing / drip cap is modeled or on either
  order for any of the three doors. Captain's call: add a drip cap
  (Z-flashing) over the door head casings to the builder-scope list, or
  accept as is.
- Note: the 12" is the rafter tail; the fascia face stands 13-1/2" off the
  front wall (same convention as the back), and drip edge / roofing add
  roughly another inch — tape the house distance from the finished edge.

## Stock availability — RESOLVED (2026-08-10, Hingham Lumber)

- **16' 2x4 stock**: Hingham Lumber stocks it — KEEP. The optimizer selects
  32 × 16' 2x4 KD boards (five 192" plates + one 185" plate force 16'
  stock). If a future yard lacks it, re-run `scripts/build_cut_list.py`
  with 192 removed from `STOCK_LENGTHS["2x4"]` to see the 14'/12' fallback.

- **20' 2x6 stock (fascia)**: Hingham Lumber stocks true 20' 2x6 — ORDER
  TRUE 20'. The two 216" (18') front/back fascia take one 20' board each.

## Waste / overage factor — RESOLVED (2026-08-10)

ORDER EXACT quantities (0% overage); the captain plans a follow-up order
for shortages. order_list.csv carries no waste factor by design.

## Stud pre-cuts — RESOLVED (2026-08-10)

SWITCHED to standard 92-5/8" pre-cut studs for the back, left, and right
walls; wall height dropped 3/8" (97.5" -> 97-1/8"). Applied locally by
`scripts/restud_92_5_8.py`, which re-derives every dependent value from the
constraint chain (roof plane pivots about the unchanged front wall; rake
studs, rafters, fascia and cripples follow — see the script docstring and
the 2026-08-10 commit for before/after dims). The Onshape model still has
the 93" studs; sync it (or not) is a future captain call.

## Skid redesign — continuous 16' lines (2026-08-10 captain's decision)

The sistered skid arrangement is DROPPED: each skid line is now ONE
continuous 16' (192") 4x4 (two total, full shed length x = -3.5..188.5), on
the audited composite-skid lines under the front/back wall bearing lines
(y -3.5..0 and 77..80.5, z -9.75..-6.25, since the 7 ft depth). Hingham
stocks 16' 4x4; PT ground-contact tagging unchanged. **Deliberate divergence
from Onshape**, whose model keeps the sistered composite skids (4x 96"
boards + 2x 48" sisters); the local model, cut list and order list carry the
redesign.

**Foundation, 2026-08-24 — piers/pedestals DROPPED.** This supersedes the
StrataRise pedestal revision. The two continuous skids bear DIRECTLY on one
compacted ¾" crushed-stone gravel pad screeded level across the whole
16′ × 7′ footprint — no pedestals, no paver base pads, no shims. Model, cut
list, and the guide's Stage 1 (gravel pad and skids) all carry it; the
pedestal order lines are removed. The pad footprint/spec is stated on the
P04 foundation page because the landscaper excavates it before any lumber
arrives.

## Treatment & species

Currently tagged:
- **PT (pressure-treated, ground-contact)**: all 2x6 floor system (rim
  joists + floor joists) and all 4x4 skids
- **KD (kiln-dried, framing grade)**: all wall and roof lumber
- **OSB**: 3/4" structural, subfloor-rated

Species decisions:
- KD framing: **SPF #2** — decided; recorded in order_list.csv notes.
- PT ground contact: **CLOSED — captain 2026-08-24, permanently.** There is no
  choice: order whatever the yard stocks (ground-contact rated). This question
  is never to be re-opened.

## Doors / siding / trim — separate order list — RESOLVED (2026-08-10)

Captain's call: model doors/siding/trim for real, but order them on a
COMPLETELY SEPARATE order list — never mixed into this framing lumber list.
Implemented on branch fm/woodbike-shed-siding-model: `cad/siding.py`,
`cad/trim.py`, `cad/doors.py` (real dimensioned parts in scene.glb + per-part
STEP + view.py sections), ordered via `order_list_finish.csv` and the FINISH
sections of CUT_LIST.md (`scripts/build_finish_cut_list.py`). Hardware
(strap hinges, latches) stays line items only.

## Rafter bearing vs front-wall double top plate — RESOLVED

The rafters' bearing line (captain's `Rafter Right` sketch) sits at z=121.5"
on the front wall while the double top plate tops out at z=123". Fixed with
**birdsmouths** on every rafter: front seat cut flat at z=123" over the
plate width (heel at y=−4.06"), and a matching back seat at z=97.5" over the
back wall plate (plumb kick at y=68.5") where the tails dipped below the
plate top. Rafters now bear flush on both double top plates; verified by
`scripts/audit_overlaps.py` (zero lumber-on-lumber overlap). The local
build123d model carries the same birdsmouths as exact profile prisms
(2026-08-10; seats/kicks derived from the plate solids, re-derived for the
92-5/8 restud: front seat z=123" heel y=-4.0", back seat z=97.125" plumb
kick y=68.5"), guarded by the `cad.verify` seating + zero-interference
checks.

## Known intentional overlaps (left as modeled)

- The `inner volume` reference envelope pre-dates the roof; the rafters
  pass through its upper zone. Reference body only — excluded from the cut
  list, no action.
- (2026-08-23: the as-designed opening-A jacks and tall king that ran
  from z=0 through the front bottom plate were retired by the door-plan
  reframe — every new jack/king sits on the plate, and `cad.verify`'s
  ALLOWED_OVERLAPS exemption no longer matches anything.)

## Door plan — adopted 3-door plan (captain 2026-08-23, left MAIN door added 2026-08-24)

Verdict (durable copies in firstmate data/shed-door-plan-model/
captain-decision-2026-08-23.md and data/shed-guide-depth-pass/
captain-decision-2026-08-24.md): adopt the free-doors study's WINNER
(firstmate data/shed-jenga-arrange/report.md) MODIFIED — the 3 ft walk-in
is REMOVED — and then ADD the LEFT rake-wall 64 in double as the MAIN
(primary pedestrian) door. Model + audit JSON updated 2026-08-23 by
`scripts/depth7ft_2door.py` (7 ft depth + barn + right brewery) and
2026-08-24 by `scripts/left_main_door.py` (the left MAIN door, an exact
mirror of the right brewery double).

- **Barn door 8 ft (96 in)**, front wall west end, clear 0-96, head 84 —
  wheeled roll-out (bikes + blower) and slab carry-in on edge. The west
  jamb IS the corner: the header bears on the corner king + a corner jack
  in the corner block (the built-up header-bearing corner post; flagged not
  engineered in the study). East of the opening the front wall is solid
  studs at 16" oc.
- **MAIN entry double 64 in**, LEFT rake wall, clear 6.5-70.5, head 84,
  6.5 in end studs. The shed's everyday pedestrian door — closest to the
  garage/access. Exact mirror of the right brewery double's framing
  (jacks, header plies + cap, cripples, mitered header cripples).
- **Brewery double 64 in**, RIGHT rake wall, clear 6.5-70.5, head 84,
  6.5 in end studs (the study's flagged minimum).
- **Walk-in / slab-feed door REMOVED.**
- **7 ft shell**: back wall out to y 77..80.5, plate tops at 92-5/8 (the
  restud slope 24.375/65 is exactly the 7 ft slope 28.875/77). Where the
  roof drops below the flat plate stack, the gable ends follow it: the
  flat DTP runs to y 60.73 and the top plate to 64.73, mitered studs carry
  the rake plate to the back corner, and side DTP corner blocks carry the
  corner rafters' back seats (all derived in the script's docstring).

**Door roles** (recorded everywhere in the guide): LEFT double = MAIN
entry; front 8 ft barn = wheeled roll-out + slab carry; RIGHT double =
brewery service. Recorded in the fit check:

- `scripts/fit_study_free_doors.py --arrange winner2` (the free-doors
  study adapted for the adopted plan; the original arrangements still run
  unchanged) — full record in `scripts/fit_summary_winner2.txt`: every
  named check PASS, "everything fits with access kept":
  - pedestrian entry through the LEFT MAIN door (64 in vs the 36 in
    minimum), entry landing + maneuver floor clear to 48 in;
  - slabs carried on edge through the barn door (96 in ≥ 28 in slab +
    18 in carrier), aisle 49 in ≥ 46, rack feed face 23.75 in at the east
    end of the run (≥ 21 in as-designed precedent);
  - unchanged from the winner: bikes + blower straight-roll under the run,
    brewery service from outside the 64 in door (6.5 in end studs), hood +
    duct + panel checks;
  - left-door sanity suite (end studs, outswing leaves stay exterior, entry
    landing clear) matches the checks the winner-render scout validated
    (firstmate data/shed-blender-winner/report.md).

## Plywood lean-to relocation — FOLLOW-UP (2026-08-24)

The plywood lean-to run planned against the LEFT wall must RELOCATE: the
left wall now carries the MAIN entry double, so the lean-to cannot stay
where it was. The family has accepted the relocation. Choosing the new
spot is NOT part of the door/depth task — open it as its own decision when
the interior arrangement is next revisited.

## Rake studs

Left and right rake-wall studs are now real parts, one unique length each:
22.77", 16.96", 10.96", 4.96" (re-derived 2026-08-10 from the 24.375/65
restud slope; the 93-stud 22.40/16.68/10.77/4.86 lengths and the April
22.40/16.49/10.59/4.68 lengths are superseded). Short enough to cut from
scrap / off-cuts if managed on-site.

## Onshape model cleanup

- All 40 formerly default-named parts are renamed (front wall, back-wall
  studs, rake studs, rafters). Zero `Part NN` remain.
- The 4 unnamed solid **bodies** inside the two multi-body `skid` parts
  remain unnamed (they are sub-bodies, not parts — nothing to rename).
- `"inner volume"` remains excluded from the cut list; confirmed reference
  only (interior clearance envelope).
- The captain's 20 broken tail features (rake-wall/rafter chains) were
  **deleted 2026-08-08** with his go-ahead; the feature tree is fully green
  (119 features, zero errors). Diagnosis record: `MANUAL_COMPLETION.md`.

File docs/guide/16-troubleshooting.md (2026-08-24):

---
page: P16
title: If it doesn't fit — troubleshooting
prev: 15-doors.md
next: r01-cut-list.md
---

# If it doesn't fit — troubleshooting

> **Goal:** when a part fights you, find the likely cause, fix it to a stated tolerance, or make the honest call and recut the part.

Kit instructions never need a page like this, because a kit is deterministic. A shed built
from real lumber on real ground is not. Wood crowns, ground settles, tapes sag. Work each
entry the same way: read the symptom, check the likely cause against what you actually see,
then fix it — and where the fix says recut, recut. Forcing a bad part in with more fasteners
is how a shed starts to leak and rack.

The crossed-out frames on this page show the **error state** — the red ring and bar mean
"what you must not ship." Where a fix has a number, that number is the tolerance; past it,
the part or the assembly is wrong, not the measurement.

## 1. Crowned or warped stock

**Symptom.** A board bows along its length (crown), twists like a propeller, or bows across
its width. A crowned stud will not sit flat between its plates; a twisted rafter rocks on
its seats.

**Likely cause.** Kiln-dried stock moves after it leaves the kiln, and it moves more if it
was stacked flat in the sun or banded tight off a wet pile. The defect was probably in the
board when you bought it.

**Fix.** Sight down every board over the top edge before it is cut — crown up to ¼″ over
8′ is usable in horizontal members (crown up, load flattens it) and in studs if **all the
crowns face the same side** of the wall, so the siding plane stays true. More than ¼″, or
any twist you can rock on a flat bench, is not a part: recut it into a shorter piece the
cut list actually needs (cripples, rake studs, pier siding), or reject it. Quantities carry
no overage, so the honest cost of a bad board is a trip to the yard — which is why you
check boards in the yard, on the pile, before they are loaded.

## 2. Floor diagonals not equal

**Symptom.** The two tape readings corner-to-corner across the skid or floor rectangle
disagree by more than ½″.

**Likely cause.** One skid line slid along its length, the rims were nailed to joists cut or
set off layout, or the rectangle got shoved while the deck went on.

**Fix.** Measure both diagonals the same way, hook to hook. Push the corner at the end of
the **long** diagonal toward the short one until the two readings agree within ½″, then
re-nail and brace. Do this at the skids (Stage 1) and again at the deck — an out-of-square
floor telegraphs into every wall and the roof, and no later stage fixes it. If the readings
still disagree after the frame is eased, pull the corner nails and check the joist and rim
cuts against the list; a board cut more than ½″ off its length gets recut, not shimmed.

Fig 16.1 — Plan of the skid rectangle, looking down from above, drawn out of square: the two tape diagonals disagree. Ease the long corner over until both readings match within ½″; checked at Stage 1, before any wall goes up.

<!-- model trace: skid lines y -3.5...0 and y 77...80.5, x -3.5...188.5; the skids bear
directly on the screeded, compacted gravel pad — no piers, no shims; deck top 9¾" above the
pad top; error state drawn with the front skid line shifted 4" along its length (exaggerated) -->

## 3. A wall that will not come plumb

**Symptom.** After raising, the level or plumb bob shows the wall leaning, and pulling the
braces will not bring it in — or it goes plumb at one end and out at the other.

**Likely cause.** In order of likelihood: the gravel pad under the skid is not level — a soft
spot or a screed miss — so the deck edge follows the pad instead of the bubble; one crowned
or long stud is holding the wall off line; a brace is anchored to something that moves; the
wall is twisted along its length because its two ends are plumb to different marks.

**Fix.** Work from the ground up. The skids bear directly on the screeded, compacted gravel
pad, and this foundation carries no shims — the gravel is the shim. If a deck edge is off,
lift that skid line, add or strike compacted gravel under it, re-screed and re-set; the deck
top sits 9¾″ above the pad top when the skids are bearing everywhere. Then plumb off the
**double top plate**,
not the studs, with the braces set at about 45° to solid deck blocking. A wall that is
plumb at both ends and bowed between has a bad stud: sight it, and recut or sister it.
Tolerance: no gap over ⅛″ under a 6-ft level laid on the wall face, in both directions,
before the next wall ties into it. The siding is the wall surface on this shed, so a racked
wall is a wavy wall you will see forever.

## 4. Rafter seats gapping on one plate

**Symptom.** A seated rafter shows a gap under one birdsmouth — usually the back seat —
while the other bears. A feeler or a saw blade slides in under the seat. The rafter may
rock when you push on the tail.

**Likely cause.** The birdsmouth was cut from the wrong line on the pattern rafter, the
pattern itself was cut off the plate height, or the plate it should bear on is high (a
double top plate lap that did not close, a wall left proud). One crowned rafter in thirteen
can also show this at one seat only.

**Fix.** First check the plates, not the rafter: both double top plate tops must be the
bearing lines, and a lap that did not close makes a high spot every rafter repeats. If the
plates are right, the rafter is wrong: recut the shallow seat or cut a new rafter from the
pattern. Do not wedge a shim into a structural seat and call it bearing. Tolerance: nothing
thicker than 1/16″ under either seat, checked rafter by rafter at Stage 8. The verify gate
on this model checks every seat face flat on its plate — the built shed gets the same
check, with a feeler.

Fig 16.2 — Section through one rafter at the back wall, viewed from the right gable end: the birdsmouth bears on its inner edge only and the seat gaps off the plate. Every seat bears full-width; checked with a feeler at Stage 8.

<!-- model trace: back DTP top z 92.625 at y 77...80.5; correct seat horizontal at z 92.625
with plumb kick at y 80.5 down to z 91.3125; error state drawn with the seat tilted 1" open
at the kick (exaggerated) -->

## 5. Finish layers not sitting flush

**Symptom.** A finish layer — siding on framing, trim on siding, door planks on casing,
leaf frame on planks — rocks when you press it, or shows a wedge of daylight behind one
edge. Each layer is meant to back flat on the face of the one behind it, ¾″ proud, all the
way along.

**Likely cause.** The face behind is not in one plane: a crowned stud under the siding, a
siding course that did not seat in its rabbet, a casing nailed over a high corner board, or
a twisted board in the layer itself. The build-up is four ¾″ steps, so one high spot two
layers down shows as a rocking layer now.

**Fix.** Find the high spot before adding fasteners — press the board and read the gap,
then trace it back layer by layer to the first proud face. A crowned stud gets recut or
relieved; a siding course that did not nest gets lifted and re-set in its rabbet; a twisted
finish board gets replaced, primed stock is cheap compared to a wavy door. Tolerance: a
layer bears along its full length with no gap over 1/16″. Never spring a board flat with
screws — the stress lives in the joint forever and the fastener backs out.

## 6. Siding courses not matching across the rake

**Symptom.** On a side wall the top courses do not land parallel to the rake line: a course
pokes past the rake, or a wedge of gap opens between the top course and the rake board that
the frieze will not cover. Courses on the two side walls also fail to line up with each
other at the corners.

**Likely cause.** The wall's courses were started from a different mark than the other
walls (deck instead of skirt top, or a skipped course), so the 7″ exposure stack arrives at
the rake line off; or the rake-cut top course was cut square and left to stick out instead
of being ripped to the slope.

**Fix.** All four walls start their first course at the same mark — tucked behind the skirt
top — at the same 7″ exposure, so courses meet level at every corner board. Where the rake
crosses a course, that course is ripped or sloped to butt tight under the course above and
tight to the rake line; the frieze and casings cover a tight joint, not a wedge. If a wall
arrives at the rake a half-course off, do not stretch or squeeze the exposure to hide it —
pull that wall's courses back to the skirt and re-run them. Tolerance: a rake-cut course
sits tight to the rake board with no gap over ⅛″, and courses from adjacent walls meet
within ⅛″ at the corner.

Fig 16.3 — Elevation of the left side wall, viewed from outside with the front (high side) at right: a top course left square pokes past the rake line instead of being ripped to it. Courses start at the skirt top on every wall; checked as the courses climb at Stage 10.

<!-- model trace: left wall face x -3.5; siding 7" exposure from skirt top z 0.5; rake cut
line = rafter bottom + 1" tuck (z 92.3 at back rising 4.5:12 to z 123.8 at front); skirt
z -6.75...0.5; error state drawn with the top course 2" past the rake at the back corner
(exaggerated) -->

## Before you move on

- [ ] The symptom that sent you here is gone, and the tool that checks it says so: tape, level, feeler, or story pole — not eye.
- [ ] Any part you recut was recut to a cut-list length, not trimmed until it "looked right."
- [ ] Nothing was shimmed past ½″, sprung flat with fasteners, or wedged into a bearing seat.
- [ ] If the honest call was a second trip to the yard, you made it.

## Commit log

2026-04-13 Initial commit: Onshape API tooling for bike shed BOM
    - scripts/onshape.py: signed-request helper for Onshape REST API v6
    - scripts/fetch_bboxes.py: concurrent per-part bounding box fetch
    - scripts/verify_groups.py: group parts by name and flag dimension variance
    - README + .gitignore (credentials stored outside repo)
2026-04-14 Add cut list, stock optimizer, and outstanding issues doc
    - CUT_LIST.md: full builder-facing cut list grouped by shed section
    (skids, floor, walls, rake walls, roof) with PT/KD treatment and
    stock-length optimization via FFD bin packing with per-bin rightsizing
    - order_list.csv: quote-ready rollup for lumber yards
    - OUTSTANDING_ISSUES.md: open items before quoting (14' stock availability,
    consider longer 2x4 stock vs 8', 20' fascia sourcing, waste factor,
    pre-cut studs, species/grade, Onshape model cleanup)
    - scripts/fetch_oriented_dims.py: FeatureScript eval for true oriented
    bounding boxes — correct for tilted parts (rafters, fascia, rake plates)
    - scripts/build_cut_list.py: en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
    [order_list.csv]
2026-08-08 Finish mid-refactor: rake walls + rafters, part renames, regenerated cut list
    Onshape restore version taken first: aa73830b88f34f965190a7c6
    ("pre-fleet-completion 2026-08-05", microversion 57d4bf70f01d28ed9e043878).
    Model (Onshape doc 24d3743de768051f7ae10bb3, Part Studio 1, Main):
    - Diagnosis: the captain's tail features (Frame 64..71 chains) dangle on a
    deleted sketch (FrZYFpgdFKjya90_36), dead front/back-wall imprint chains
    and four deleted mate connectors. In-place repair of ~45 compressed
    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
    [order_list.csv]
2026-08-08 Roof trim: fascia + rake boards, restoring the April left/right roof extension
    Follow-up to the captain's confirmation that the mid-refactor also extended
    the roof left/right and added fascia — that work was visible in the broken
    tail features (Frames 68-71 + Transform 5 + Move face 13 with a 12" offset)
    and in the April roof (2 fascia 2x6x216" = shed + 2x12", 2 rake boards
    2x6x115.13"). The deleted mate-connector rig kept exact placement
    unrecoverable, so the package is rebuilt additively, April-consistent:
    - front/back fascia: 2x6 x 216" (12" past each side wall), tops flush
    with the rafter tails
    - left/right rake boards: 2x6 x 115.13", along the slope just outside the
    end rafters
    -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
    [order_list.csv]
2026-08-08 Rake boards end-to-end; fix fascia to symmetric 12" overhangs
    Per captain: rake boards run all the way to the roof ends — extended from
    the rafter tails (y=-27.5..80.5) to the fascia outer faces (y=-29..82),
    now 2x6 x 118.32" each. Also corrected the fascia placement: the first
    pass offset them 14" from the right plane (10"/14" overhangs); they now
    sit at x=-15.5..200.5, 12" past each side wall as intended.
    MANUAL_COMPLETION.md geometry reference updated; CUT_LIST/order_list
    regenerated (roof KD order unchanged: 15x10' + 2x20' 2x6).
2026-08-08 Move rake boards to the roof overhang edges (flush with fascia ends)
    Per captain's sketch: the rake boards belong at the outer ends of the roof
    overhang, not beside the end rafters. Now flush with the fascia ends:
    left x=-15.5..-14, right x=199..200.5, still running end-to-end
    (y=-29..82, 118.32"). MANUAL_COMPLETION.md geometry reference updated.
2026-08-08 Overlap fixes: rafter birdsmouths, rake boards butt to fascia, plate noses trimmed
    Added scripts/audit_overlaps.py (analytic X-prism intersection sweep; touching
    parts read 0). It found and I fixed all lumber-on-lumber interference:
    - rafters: birdsmouth front (seat z=123, heel y=-4.0625) and back (seat
    z=97.5 over y=65..68.5) so they bear flush on both double top plates
    - rake boards: butted to fascia inner faces (back to 115.13") so the
    fascia stays unbroken; still flush with the fascia ends at the overhang
    - left rake plate nose trimmed in its sketch; captain's right rake plate
    nose trimmed by a scoped REMOVE feature (boolean scope = plate body only)
    Remaining audit hits are intent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
2026-08-08 Add scripts/render_model.py: CLI software 3D renderer (PIL, no Blender)
    Projects the same X-prism solids used by audit_overlaps.py with a
    yaw/pitch orthographic camera, painter's algorithm + flat shading.
    Renders committed: iso-front, iso-back, roof-top.
2026-08-08 build_report: draw sloped members as true profiles in elevations
    The side-wall elevations previously drew the rake plate/studs as world-bbox
    rectangles (a solid band), which read as nonsense. Sloped members now render
    as their exact YZ profiles (parallelogram rake plate, mitered studs).
2026-08-08 Refresh feature list dump from live model; note featureStates API
    Re-pull of scripts/featurelist_dump.json (139 features, sourceMicroversion
    75ed0337831d755732fa8042) taken during the 2026-08-08 verification pass:
    model unchanged (120 parts, 0 default names, bboxes/oriented dims identical,
    overlap audit clean except documented quirks, cut list regenerates with zero
    diff). featureStates in the GET-features response confirms exactly 20 ERROR
    features at indices 100-119; 98-99 are live and build the right rake plate.
    AGENTS.md: add the featureStates/eval-API sharp edges; correct the tail
    index range (100-119, not 98-119).
2026-08-08 Delete the 20 broken tail features per captain's go-ahead
    Deleted feature indices 100-119 (Frame 64 ... Frame 71 chains: rake-wall
    studs, left rake wall, rafters, roof-trim rig) via DELETE
    .../features/featureid/{fid} in reverse tree order. Indices 98-99 (right
    rake wall sketch + Frame 63) were kept - they are live and build the right
    rake plate.
    Verified after: 119 features all OK (featureStates), 120 parts with names
    intact, bboxes byte-identical, oriented dims identical, overlap audit
    unchanged (only documented intentional quirks), CUT_LIST.md / order_list.csv
    regenerate with zero diff.
    Pre-deletion microversion 75ed0337831d755732fa8042 recorded here as the
    fallback anchor (the create-v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
2026-08-08 Pilot: convert right rake wall studs to constraint-driven sketch
    Captain directed relationship-based modeling (constraints to existing
    geometry, absolutes only at critical anchors) over absolute-coordinate
    sketches, so design changes propagate down the chain.
    Mechanism proven via API: a sketch line constrained COINCIDENT to a solid
    face solved to that face exactly (control run with a dead face query
    stayed at drawn position). Faces are picked with
    qContainsPoint(qEverything(EntityType.FACE), point) - qPlanarFace doesn't
    exist and frame-feature faces aren't attributable via qCreatedBy.
    Converted in place: sketch FqDfLcBqgGzsYjO_103 (44 constraints, was 0) -
    stud bottoms coincident to the do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
2026-08-08 Model-as-code rebuild: build123d shed model, STEP + Blender exports
    Re-derives the full bike shed (133 parts, 41 cut-list names) as build123d
    code from the repo's own audit data (oriented_dims.json + bboxes.json) with
    zero Onshape API calls. One module per shed section; every part labeled with
    its exact CUT_LIST.md name. Exports: per-part STEP in step/, one named
    scene.glb in blender/ (glTF keeps per-part names selectable in Blender).
    cad/verify.py is the assertion harness (coverage, per-part dims + volume vs
    oriented_dims.json, placement vs bboxes.json) - run after every change; it
    exists because silent boolean no-ops are the failure mode that bit the
    stack-selection smoke test.
    Stack pin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
    [001 skid.step, 002 skid.step, 003 skid.step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]
2026-08-08 Sync rebuild to the regenerated audit data now on main
    Main advanced to 31c7c63 while this branch shipped: the model was completed
    (rafter birdsmouths, roof trim, renames) and scripts/oriented_dims.json +
    bboxes.json + CUT_LIST.md were regenerated (134 -> 122 entries). Updates:
    - section modules + label mapping follow the new cut-list names ("rafter",
    "front fascia"/"back fascia", "king studs", consolidated plates, rake
    studs without the "(different heights)" suffix)
    - fascia are axis-aligned since the upstream roof-trim rework (drop the
    roll-about-X placement)
    - pitch anchors to the documented 24/65 slope; the AABB solve becomes a
    sanity check (trimmed rafter ends skew the naive so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
    [001 skid.step, 002 skid.step, 003 skid.step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]
2026-08-09 Blender render pipeline: build_scene.py, saved scene, 1080p Cycles renders
    Headless-reproducible: imports blender/scene.glb, assigns PBR wood materials
    by cut-list name group, adds ground/sun/sky + 4 saved cameras, renders
    Cycles 1920x1080 into blender/renders/. README documents regeneration and
    the material mapping. No Onshape calls; GPU (OptiX) with CPU fallback.
    [shed_scene.blend]
2026-08-09 Add view.py: one-command OCP CAD Viewer entry point
    Builds the full cad/ model and sends it to the OCP CAD Viewer with a
    part tree that mirrors CUT_LIST.md (one group per section via the
    cut-list classifier, real cut-list labels). Guarded ocp_vscode import
    with a VS Code / ~/.venvs/woodbike-shed hint; ocp_vscode stays a
    viewer-side extra, documented in README instead of requirements.txt.
    Verified headless: model builds (121 parts, 9 sections, grouping
    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
2026-08-09 Blender group colors: 8 distinct wood tints + legend, regenerated renders
    Annotated-product-shot palette: one muted wood hue per structural group
    (skids olive, PT floor amber, OSB deck gold, studs pale blond, plates/headers
    honey, rafters cedar red, fascia driftwood gray, rake boards rosewood plum),
    splitting the old framing/trim buckets. Legend in blender/README.md; blend
    and all four 1080p Cycles renders regenerated.
    [shed_scene.blend]
2026-08-10 Blender skin mode: dressed presentation renders (siding, trim, doors)
    --skin layers render dressing over the framing per the captain's
    reference: blue-gray lap siding, white corner boards/casings/frieze/
    skirt, barn-red plank doors with strap hinges + latch on each framed
    opening (front single + double, right single), natural-wood roof deck
    with exposed rafter tails. Geometry derives from the imported part
    bboxes; scene.glb and the framing/colorized modes stay untouched.
    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
    [shed_skin.blend]
2026-08-10 Apply 2026-08-10 captain's decisions: 92-5/8" restud + order list calls
    Geometry (the only geometry change; zero Onshape API calls):
    Back/left/right walls switch from 93" studs to standard 92-5/8" pre-cut
    studs. Wall height drops 3/8" (97.5" -> 97-1/8"). The front wall is
    unchanged, so the roof plane re-derives about the unchanged front
    reference. scripts/restud_92_5_8.py rewrites the audit JSONs from the
    documented constraint chain (self-checked: the same formulas with the old
    constants reproduce the old audit data within ~0.2 mm audit noise), then
    cad/ rebuilds STEP + scene.glb from them and cad.verify passes.
    Before/after for every changed dim/reference (inches):
    part / reference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
    [001 skid.step, 002 skid.step, 003 skid.step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]
2026-08-10 Birdsmouth seats flush: parametric profile prisms + skid redesign
    The rectangular-stock rebuild silently lost the audited birdsmouths: every
    rafter interpenetrated the front double top plate by up to 1.500" and the
    back by up to 1.292" (diagnosis + fix spec: firstmate report
    woodbike-shed-birdsmouth-scout/report.md). Rafters, rake boards, rake
    plates and rake studs are now exact YZ-profile prisms (cad/common.py
    prism_yz + roof_ref), with every roof number DERIVED from the plate solids
    (seat plane = plate top; heel/kick = bottom edge x plate faces) so
    wall-height edits propagate. Skids per captain's 2026-08-10 redesign: two
    continuous 16' 4x4 lines on the audited composite lines, sisters drop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
    [001 skid.step, 002 skid.step, 003 rim joist.step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]
2026-08-10 view.py: tint part groups with the shared Blender color legend
    The OCP CAD Viewer showed all 117 parts in one color; the captain wants
    distinct group hues. The MATERIALS palette + group_for map moved from
    blender/build_scene.py into bpy-free blender/group_colors.py; view.py maps
    each part's base tint onto build123d .color, so viewer and Blender renders
    agree. Verified with an ocp_vscode stub: 117 parts, 9 sections, 8 distinct
    group colors reach show(); headless build_scene.py still saves the scene.
    [shed_scene.blend]
2026-08-10 Finish lumber as real parts: siding/trim/doors + separate order list
    Captain 2026-08-10: model doors/siding/trim for real, on a completely
    separate order list. cad/siding.py (1x8 lap courses, rabbet-nested in one
    plane, rake-cut tops), cad/trim.py (skirt, corner boards, frieze, door
    casings), cad/doors.py (board-and-batten leaves over all three framed
    openings: front single + center double, right single) - 176 new parts,
    all heights derived from the audit bboxes + roof_ref via
    common.finish_layout. scene.glb carries them as their own tree sections
    (view.py Finish siding/trim/doors), per-part STEP 118-293, verify.py
    extends its volume/layer/envelope/zero-interference gates to them.
    Ordering: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
    [118 finish siding front.step, 119 finish siding front.step, 120 finish siding front.step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]
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2026-08-13 Add guide pages P13-P15: skirt and siding, trim, doors with coupled jamb section figures
2026-08-13 Guide integration: consistency pass over assembled pages
    - index.md: Stage 3-5 blurbs corrected to 'framed flat' (punch list; walls
    are raised in Stage 6)
    - P01: through-plate king stud is beside opening A's right jack, not the
    left corner (matches P06 and the model)
    - P16: figures renumbered sequential in page order (16.1 floor diagonals,
    16.2 rafter seat gap, 16.3 rake courses)
    - R01: right wall bottom plate long 1' 2-1/2 -> 1' 8-1/2 (cut list 20.5)
    - index.md figure style normalised to 'Fig N.M'
    - page endings normalised: dropped divergent footer/trailer link lines so
    every page ends with its Before-you-move-on checklist
    - checklist items capitalised uniformly on P13-P15
2026-08-13 Guide integration: figure inspection fixes
    - fig-13-a: 'course 1 - finish siding' leader pointed into the grey wall
    framing; re-aimed at the siding board
    - fig-05-a: skid and back-rim labels were overprinted by the joists;
    white halo behind both, skid label moved above the joist layer
    - P09 Fig 9.2 caption said 'viewed from the street' while the badge (and
    the drawing) is an end view from the wall's left end; caption corrected
2026-08-13 Guide integration: PDF assembler fixes
    - build-pdf.sh: join figure refs wrapped over source lines; 21 figures
    were rendering as literal markdown text and missing from the PDF
    - build-pdf.sh + guide.css: the birdsmouth template (Fig 11.3) prints on
    its own named page with zero margins at true 1:1 size; previously the
    text column's max-width shrank it to 87% (4" check line measured 3.49")
    - .gitignore: ignore the generated build-guide.pdf
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2026-08-13 fig-15-c: clear the three label collisions flagged on review
    - DOWN-into-page symbol+text moved fully clear of the view-badge box
    - rotated 3-proud dimension label given its own right-edge column
    - four layer leaders re-aimed at monotone target points so the fan runs
    parallel without crossings; 1-1/2 lap text shifted clear of them
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2026-08-13 Add shed build-guide authoring skill at .agents/skills/shed-build-guide
    Distils the proven guide-authoring method — page template, number-writing
    rules, figure spec with the anti-ambiguity test, sourced principles and the
    door-jamb worked example — into a repo skill so future guide work keeps the
    same standard without rediscovering it. .claude/skills is a symlink to
    .agents/skills, mirroring CLAUDE.md -> AGENTS.md. AGENTS.md gains a
    pointer.
2026-08-13 docs: publish the build guide as a GitHub Pages site
    docs/ becomes the Pages source (native Jekyll build, minima theme):
    - _config.yml: baseurl /woodbike-shed, jekyll-relative-links rewrites the
    guide's .md links and figure refs; defaults give guide pages the
    _layouts/guide.html prev/next pager without touching their front matter
    - _layouts/landing.html + index.md: site root renders the Start Here body
    - assets/main.scss: minima with phone-daylight overrides (18px body,
    self-scrolling tables, viewport-scaled figures)
    - footer keeps the retired single-page build-guide.html reachable
    Verified locally with the github-pages gem (232) and a chromium pass:
    inter-page links resolve, figures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
2026-08-15 docs: foundation revision — StrataRise 3560ML-DF-30 pedestals replace Tuff Blocks
    Stage 1 rewritten for the captain's 2026-08-14 design: compacted gravel ->
    paver base pad -> StrataRise adjustable support pedestal (3560ML-DF-30) at
    the same eight support points. Leveling simplified: the pedestal's
    adjustment ring (1 3/8"-2 3/8") replaces block shimming; skids fasten via
    the head's fixing flange. Deck-above-grade restated from the pedestal's
    real adjustment range (deck top 11 1/8"-12 1/8" above the paver pads).
    Figs 4.1/4.2 redrawn (plan keeps the eight positions with new hardware
    symbols; section shows soil/gravel/paver/pedestal/skid with the ring,
    flange and 3x-vertical note). Figs 1.1,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
2026-08-24 model: 7 ft depth + captain's 2-door plan (barn 96in front, 64in right rake; walk-in removed)
    - scripts/depth7ft_2door.py: one-shot audit-JSON migration applying the
    2026-08-18 7 ft depth decision and the 2026-08-23 door verdict (free-doors
    study winner minus the walk-in); self-checking, idempotent; docstring is
    the derivation record (gable ends follow the roof past the flat plate
    stack: mitered studs + DTP corner blocks; barn header borne on the
    built-up corner post; 6.5in rake-wall end studs).
    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
    [001 skid.step, 002 skid.step, 003 rim joist.step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]
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2026-08-24 wip: build-final pass (incomplete - firstmate offline)
    [001 skid.step, 002 skid.step, 003 rim joist.step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]
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2026-10-02 model+docs: front roof overhang 24 in -> 12 in (12 in on all four sides)
    Captain 2026-10-02: shorten the roof's leading edge instead of moving the
    building, so the roof edge clears the town's 10 ft distance from the house.
    - scripts/front_overhang_12.py: one-shot audit-JSON migration (self-checking,
    idempotent). Front rafter tail y -27.5 -> -15.5; rafters and rake boards
    128.16 -> 115.344 in (9 ft 7-3/8 in); front fascia y -17..-15.5, top/peak
    137.687 -> 133.187 (11 ft 1-3/16 in above the deck); roof plan 18 ft x 9 ft 3 in.
    Walls, pitch, seats, back and side overhangs unchanged.
    - Regenerated: CUT_LIST.md, order_list.csv (2x6 KD 15 x 12 ft -> 15 x 10 ft),
    roof STEP files, scene.gl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
    [108 rafter.step, 109 rafter.step, 110 rafter.step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]
